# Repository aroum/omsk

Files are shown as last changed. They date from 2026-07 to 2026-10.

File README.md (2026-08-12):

# OMSK




OMSK is an experimental, pocket-sized hardware platform designed primarily (but not exclusively) for custom synthesizer firmware development. Built around the RP2350-Zero microcontroller module, OMSK packs an exceptional density of tactile controls, audio routing, and visual indicators into a highly portable footprint.

## Hardware Features

- **MCU:** RP2350-Zero module (or RP2040-Zero)
- **Controls:**
  - 4x4 matrix of Kailh Choc v2 mechanical switches (supports hot-swap sockets)
  - 4 rotary encoders (Alps EC12)
- **Display:** 128x64 OLED screen (supports SH1107 or SSD1312 via I2C)
- **Visuals:** 22 addressable RGB LEDs (WS2812B MINI-E) for parameter tracking and custom animations
- **Audio & Connectivity:**
  - Built-in mono PWM audio output (with optional onboard headphone amplifier circuit)
  - Classic hardware MIDI In/Out jacks (TRS Type A)
  - USB MIDI class-compliant device interface
  - Support for an optional external PCM5102 I2S DAC for high-fidelity stereo audio

For more details on assembly, schematic routing, and BOM, see the [Hardware PCB Guide](hardware/pcb/README.md) and [3D Case/Enclosure Design](hardware/case/README.md).

## Bare-metal Software

All official firmware is written in pure C/C++ using the native Raspberry Pi Pico SDK. There is no Arduino overhead and no RTOS, ensuring maximum CPU availability, bare-metal performance, and sub-millisecond audio and MIDI latency.

### Architecture

Rather than compiling a single monolithic application, OMSK uses separate firmware files for different applications. This separation is dictated by hardware memory limits and fundamental architectural differences:

- Synthesizer engines require different memory structures (e.g., flash space allocated for wavetables and filter LUTs vs. granular sample buffers).
- Audio paths, envelopes, and modulation matrices differ completely between engines.

All firmware targets share a unified low-level core library located in [firmware/shared](firmware/shared), but compile as independent binaries.

> [!NOTE]
> Each firmware folder contains its own documentation and parameter reference: see the respective `README.md` (e.g., [omsk_fm/README.md](firmware/omsk_fm/README.md)) and the `docs/` directory for detailed configuration options (e.g., [omsk_fm/docs](firmware/omsk_fm/docs)). Shared hardware pinouts and peripheral configurations are defined in [firmware/shared/hw_config.h](firmware/shared/hw_config.h) (see [firmware/shared/README.md](firmware/shared/README.md)).

### Firmwares

Explore the firmware directory at [firmware](firmware) to flash any of the following targets:

- **[omsk_wave](firmware/omsk_wave):** A polyphonic wavetable synthesizer featuring deep modulation routing, resonant filters, and non-volatile patch storage.
- **[omsk_grain](firmware/omsk_grain):** A 4-voice granular synthesizer offering real-time grain manipulation, modulation matrices, and full MIDI control.
- **[omsk_fm](firmware/omsk_fm):** An FM (Frequency Modulation) synthesizer engine.
- **[omsk_tracker](firmware/omsk_tracker):** A pocket music tracker and step sequencer to compose patterns and songs directly on the device. [planned]
- **DMK:** A customizable mechanical macropad firmware featuring full Vial compatibility. Remap keys, layout layers, macros, and rotary encoder actions directly from your web browser.
- **[omsk_midi](firmware/omsk_midi):** A simple demonstration firmware that configures the device as a class-compliant USB/TRS MIDI controller.
- **[omsk_oled_test](firmware/omsk_oled_test):** A diagnostic utility to test OLED display functionality, address configuration, and graphics rendering.

Both synth engines support full MIDI CC mapping and preset saving directly to the onboard non-volatile memory.

## Desktop Simulators & Tools

The [`desktop`](desktop) directory contains Python-based software simulators, hardware emulators, and firmware development utilities managed via [`uv`](https://github.com/astral-sh/uv):

- **[`desktop/grain_simulator`](desktop/grain_simulator):** PySide6 GUI simulation of the OMSK Granular Synth engine (`omsk_grain`).
- **[`desktop/synth_simulator`](desktop/synth_simulator):** PySide6 GUI simulation of the OMSK Analog/Wavetable Synth engine (`omsk_synth`).
- **[`desktop/synth_tools`](desktop/synth_tools):** Firmware LUT header generators, hardware emulators (128x64 OLED display, 4x4 matrix keypad), and interactive web testbenches.

Quick launch:

```bash
cd desktop
uv sync
uv run synth_simulator/main.py
```

For more details, see the [Desktop README](desktop/README.md).

## Roadmap & Status

This project is currently a work in progress.

- **Hardware:** Case and knob designs are being actively iterated.
- **Software:** A dedicated web-based editor using WebMIDI is planned to allow quick parameter tweaking, firmware updates, and preset backup/sharing.

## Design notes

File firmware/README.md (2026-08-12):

# Firmware Overview (`firmware`)

This repository contains the firmware source code for the OMSK hardware platform (RP2040 / RP2350 microcontrollers).

## Project Structure

- **`omsk_wave/`**: 4-voice hybrid polyphonic synthesizer firmware (wavetable, Moog filters, step sequencer, FX).
- **`omsk_fm/`**: 6-operator Frequency Modulation (FM) synthesizer firmware compatible with DX7 SysEx patches.
- **`omsk_grain/`**: 4-voice granular synthesizer firmware with custom sample engine.
- **`omsk_midi/`**: USB/Hardware MIDI interface and router firmware.
- **`omsk_oled_test/`**: Minimal test utility for I2C OLED display initialization, alignment, and u8g2 graphics driver verification (SSD1312 / SH1107).
- **`shared/`**: Common hardware drivers, pinout definitions (`hw_config.h`), library code, and submodules shared across all firmwares.

---

## Prerequisites & Dependencies

### System Dependencies

To compile firmware for RP2040 / RP2350, you need the ARM GCC toolchain along with the C standard library (`newlib`), CMake, and build tools.

#### macOS (Homebrew)

> [!IMPORTANT]
> Make sure to install `arm-none-eabi-newlib`. Without it, GCC will fail with `stdint.h: No such file or directory` error when compiling C standard headers.

```bash
brew install cmake ninja arm-none-eabi-binutils arm-none-eabi-gcc arm-none-eabi-newlib
```

#### Ubuntu / Debian

```bash
sudo apt update
sudo apt install cmake gcc-arm-none-eabi libnewlib-arm-none-eabi build-essential
```

### Submodules & Pico SDK

Before building any firmware, ensure the repository submodules (such as TinyUSB, u8g2, CMSIS-DSP, etc.) are fully initialized.

Clone with submodules:

```bash
git clone --recursive https://github.com/aroum/omsk.git
```

Or if you have already cloned the repository without submodules:

```bash
git submodule update --init --recursive
```

Make sure you have the **Pico SDK** installed and `PICO_SDK_PATH` set in your environment:

```bash
export PICO_SDK_PATH=/path/to/pico-sdk
```

---

## Memory & Binary Formats (`.uf2` vs `.bin` / `.elf`)

To synthesize high-quality audio, this project relies heavily on pre-calculated Look-Up Tables (LUTs), audio samples, and wavetables stored directly in Flash memory. As synth engines evolved (e.g. granular synthesis with PCM sample data), Flash memory space on the RP2350 Zero (4 MB limit, non-expandable due to compact QFN packaging and pin count constraints) became scarce.

Standard `.uf2` files add significant block header overhead (nearly doubling the file size compared to raw binaries). By switching from drag-and-drop `.uf2` flashing to flashing raw `.bin` or `.elf` binaries directly via [`picotool`](https://github.com/raspberrypi/picotool), **~1.4 MB of Flash space is freed up**, allowing almost **twice as many audio samples, LUTs, and wavetables** to fit into internal storage.

---

## Flashing & Tools

### Installing `picotool`

`picotool` allows flashing `.bin` and `.elf` binaries directly over USB without requiring drag-and-drop or external HW debuggers.

#### macOS

```bash
brew install picotool
```

#### Ubuntu / Debian

```bash
sudo apt install picotool
```

---

## Building & Flashing

Each firmware folder contains its own dedicated build script (`build_all.sh`) supporting clean builds, memory analysis, platform selection (`rp2040` / `rp2350`), and automated flashing via `picotool`.

### Option 1: Flashing via `build_all.sh` (Recommended)

Run the script with the `-f` (or `--flash`) flag. The script will automatically trigger a soft reboot to BOOTSEL mode via USB CDC (1200 baud) and upload the `.bin` binary:

```bash
cd firmware/omsk_wave
./build_all.sh -p rp2350 -c -s -f
```

#### Script Flags & Options:

- `-c`, `--clean`: Remove build directory and re-run CMake configuration from scratch.
- `-s`, `--size`: Print detailed Flash and RAM memory usage report after build.
- `-p <platform>`: Target MCU platform (`rp2040` or `rp2350`, default is `rp2350`).
- `-f`, `--flash`: Flash binary directly to connected device using `picotool`.

### Option 2: Flashing Manually via `picotool`

1. Connect your RP2040 / RP2350 board in **BOOTSEL mode** (hold the `BOOT` button while plugging in USB, or press `RESET` while holding `BOOT`).
2. Flash the binary file (`.bin` or `.elf`) and automatically execute/reboot:

```bash
# Flash .bin file and execute
picotool load build_rp2350/omsk_wave.bin -u

# Or flash .elf file directly
picotool load build_rp2350/omsk_wave.elf -u
```

---

### Build & Flash Examples

Build **`omsk_wave`** for RP2350 and flash to hardware:

```bash
cd firmware/omsk_wave
./build_all.sh -p rp2350 -c -s -f
```

Build **`omsk_fm`** for RP2040 and flash:

```bash
cd firmware/omsk_fm
./build_all.sh -p rp2040 -s -f
```

Build **`omsk_grain`** for RP2350:

```bash
cd firmware/omsk_grain
./build_all.sh -p rp2350 -c -s
```

Build **`omsk_midi`**:

```bash
cd firmware/omsk_midi
./build_all.sh -p rp2350 -c -s
```

Build OLED display test utility:

```bash
cd firmware/omsk_oled_test
./build.sh
```

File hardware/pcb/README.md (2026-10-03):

# PCB

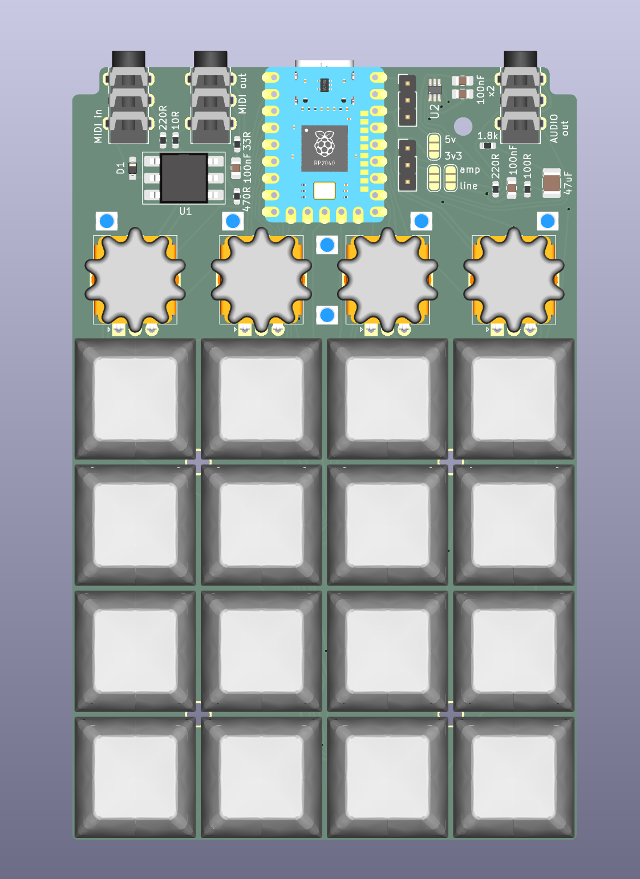
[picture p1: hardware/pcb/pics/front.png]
front

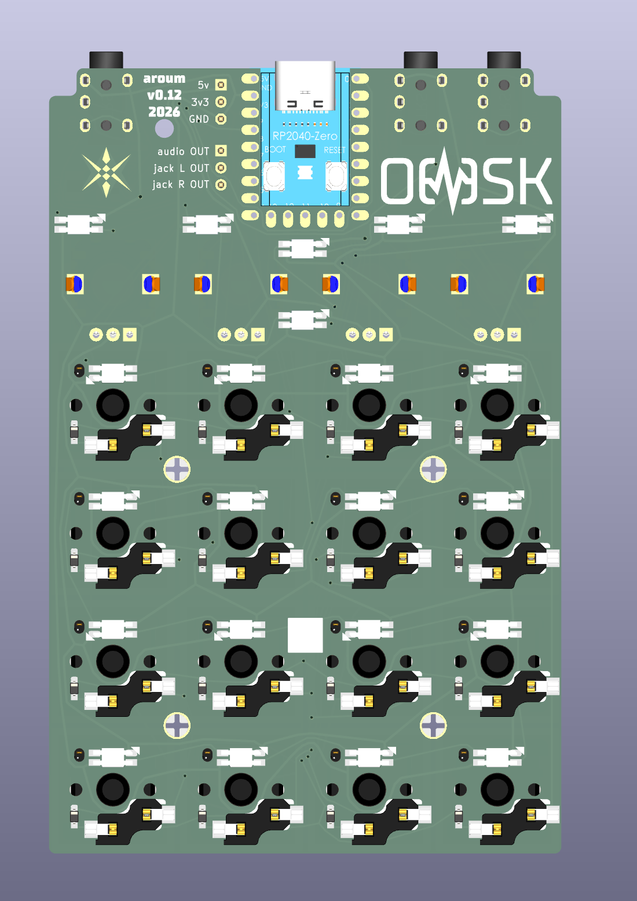
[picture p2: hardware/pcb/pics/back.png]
back


## BOM

### Basic

| name |  pcs | type | package | position | description |
| --- | ---: | --- | --- | --- | --- |
| 1N4148W | 17 | Diode | SOD-323 | D1 - D17 | keyboard matrix + MIDI |
| 100nF x7r 50v | 4 | Capacitor | 0805 | C1, C3, C4, C5 | MIDI jacks + PWM Audio |
| 47uF x7r 50v | 1 | Capacitor | 1210 | C2 | PWM audio |
| 10R for 3v3 or 220 Ohm for 5v out | 1 | Resistor | 0603 | R4 | MIDI jacks |
| 33R for 3v3 or 220 Ohm for 5v out | 1 | Resistor | 0603 | R3 | MIDI jacks |
| 100R | 1 | Resistor | 0603 | R6 | PWM audio |
| 220R | 2 | Resistor | 0603 | R1, R5 | PWM audio + MIDI jacks |
| 470R | 1 | Resistor | 0603 | R2 | MIDI jacks |
| 1.8k | 1 | Resistor | 0603 | R7 | PWM audio |
| PJ-313 (3 color) | 3 | jack sockets  | THD | J2, J3, J4 | Audio + MIDI jacks |
| Alps EC12 8.5 mm | 4 | Encoder | THD | ROTENC1 - ROTENC4 | Encoder for more info view below |
| H11L1 SMD | 1 | Optocoupler | SOP-6 | U1 | MIDI jacks |
| Kailh choc sockets | 16 | Switch socket | SMD | SW1 - SW16 | keyboard |
| Kailh choc v2 | 16 | Switch | THD | SW1 - SW16 | keyboard |
| NC7WZ16P6X | 1 | IC | SC-70-6 | U2 | MIDI jacks + PWM audio |
| rp2040/rp2350 zero | 1 | MCU | Module  | MCU1 | MCU (rp2350 recomended) |
| WS2812B MINI-E | 22 | RGB LED | 3228SMD | LED1 - LED22 | WS2812B MINI-E |

#### Encoders

You can choose any one of the following encoder models:

| name | torque | # of detent/pulses | description |
| --- | --- | ---: | --- |
| EC12E1220301 | Standard 3 to 20mN･m | 12 | |
| EC12E1240301 | Lightest (jog) 3±2mN･m | 12 | |
| EC12E2420301 | Standard 3 to 20mN･m | 24 | recommended |
| EC12E2440301 | Lightest (jog) 3±2mN･m | 24 | recommended |

### Extra

| name |  pcs | type | package | description |
| --- | ---: | --- | --- | --- |
| MIDI cable (DIN5 M to jack 3.5) | 1 | Cable | Cable | TRS to DIN5 MIDI cable (Type A) for use external MIDI hardware |
| YS-SK6812MINI-E | 22 | RGB LED | 3228SMD | RGB LEDs |

#### OLED

You can choose any one of the following display models:

| name | pcs | type | package | description |
| --- | --- | --- | --- | --- |
| TZT 1.3" OLED 64×128 i2c SSD1312 | 1 | Display | Module  | |
| TZT 1.3" OLED 64×128 i2c SH1107  | 1 | Display | Module  | recommended |

##### Pins

| Module pin | MCU pin |
| --- | --- |
| **GND** | GND |
| **VCC** | 3.3V |
| **SDA** | GPIO20  |
| **SCL** | GPIO21  |

#### Headphone amp

Formally, you should not connect headphones directly to the DAC or PWM output without an amplifier; however, in practice, it works fine directly, making an amplifier highly optional. If you decide to use one, you can choose any of the following headphone amplifier models:

| IC | mW | size  | price | description |
| --- | ----- | ----- | ----- | --- |
| TPA6132 | 25 | S | 90 | |
| TDA1308 | 40-80 | S | 71 | |
| MAX4410 | 80 | M | 157 | |
| MAX97220 +++ | 125 | 20x24 | 225 | tested |
| OPA1622 | 145 | L | 113 | |
| LM4881 | 150 | M | 60 | |
| TPA6112 & SGM4812 | 150 | M | 183 | |

#### DAC

GY-PCM5102 I2S PCM5102A module

##### Pins

| Module pin | MCU pin / Connection |
| --- | --- |
| **GND** | GND |
| **VCC** | 5V |
| **BCK** | GPIO17 |
| **LRCK** | GPIO18 |
| **DIN** | GPIO19 |
| **SCK** | GND (solder jumper next to SCK pin or wire to GND) |

## Build guide

- Solder all components starting from the lowest profile to the highest in the following order:
  - Diodes
  - Hotswap sockets
  - RGB LEDs
  - For NC7WZ16P6X (U2): the Pin 1 indicator on the IC consists of two dots on the bottom side (where the leftmost dot marks Pin 1), which aligns with the silkscreen tick mark on the PCB footprint.
  - Resistors
  - Capacitors
  - Jacks (recommended colors: green for MIDI IN, yellow for MIDI OUT, black for Audio OUT)
  - H11L1 (U1): the Pin 1 indicator on the IC is a dot on the bottom side, which aligns with the silkscreen tick mark on the PCB footprint.
  - Encoders
  - Solder two jumpers on the board to the `LINE` position (if you plan to use PWM audio).
  - Solder the `5V/3V3` jumper to the required position. This jumper controls the supply voltage of the NC7WZ16P6X (U2) IC. This affects the voltage of the MIDI OUT jack (for 5V, you must change resistors R3-R4 to 220 Ohm) and the PWM audio output level (5V increases the volume significantly, but might introduce noise from the USB power line).
- Connect external modules if needed:
  - **DAC**
    - Solder the jumpers on the back of the module: 1L, 2L, 3H, 4L
    - Solder the jumper bridge next to the SCK pin on the module (bridges SCK to GND to enable internal PLL for 3-wire I2S)
    - Desolder or cut off the audio jack from the module, as it takes too much space and won't fit in the case.
    - Connect using wires:
      - GND on the module to GND on the PCB
      - LOUT on the module to JACK L OUT on the PCB
      - ROUT on the module to JACK R OUT on the PCB
      - VIN to 5V
      - LRCK to GPIO18
      - DIN to GPIO19
      - BCK to GPIO17
      - Solder two jumpers on the board to the `AMP` position
  - **OLED**
    - GND to GND
    - VCC to 3.3V
    - SDA to GPIO20
    - SCL to GPIO21
  - **Headphone amp**
    - GND
    - VCC to 3.3V
    - L- to GND
    - R- to GND
    - L+ to the audio source PWM/DAC LEFT CHANNEL
    - R+ to the audio source PWM/DAC RIGHT CHANNEL
    - LOUT to the audio jack OUT LEFT CHANNEL
    - ROUT to the audio jack OUT RIGHT CHANNEL
    - Solder two jumpers on the board to the `AMP` position
- Assemble the device into the case
- Flash the required firmware

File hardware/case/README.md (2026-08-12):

# Case

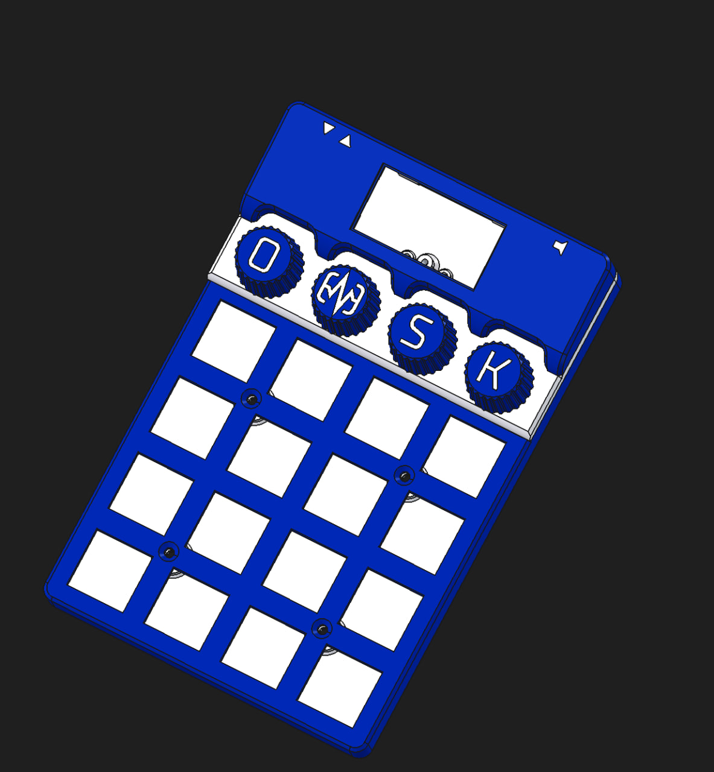
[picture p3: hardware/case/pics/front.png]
front

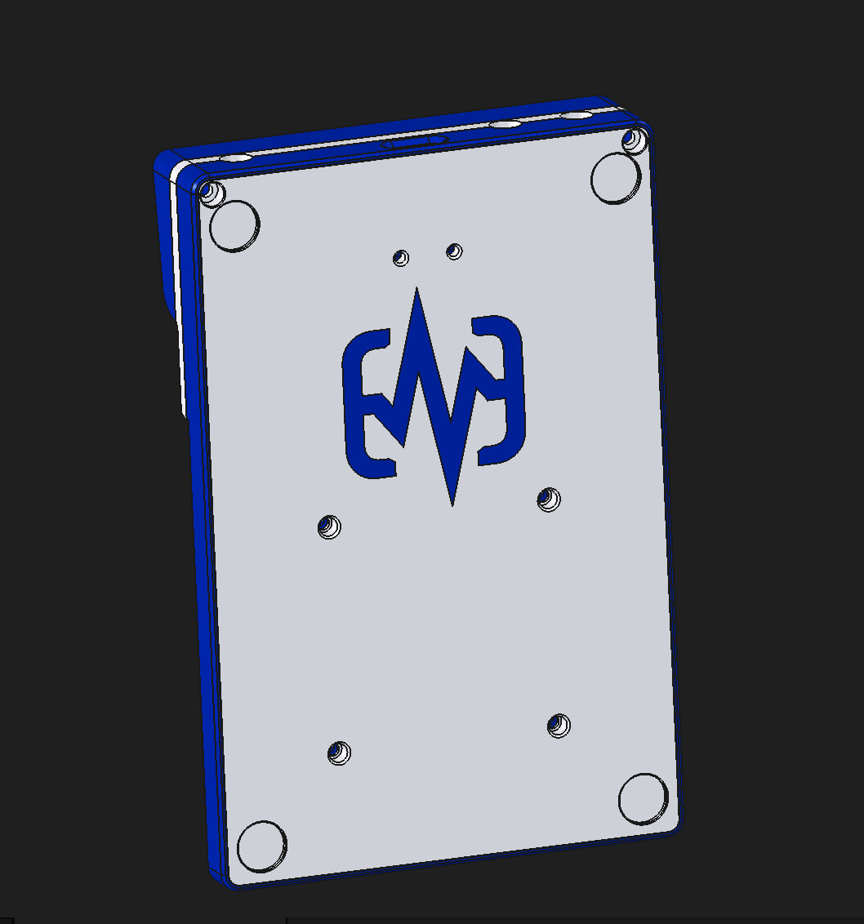
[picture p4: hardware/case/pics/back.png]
back


## BOM

| Item # | Description | Specification / Standard | Qty | Unit | Notes |
| --- | --- | --- | --- | ---- | --- |
| 1 | M2 x 8mm Countersunk Head Screw | DIN 965 / ISO 14581 (Flat Head) | 4 | pcs  | Countersunk |
| 2 | M2 x 10mm Button Head Screw | ISO 7380 (Button/Truss Head) | 2 | pcs  | Flat Head |
| 3 | M2 Heat-Set Threaded Insert | OD: 3.2mm, Height: 3.0mm | 6 | pcs  | For plastic integration |
| | Total Parts: | | 12  | pcs  | |

## 3D Printing & Models

The case is originally designed for multi-color 3D printing (`-mc` suffix), but it can also be printed in a single color without any issues.

To print a complete case, you will need all of the parts listed below, except you only need to choose **one of the two** info panel variants:

- **Info Panel Options (Choose one):**
  - [infopanel-omsk-rounded-mc.step](infopanel-omsk-rounded-mc.step) — Features a rounded border/bezel design around the encoders.
  - [infopanel-omsk-ledsvisible-mc.step](infopanel-omsk-ledsvisible-mc.step) — Features a different bezel shape around the encoders to keep the LEDs visible.

### Parts List

- [bot-omsk-mc.step](bot-omsk-mc.step) — Bottom shell
- [top-omsk.step](top-omsk.step) — Top shell
- [top-encoders-panel-omsk.step](top-encoders-panel-omsk.step) — Top panel for encoders
- [infopanel-omsk-screen-clip.step](infopanel-omsk-screen-clip.step) — Clip to secure the screen
- [knob-K-mc.step](knob-K-mc.step) — "K" knob
- [knob-M-mc.step](knob-M-mc.step) — "M" knob
- [knob-O-mc.step](knob-O-mc.step) — "O" knob
- [knob-S-mc.step](knob-S-mc.step) — "S" knob

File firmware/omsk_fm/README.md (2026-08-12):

# Omsk FM Synthesizer

Omsk FM is a 6-operator Frequency Modulation (FM) synthesizer firmware designed for RP2350/RP2040 microcontrollers. It offers a maximally close digital reproduction of the classic Yamaha DX7 engine. The folder structure, build system, and hardware UI framework are aligned with the `omsk_wave` synthesizer codebase.

### Origin & Codebase

The **Omsk FM** project was written almost from scratch specifically for the Raspberry Pi Pico architecture (dual-core pipeline with oversampling).

- **Connection to Dexed**: Only the graph structure array (coordinate array) for rendering algorithm schemes on the OLED screen was borrowed from [Dexed](https://github.com/asb2m10/dexed). Omsk FM also supports the SysEx bank format produced by Dexed (for easy patch loading).
- **Connection to picoX7 / Ken Shirriff**: The codebase is _not_ a fork of [picoX7](https://github.com/SloeComputers/picoX7). However, to achieve bit-accurate DX7 sound, Omsk FM uses **decoded YM21280 ROM tables** (sine, log, and envelope step tables) obtained by [Ken Shirriff](https://www.righto.com/) via chip reverse-engineering, adapted by John D. Haughton in the picoX7 project.

---

## Synthesizer Engine Architecture

The core synthesis engine simulates the exact parameters, routing, and modulation structures of the Yamaha DX7.

### 1. Six Operators (OP1 - OP6)

Each operator consists of:

- **Oscillator**: Digital sine wave oscillator.
  - **Frequency Mode**: Ratio (0.50 to 31.99) or Fixed Frequency (1.000 Hz to 9772 Hz).
  - **Coarse/Fine Adjustments**: Coarse tuning (0 to 31) and fine tuning (0 to 99).
  - **Detune**: Detunes the operator frequency by -7 to +7 steps.
- **Envelope Generator (EG)**: 4 Rates ($R_1, R_2, R_3, R_4$) and 4 Levels ($L_1, L_2, L_3, L_4$).
- **Keyboard Level Scaling**: Modifies the output level based on the midi key played.
  - **Break Point (BPT)**: Center key (0 to 99, representing C-1 to G9; C3 is 39).
  - **Left/Right Depth**: Scaling depth (0 to 99) applied to the left and right of the break point.
  - **Left/Right Curves**: Negative Linear (`-LIN`), Negative Exponential (`-EXP`), Positive Exponential (`+EXP`), or Positive Linear (`+LIN`).
- **Keyboard Rate Scaling**: Scales envelope rates based on key pitch (0 to 7).
- **Sensitivity**:
  - **Key Velocity Sensitivity (KVS)**: Response of operator output level to note velocity (0 to 7).
  - **Amplitude Modulation Sensitivity (AMS)**: Sensitivity to LFO/EG bias modulation (0 to 3).
- **Output Level**: Base output level of the operator (0 to 99).

### 2. Algorithms & Feedback

- **32 Algorithms**: The 6 operators can be routed in 32 classic algorithms mapping modulators and carriers.
- **Feedback Loop**: A configurable feedback loop (0 to 7) applies self-modulation to a designated operator in each algorithm.
- **Oscillator Sync**: Configurable global key-sync for oscillators.

### 3. Pitch Envelope Generator (Pitch EG)

- Global envelope generator modulating the master pitch of all operators.
- Uses 4 Rates ($R_1, R_2, R_3, R_4$) and 4 Levels ($L_1, L_2, L_3, L_4$).

### 4. Low Frequency Oscillator (LFO)

- **Speed**: LFO rate (0 to 99).
- **Delay**: Fade-in delay (0 to 99).
- **Pitch Modulation Depth (PMD)**: Pitch modulation amount (0 to 99).
- **Amplitude Modulation Depth (AMD)**: Amplitude modulation amount (0 to 99).
- **LFO Sync**: Key-sync LFO phase reset (on/off).
- **Waveforms**: Triangle, Saw Down, Saw Up, Square, Sine, and Sample & Hold.

---

## Operating Modes

Switching between operating modes is done by **simultaneously pressing OCT↓ and OCT↑** (buttons 13 and 14 in Piano mode, or **MIXER** and **FX2** in PARAMS mode).

### Piano Mode (Play Mode)

This is the default mode when powering on the device.

By default, the following matrix note layout is active on the 4x4 matrix:

| enc1 | enc2 | enc3 | enc4 |
| ---- | ---- | ---- | ---- |
| C | D# | F# | A |
| C# | E | G | A# |
| D | F | G# | B |
| OCT↓ | OCT↑ | ARP  | ADV  |

> [!NOTE]
> You can customize and change the physical key layout using configuration parameters. For details, see [Key Layout Settings in config.md](docs/config.md#1-hardware-sharing-options).

- **Encoders 1-4**: Control parameters of the last selected module.
- **Keys 1-12 (Rows 1-3)**: Keyboard. Play chromatic scale notes (C, C#, D... B).
- **Button 13 (Bottom row, 1)**: OCT↓ (Octave Down).
- **Button 14 (Bottom row, 2)**: OCT↑ (Octave Up).
- **Button 15 (Bottom row, 3)**: ARP (Arpeggiator).
- **Button 16 (Bottom row, 4)**: ADV (Advanced).

- **OCT↓ + OCT↑** > Switch to PARAMS/Setup Mode
- **OCT↓ + ADV** > Cycle Key for scale snapping
- **OCT↑ + ARP** > Toggle HOLD
- **ARP + ADV** > Toggle SEQ Mode
- **LFO1 + EG1** (Pads 2+3 in Params mode) > PRESET Mode (Hold for Save, Tap for Load)

#### LED Feedback (Piano Mode)

LEDs under matrix buttons show keyboard layout and control state:

- **White keys** (C, D, E, F, G, A, B): Soft white low brightness. Bright white on key press or MIDI note.
- **Black keys** (C#, D#, F#, G#, A#): Dim blue/cyan low brightness. Bright blue/cyan on key press or MIDI note.
- **OCT↓ and OCT↑ buttons**: Purple. Color shifts with octave transpose (more blue down, more red up), bright purple on press.
- **ARP and ADV buttons**: Dim orange. Bright orange when corresponding layer/mode is active.

#### ARP Section

| Rate | Mode | Swing | Octave |
| ---- | ---- | ----- | --- |
| C | D# | F# | A |
| C# | E | G | A# |
| D | F | G# | B |
| OCT↓ | OCT↑ | PIANO | ADV |

##### Ranges

| Module | Min | Max  | Unit | Mapping / Formula (0..127) |
| --- | --- | ---- | ---- | --- |
| Rate | 1/64 | 1/1  | -- | |
| Mode | OFF | DRNK | ---  | OFF, UP, DOWN, UP-DN, RND, DRNK |
| Swing  | OFF/50 | 75 | % | SIN>TRI>SAW>RSAW>SQR>PWM>PAM4 |
| Octave | -3 | +3 | oct  | |

#### ADV Section

In ADV mode (selected via ADV button), the interface shifts to global settings:

| Tempo | Scale | Chord | MIDI  |
| ----- | ----- | ----- | ----- |
| C | D# | F# | A |
| C# | E | G | A# |
| D | F | G# | B |
| OCT↓  | OCT↑  | Key | PIANO |

- **Pads 1-12**: Set Scale Key (C, C#, D... B)
- **Pad 16 (ADV/PIANO)**: Return to Piano Mode

##### Tempo

- Off sync
- External sync
- 30
- 31
- …
- 300

###### Sync behaviour

When SYNC is enabled, time-based parameters are tied to musical beats and are specified as fractional parts of a beat (for example: 1/1 = whole note, 1/2 = half note, 1/4 = quarter note, 1/8 = eighth note, 1/8t = eighth-note triplet, etc.). The following knobs/parameters become beat-synced and accept sync-notation instead of absolute time:

- `Tempo` (global BPM reference)
- `ARP > Rate`
- `LFO1 > Rate` and `LFO2 > Rate` (LFO frequency is expressed as a fraction of a beat in SYNC mode)
- `GLIDE > Time`
- `FX1 (Delay) > Time`
- `EG1/EG2 > Attack`, `EG1/EG2 > Decay`, and `EG1/EG2 > Release` (envelope times are interpreted as beat fractions in SYNC mode). `Sustain` remains a level/percentage and is not beat-synced.

In SYNC mode the LFO frequency is also specified as a fraction of the beat (e.g. `1/4` = one cycle per quarter note). Triplet and dotted divisions from the `Sync MODE` list are supported.

####### Sync range

- 8/1
- 8/1t
- 4/1
- 4/1t
- 1/1
- 1/1t
- 1/2
- 1/2t
- 1/4
- 1/4t
- 1/8
- 1/8t
- 1/16
- 1/16t
- 1/32
- 1/32t
- 1/64
- 1/64t

##### Scales (MIDI Note Scale Quantizer)

- OFF / Chromatic / Thru Mode
- Major
- Minor
- Harmonic Minor
- Melodic Minor
- Dorian
- Locrian
- Lydian
- Blues
- Major Pentatonic
- Minor Pentatonic
- Augmented

##### Chords (Polyphonic Note Expansion)

When Chord mode is active, pressing a single note triggers additional notes to form a chord.

| **Category** | **Full Name** | **Abbr**  | **Intervals (semitones)** | **Description** |
| --- | --- | --- | --- | --- |
| **Basic** | OFF | **OFF** | 0 | No chord expansion |
| **Intervals**  | Minor 2nd | **m2** | 0, 1 | Minor second |
| | Major 2nd | **M2** | 0, 2 | Major second |
| | Minor 3rd | **m3** | 0, 3 | Minor third |
| | Major 3rd | **M3** | 0, 4 | Major third |
| | Perfect 4th | **P4** | 0, 5 | Perfect fourth |
| | Tritone | **Tri** | 0, 6 | Tritone |
| | Perfect 5th | **P5** | 0, 7 | Perfect fifth |
| | Minor 6th | **m6** | 0, 8 | Minor sixth |
| | Major 6th | **M6** | 0, 9 | Major sixth |
| | Minor 7th (Int) | **m7i** | 0, 10 | Minor seventh (interval) |
| | Major 7th (Int) | **M7i** | 0, 11 | Major seventh (interval) |
| | Octave | **Oct** | 0, 12 | Octave |
| **Triads** | Major | **M** | 0, 4, 7 | Major triad |
| | Minor | **m** | 0, 3, 7 | Minor triad |
| | Diminished | **Dim** | 0, 3, 6 | Diminished triad |
| | Augmented | **Aug** | 0, 4, 8 | Augmented triad |
| | Suspended 2 | **Sus2**  | 0, 2, 7 | Suspended 2nd |
| | Suspended 4 | **Sus4**  | 0, 5, 7 | Suspended 4th |
| **7th Chords** | Major 7th | **M7** | 0, 4, 7, 11 | Major 7th chord |
| | Dominant 7th | **Dom7**  | 0, 4, 7, 10 | Dominant 7th chord |
| | Minor 7th | **m7** | 0, 3, 7, 10 | Minor 7th chord |
| | Half-Diminished | **m7b5**  | 0, 3, 6, 10 | Half-diminished 7th |
| | Diminished 7th  | **Dim7**  | 0, 3, 6, 9 | Diminished 7th |
| | Minor-Major 7th | **mM7** | 0, 3, 7, 11 | Minor-major 7th |
| | Augmented-M 7th | **AugM7** | 0, 4, 8, 11 | Augmented major 7th |
| | Augmented 7th | **Aug7**  | 0, 4, 8, 10 | Augmented 7th |
| **Extended** | Major 6th | **M6** | 0, 4, 7, 9 | Major 6th chord |
| | Minor 6th | **m6** | 0, 3, 7, 9 | Minor 6th chord |
| | Add 9 | **Add9**  | 0, 4, 7, 14 | Major add 9 |
| | 7th Sus 4 | **7s4** | 0, 5, 7, 10 | 7th suspended 4th |
| | M 7th Sus 4 | **M7s4**  | 0, 5, 7, 11 | Major 7th suspended 4th  |
| **Advanced** | 7 Sharp 5 | **7#5** | 0, 4, 8, 10 | Dominant 7 sharp 5 |
| | 7 Flat 5 | **7b5** | 0, 4, 6, 10 | Dominant 7 flat 5 |
| | Quartal | **Quart** | 0, 5, 10, 15 | Quartal stack |
| | Lydian | **Lyd** | 0, 4, 6, 7 | Lydian chord (#4) |

### Param

The 4x4 button matrix defines parameter editing pages:

| | | | |
| :--- | :--- | :--- | :--- |
| Freq | LVL&MOD  | LFO | EG |
| KBDscale | Filt [G] | Algo & FB [GS] | PitchEG [G] |
| OP1 | OP2 | OP3 | MEM |
| OP4 | OP5 | OP6 | Sys |

#### Page Logic and Parameter Navigation

1. **Operator Local Parameters (Local)**:
   - **Freq**, **LVL&MOD**, **LFO**, **EG**, **KBDscale** — apply to currently selected operator (OP1..OP6).
2. **Global Parameters (Global)**:
   - **Filt [G]** (Filter), **PitchEG [G]** (Pitch Envelope) — global settings across the patch.
   - **Algo & FB [GS]** (Algorithm and Feedback) — global algorithm routing setup.
3. **Enabling / Disabling Operators**:
   - Double tapping an operator button (**OP1..OP6**) toggles (mutes/unmutes) that operator in the active algorithm.
4. **Dual-Page Parameter Switching**:
   - Parameters containing 2 pages (marked `[2]`, e.g., EG, Keyboard Scaling, LFO, Pitch EG, Filt) switch pages on consecutive button presses.
   - Pressing a parameter button for the first time opens Page 1.
   - Example: Press **EG** -> Page 1 (Lvl) opens. Press **EG** again -> Page 2 (rate) opens. Press **LFO**, then **EG** again -> Page 1 (Lvl) opens.

## Memory

- Mode (Load/Save)
- Cartridge number (1-32)
- Slot number (1-32)
- Prog (1-32) — instant patch switching in RAM. Useful for navigating banks after MIDI SysEx load.

## System

- Transpose
- Monophonic Mode (On|off)
- MIDI CH 1-16
- BPM

## Filt

- Tune
- Cutoff
- Resonance
- Level

### 2/2

## Frequency

- Mode (Ratio / Fixed): Frequency mode (harmonic ratio or fixed frequency in Hz).
- Tune
- Coarse
- Fine

## Levels & Modulation

- Level: Base output level of operator.
- A Mod Sens (Amplitude Modulation Sensitivity): LFO modulation sensitivity on operator amplitude.
- Key Vel (Keyboard Velocity Sensitivity): Velocity response of operator output level.

---

## EG [2]

### 1/2 (Lvl)

- (1, 2, 3, 4): Envelope target level values.

### 2/2 (rate)

- (1, 2, 3, 4): Envelope rate/time values between levels.

## Keyboard Scaling [2]

### 1/2 (Left)

Parameters modifying operator behavior based on key pitch:

- L Depth
- L Curve
- Breakpoint: Key note where scaling begins.
- Rate Scaling: Envelope speed scaling based on pitch (higher notes decay faster).

### 2/2 (Right)

- R Depth: Level depth left and right of breakpoint.
- R Curve: Curve shape (linear, exponential, etc.) left and right of breakpoint.
- Breakpoint: Key note where scaling begins.
- Rate Scaling: Envelope speed scaling based on pitch.

## Algorithm & FB [G]

- Feedback: Feedback level (typically on OP6 or operator chain) for noise and harsh saw timbres.
- Algorithm: Choice of 32 operator routing schemes (defines carriers vs modulators).

## LFO [2]

### 1/2

- Wave: LFO waveform (triangle, saw down, saw up, square, sine, sample & hold).
- Speed: LFO rate/speed.
- Delay: Fade-in delay after key press.
- P Mod Sens (Pitch Modulation Sensitivity): Overall pitch modulation sensitivity.

### 2/2

- PMD (Pitch Modulation Depth): Pitch modulation depth (vibrato).
- AMD (Amplitude Modulation Depth): Amplitude modulation depth (tremolo).
- LFO Key Sync: Sync LFO phase to key press (On/Off).
- OSC Key Sync: Sync main oscillator phases on key press (On/Off).

## Pitch EG [2]

Controls overall pitch changes over time:

### 1/2

- Pitch EG Level (1, 2, 3, 4): Pitch offset target levels.

### 2/2

- Pitch EG Rate (1, 2, 3, 4): Rates/times between pitch levels.

## Seq

Plays specified notes in a loop. Up to 64 steps (16 steps * 4 pages). Each page has its RGB LED color (green, blue, purple, orange). Muted step glows at 5% brightness.

### Play steps

| Speed | Swing | Mode  | note length |
| ----- | ----- | ----- | --- |
| STP1  | STP2  | STP3  | STP4 |
| STP5  | STP6  | STP7  | STP8 |
| STP9  | STP10 | STP11 | STP12 |
| STP13 | STP14 | STP15 | STP16 |

#### UI

| Speed | Swing | Mode | Len  |
| ----- | ----- | --- | ---- |
| page  | step  | play/pause | slot |
| 1/4 | 1/64  | play/pause | 1/16 |

##### Color Scheme & Indication Logic (v2)

###### 1. Step Status (16 Matrix Pads)

- **Empty Step:** Off (Black).
- **Active Step (Trig):** Green (if cycle condition 2/4/8 is currently met).
- **Standby Step:** Yellow (if cycle condition 2/4/8 is NOT currently met).
- **Mute:** Pink.
- **Stop Step (Sequence End):** Red.
- **Current Step (Playhead):** White (overlaid on top with max brightness).

###### 2. Probability

Brightness defines triggering probability (for Green, Yellow, Pink):

- **100%:** Max brightness (255).
- **75-85%:** High brightness (190-210).
- **40-50%:** Medium brightness (110-130).
- **10-25%:** Low brightness (40-70).
- **0%:** Step becomes visually black.

###### 3. Status LEDs (2 RGB LEDs)

####### LED 3: Transport Status (Play/Pause)

- **Play:** Solid Green.
- **Pause/Stop:** Red (or Orange).

####### LED 4: Navigation (Pages 1-4)

- **Page 1 (1-16):** Red.
- **Page 2 (17-32):** Green.
- **Page 3 (33-48):** Blue.
- **Page 4 (49-64):** Purple.

###### Layering Priority

Evaluate LED color conditions in this exact order:

1. **Cursor:** If `current_step == LED_index`, color = **WHITE (MAX)**.
2. **Stop:** If `step == stop_step`, color = **RED**.
3. **Mute:** If `is_muted`, color = **PINK** (brightness = Probability).
4. **Loop Condition:**
   - If cycle condition matches, color = **GREEN** (brightness = Probability).
   - If cycle condition does NOT match, color = **YELLOW** (brightness = Probability).
5. **Default:** If step inactive, color = **BLACK**.

#### Play Mode Descriptions

- **Forward** (UP): plays steps 1→2→3→...→16→1 sequentially
- **Backward** (DOWN): plays steps in reverse 16→15→14→...→1→16
- **Pingpong** (UP-DN): plays forward 1→16, then immediately backward 16→1
- **Snake** (SNK): plays in a serpentine pattern across 4x4 grid (1→2→3→4→8→7→6→5→9→10→11→12→16→15→14→13)
- **Random** (RND): selects a random step on each beat
- **Drunk**: random walk — moves to an adjacent step (±1) on each beat

STP"X" > Mute step — Disables playback for specified step

#### Chords

| Chord | Action | Notes |
| --- | --- | --- |
| STP"X" > + Speed enc | probability | |
| STP3+STP4 | Load/Save seq | STP3+STP4 > 1-16 key > load 1-16 preset |
| STP5+STP9 | Prev page | |
| STP8+STP12 | Next page | |
| STP13+STP14 | Param | |
| STP15+STP16 | PIANO mode | |
| STP10+STP11 | Play/Pause | Play/Pause sequence playback |
| STP14+STP15 | Stop step | Sets a stop flag on the beat. If flags are set on steps 5, 8 and 9, only steps 1-4 are played |
| STP1+STP2 | Edit step | Enter edit mode for the specified step |
| STP13+STP16 | Copy mode | STP1.Down>STP2.Down>STP2.Up>STP1.Down>source step>target step |

#### Ranges

| Knob | Min  | Max | Unit | Note |
| --- | ---- | --- | ---- | --- |
| speed | 1/16 | 8 | x | |
| swing | off  | 75  | % | |
| mode | 1 | 8 | - | |
| note length | 0 | 100 | % | (0, 10, 25, 40, 50, 75, 85, 100) |

### Edit Mode

| VEL  | CHRD | Every | Prob |
| ---- | ---- | ----- | ---- |
| C | D | E | F |
| G | A | B | C# |
| D# | F# | G# | A# |
| OCT↓ | OCT↑ | Clear | Done |

#### Ranges

| Knob  | Min | Max | Unit | Note |
| ----- | --- | --- | ---- | --- |
| VEL | 0 | 127 | | velocity for the step |
| CHRD  | | | | |
| Every | 1 | 8 | - | play every loop, every 2.. every 8 |
| Prob  | 0 | 100 | % | Probability, (0, 10, 25, 40, 50, 75, 85, 100) |

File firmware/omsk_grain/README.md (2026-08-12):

# Granular Synthesizer

This project is a granular synthesizer with a 128x64 OLED display interface.

> **Acknowledgements & Inspiration:** Special thanks to the [pikocore](https://github.com/schollz/pikocore) project by schollz. It served as a great inspiration for this firmware, and its audio conversion workflows (converting audio files into C header files) were immensely helpful during development.

Samples are embedded into the firmware. They are pre-converted to mono and downsampled. Configurable parameters should be available in the config (bit depth, sampling rate).

## Buttons Layout

| row/col | col1 | col2 | col3 | col4 |
| --- | --- | --- | --- | --- |
| row1 | Grain 1 [V] | Grain 2 [V] | Grain 3 [V] | Filter[V] |
| row2 | Jitter [-] | LFO 1 [V] | LFO 2 [V] | EG [V] |
| row3 | Modulation [G] | FX [G] | Mix [G] | Sys[G] |
| row4 | Trigger 1 [-]  | Trigger 2 [-] | Trigger 3 [-] | Trigger 4 [-] |

- [V] - Per Voice
- [G] - Global
- [-] - None

## Knob Modulation

- 'JIT' - Random jitter
- 'LFO1' - LFO 1
- 'LFO2' - LFO 2
- 'EG+' / 'EG-' - Envelope Generator (positive/inverted)
- '---' - None
- 'XXX' - [no modulation]

## Screen layout

| page_name | - | - | VOICES |
| --- | --- | --- | --- |
| param_name_1 | param_name_2 | param_name_3 | param_name_4 |
| param_indicator_1 | param_indicator_2 | param_indicator_3 | param_indicator_4 |
| param_value_1 | param_value_2 | param_value_3 | param_value_4 |
| param_modulation_indicator_1 | param_modulation_indicator_2 | param_modulation_indicator_3 | param_modulation_indicator_4 |
| param_modulation_name_1 | param_modulation_name_2 | param_modulation_name_3 | param_modulation_name_4 |

## Page Details

### Grain 1 (Per Voice)

| # | enc 1 | enc 2 | enc 3 | enc 4 |
| --- | --- | --- | --- | --- |
| Short Name | SAMPLE | POSIT | SIZE | DENS |
| Full Name  | Sample selection | Position | Size | Density |
| Desc | Select sample from memory | Sample start point | Grain duration  | Frequency of grain Birth Rate |
| Range | 1:1: # of samples | 0:0.001:sample length in sec | 0.001:0.001:1.0 | 0.1:0.1:100 |
| Unit | | sec | sec | Hz |

### Grain 2 (Per Voice)

| # | enc 1 | enc 2 | enc 3 | enc 4 |
| --- | --- | --- | --- | --- |
| Short Name | PITCH | P.MODE | GRAINS | VOL_G |
| Full Name  | Grain Pitch | Pitch Mode | Max Grain Count | Grain Volume |
| Desc | Grain playback speed | | | Individual grain amplitude |
| Range | free: 0.1:0.1:4.0 | Free / Semitones / Octaves | 1:1:32 | 0:1:100 |
| | Sem -24:1:+24 | | | |
| | Oct -3:1:+3 | | | |
| Unit | X/Semitones/oct | --- | pcs | % |

### Grain 3 (Per Voice)

- **enc 3:** Stereo Spread — controls the pan width of grains.
  - 0% (Mono): All grains are routed to center (L: 100%, R: 100%).
  - 1–100%: Random panning of grains. Higher values widen the stereo field (up to hard separation: one grain fully in left channel, next in right).

| # | enc 1 | enc 2 | enc 3 | enc 4 |
| --- | --- | --- | --- | --- |
| Short Name | SCAN | REV | SPREAD | SHAPE |
| Full Name  | Scan Speed | Grain reverse direction | Stereo Spread | Grain Shape |
| Desc | Playhead movement | Probability of reverse playback | | Envelope selection from LUT: `grain_env.py` |
| Range | -2.0:0.01:+2.0 | 0:1:100 | 0:1:100 | 1:1:# of env |
| Unit | x | % | % | --- |

### Filter (Per Voice)

| # | enc 1 | enc 2 | enc 3 | enc 4 |
| --- | --- | --- | --- | --- |
| Short Name | CUT | RES | TYPE | KTRK |
| Full Name | Cutoff | Resonance  | Filter Type | Keytrack |
| Desc | Cutoff frequency | Q-factor | | Scaling based on MIDI note. Not working for trig1-4 |
| Range | 20Hz:log:16kHz | 0.5:0.1:13 | Off / LP / HP / BP | 0:1:100 |
| Unit | HZ/KHZ | --- | --- | % |
| 999HZ should become 1.00KHZ | | | | |

### EG (Per Voice)

Amplitude Envelope

See `eg.py`
For CURV use lut

| # | enc 1 | enc 2 | enc 3 | enc 4 |
| --- | --- | --- | --- | --- |
| Short Name | ATK | A.CURV | REL | R.CURV |
| Full Name  | Attack Time  | Attack Curve | Release Curve | Release Time  |
| Desc | | < 0 — convex (logarithmic); > 0 — concave (exponential) | | |
| Range | 0.0:0.01:5.0 | -1.0:0.1:+1.0 | 0.0:0.01:5.0  | -1.0:0.1:+1.0 |
| Unit | sec | --- | sec | --- |

### Sys (Global)

| # | enc 1 | enc 2 | enc 3 | enc 4 |
| --- | --- | --- | --- | --- |
| Short Name | YSCALE | V_MODE | CH | VOL_M |
| Full Name  | Y-Scale [no modulation] | Voice choice for MIDI notes [no modulation] | MIDI CH [no modulation] | Master Volume |
| Desc | Visualization Y-scale | | | |
| Range | Pitch / Pan | V1 / V2 / V3 / V4 / RR / RND / OCT | 1:1:16 | 0:1:100 |
| Unit | --- | --- | ch | % |

[SYS] + [TRIG1-4] > HOLD Voice 1-4

#### Voice choice

- V1/2/3/4 MONOPHONIC
- Round robin
- Random
- Octave based (oct1 notes for voice1, oct2 for voice2...)

#### Impact of MIDI Notes on Pitch

Played MIDI notes affect the pitch (playback speed) of generated grains according to the **Keytrack** parameter (`KEYTRK`, `PARAM_KEYTRACK`) of the corresponding voice:

- **Base Note**: Reference note is C4 (MIDI note 60). When playing C4, playback pitch remains original ($1.0x$).
- **Pitch Tracking**: When playing other notes, pitch multiplier for new grains is calculated exponentially:
  $$\text{pitch\_multiplier} = 2^{\text{keytrack} \cdot (N - 60) / 12}$$
  where $N$ is the MIDI note number, and $\text{keytrack}$ is the `KEYTRK` parameter from $0.0$ to $1.0$ ($0\%$ to $100\%$, default is $100\%$).
- **Integration with Voice Allocation Modes (`V_MODE`)**:
  - In **V1–V4** modes, MIDI notes transpose only the corresponding monophonic voice.
  - In **RR (Round Robin)** and **RND (Random)** modes, each MIDI note is dynamically bound to its voice, allowing full polyphonic chords. Each voice individually tracks the pitch of its assigned note.
  - In **OCT** mode, voices track notes in their respective octaves (Voice 1 tracks 1st octave, Voice 2 tracks 2nd, etc.).
- **Stabilizing Release Phase and Physical Buttons**:
  - When releasing a MIDI key, the voice enters Release phase (amplitude envelope decay), and `current_note` resets. To avoid a sudden pitch jump back to reference C4 during release, new grains continue to generate using the pitch of the **last note played on this voice** (`last_note`).
  - Front panel physical trigger buttons `TRIG 1–4` trigger the voice using the pitch of the **last played MIDI note** on it (or C4 if no MIDI notes have been played yet).

### FX (Global)

(See 'fx.py')

| # | enc 1 | enc 2 | enc 3 | enc 4 |
| --- | --- | --- | --- | --- |
| Short Name | FOLD | DNSMPL | BCRSH | MIX |
| Full Name  | Wavefold | Downsampling | Bit Crush | Mix |
| Desc | | | | dry/wet |
| Range | 0:1:100  | x1:1:x80 | 1:1:16 | 0:1:100 |
| Unit | % | x | bit | % |

### Mix (Global)

| # | enc 1 | enc 2 | enc 3 | enc 4 |
| --- | --- | --- | --- | --- |
| Short Name | VOL_1 | VOL_2 | VOL_3 | VOL_4 |
| Full Name  | Voice 1 Volume | Voice 2 Volume | Voice 3 Volume | Voice 4 Volume |
| Desc | | | | |
| Range | 0:1:100 | 0:1:100 | 0:1:100 | 0:1:100 |
| Unit | % | % | % | % |

### Mod (Global)

| # | enc 1 | enc 2 | enc 3 | enc 4 |
| --- | --- | --- | --- | --- |
| Short Name | M1.S>D | M1.DPH | M2.S>D | M2.DPH |
| Full Name  | Mod 1 Source > Destination | Mod 1 Depth | Mod 2 Source > Destination | Mod 2 Depth |
| Desc | | | | |
| Range | | 0:1:100 | Available FM/RM Routings | 0:1:100 |
| Unit | --- | % | --- | % |

#### Available FM/RM Routings

- FM1>2
- FM1>3
- FM1>4
- FM2>1
- FM2>3
- FM2>4
- FM3>1
- FM3>2
- FM3>4
- FM4>1
- FM4>2
- FM4>3
- RM1x2
- RM1x3
- RM1x4
- RM2x3
- RM2x4
- RM3x4

### LFO 1 & 2 (Global)

| # | enc 1 | enc 2 | enc 3 | enc 4 |
| --- | --- | --- | --- | --- |
| Short Name | RATE | WFM | PHASE | SYNC |
| Full Name  | Rate | Waveform | Start Phase | Sync Mode |
| Desc | LFO freq | LFO waveform type | Start phase | Start LFO with ... |
| Range | 0.1:0.1:40 | Sin/Tri/Saw/RSAW/S&H | 0:1:180 | V1/V2/V3/V4/ANY/FREE |
| Unit | Hz | --- | deg | --- |

### Jitter (Global)

| # | enc 1 | enc 2 | enc 3 | enc 4 |
| --- | ----- | ----- | ----- | ----- |
| Short Name | --- | --- | --- | --- |
| Full Name  | --- | --- | --- | --- |
| Desc | --- | --- | --- | --- |
| Range | --- | --- | --- | --- |
| Unit | --- | --- | --- | --- |

- Nothing, only for chord

## RGB LEDs

The synthesizer is equipped with 22 WS2812 RGB LEDs providing visual feedback on parameters, selected menu pages, button activity, and voices.

### Brightness Setting

The maximum brightness limit for LEDs is set in the configuration file `hw_config.h` using the `RGB_MAX_BRIGHTNESS` macro (value range `0` to `255`, default is set to `63` for comfortable glare-free lighting):

```c
#define RGB_MAX_BRIGHTNESS 63
```

### LED Assignments

#### 1. Encoder LEDs (1, 2, 5, 6)

Display current parameter value assigned to the corresponding physical encoder (1, 2, 3, and 4).

- **Scheme**: Uses a gradient from **Blue** (min value) to **Red** (max value) through **Purple** (cold-to-hot).
- LEDs show values only for active parameters on the currently selected page. If no parameter is assigned to the encoder, the LED turns off.

#### 2. Page Mode LEDs (3, 4)

Display currently active page. Color matches the corresponding button color (see below).

#### 3. Page Selection Button LEDs (7-18)

Correspond to menu buttons from `BTN_GRAIN1` to `BTN_SYS`.

- **Page Colors**:
  - **Grain 1-3** — green, dark green, light green (7,8,9)
  - **Filter** — blue (10)
  - **Jitter** — yellow (11)
  - **LFO 1-2** — pink (12,13)
  - **EG** — orange (14)
  - **Modulation** — cyan (18)
  - **FX** — light blue (17)
  - **Mix** — purple (16)
  - **Sys** — white (15)
- **Behavior**: In idle mode, buttons glow dimly (15% of max brightness). When pressed, the corresponding LED lights up to full brightness.

#### 4. Voice LEDs (19-22)

Show status and activity of the four synthesizer voices (Voice 1–4):

- **LED 19 (Voice 1)** — red
- **LED 20 (Voice 2)** — green
- **LED 21 (Voice 3)** — blue
- **LED 22 (Voice 4)** — magenta
- **Behavior**: In idle mode, glow dimly. Upon voice activation (`TRIG 1-4` button press or incoming MIDI note), light up brightly.

## MIDI Interfaces and Settings

The synthesizer supports full control and bidirectional MIDI message exchange over both USB and hardware connectors (MIDI Jack).

### 1. USB MIDI

The device is recognized by computers as a standard Class-Compliant USB MIDI controller. No drivers required. USB MIDI operates in duplex mode: receives notes and CC commands to control synthesis, and transmits information about physical controls.

### 2. Hardware MIDI Jacks (TRS / DIN)

Physical MIDI IN and MIDI OUT connectors are wired to hardware UART0 on the microcontroller:

- **MIDI RX (IN)**: GPIO 1 (`PIN_MIDI_JACK_IN` in `hw_config.h`)
- **MIDI TX (OUT)**: GPIO 0 (`PIN_MIDI_JACK_OUT` in `hw_config.h`)
- **Baud rate**: standard MIDI — 31250 bps.

### 3. MIDI THRU Functionality

In `hw_config.h`, you can enable the `#define MIDI_THRU` macro. This option turns the synthesizer into a router/hub:

- All incoming bytes from physical MIDI IN are instantly echoed to physical MIDI OUT (hardware echo).
- Incoming messages from physical MIDI IN are duplicated to USB MIDI Out.
- Incoming messages from USB MIDI are forwarded to physical MIDI OUT.

### 4. Voice Allocation

You can change how incoming MIDI notes are allocated across the 4 synth voices. Configured in `SYS` -> `MIDI_MODE` menu (encoder 3):

- **V1 / V2 / V3 / V4** (values 0–3): Monophonic mode. Notes are routed strictly to the selected voice (1, 2, 3, or 4 respectively).
- **RR (Round Robin)** (value 4): Cyclic allocation. Each new note activates the next voice (1 -> 2 -> 3 -> 4 -> 1...).
- **RND (Random)** (value 5): Random allocation to currently free voices.
- **OCT (Octave)** (value 6): Voice selection depends on note octave (1st octave — Voice 1, 2nd octave — Voice 2, etc.).

The `MIDI_CH` parameter on the `SYS` page (encoder 4) sets active MIDI channel from `1` to `16` (or `0` for Omni mode).

### 5. MIDI CC Map

You can emulate button presses and encoder rotations via MIDI Control Change (CC) messages. Default mapping in `hw_config.h` is as follows:

#### Encoders (Relative Mode)

Encoders send and receive relative values (values $\le 63$ decrement parameter, $\ge 65$ increment parameter):

- **Encoder 1**: CC 110 (`MIDI_CC_ENC1`)
- **Encoder 2**: CC 111 (`MIDI_CC_ENC2`)
- **Encoder 3**: CC 112 (`MIDI_CC_ENC3`)
- **Encoder 4**: CC 113 (`MIDI_CC_ENC4`)

#### Matrix Buttons (16 buttons)

Buttons respond to CC values ($\ge 64$ treated as Press, $< 64$ as Release):

- **Row 1 (Grain 1, 2, 3, Filter)**: CC 40 – 43
- **Row 2 (Jitter, LFO 1, 2, EG)**: CC 44 – 47
- **Row 3 (Modulation, FX, Mix, Sys)**: CC 48 – 51
- **Row 4 (Triggers 1, 2, 3, 4)**: CC 52 – 55

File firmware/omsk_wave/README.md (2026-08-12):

# OMSK Wave Synthesizer

> **Note:** Initially, this firmware started as a fork of [digital-synth-pra32-u2](https://github.com/risgk/digital-synth-pra32-u2). Very little of the original engine remains today, but it was immensely helpful during early development.

# Synthesizer Architecture Diagram

Below is the signal flow and modulation routing diagram for the 4-voice polyphonic synthesizer.

```mermaid
---
config:
  layout: dagre
---
flowchart TB
 subgraph NoteInputs["Note Inputs"]
    direction TB
        MIDI(["MIDI Jack In"])
        KBD(["Keyboard"])
        USB_IN(["MIDI USB In"])
        SEQ(["Step Sequencer"])
  end
 subgraph ModInputs["Modulation Sources"]
    direction TB
        LFO1["LFO 1"]
        LFO2["LFO 2"]
        ModWheel["ModWheel"]
  end
 subgraph FX["Master Effects"]
    direction TB
        FX2["Delay"]
        FX1["Chorus"]
  end
 subgraph s2["MIDI OUT"]
    direction TB
        USB_OUT(["MIDI USB Out"])
        JACK_OUT(["MIDI Jack Out"])
  end
 subgraph s3["AUDIO OUT"]
    direction TB
        A_JACK(["Audio Jack Out"])
        A_USB(["Audio USB Out"])
  end
 subgraph voice_arch["Single Voice Architecture"]
        EG1["EG 1"]
        EG2["EG 2"]
        VCF2["VCF 2"]
        VCO1["VCO 1"]
        VCF1["VCF 1"]
        VCO2["VCO 2"]
        NOISE["Noise"]
        MIX["Voice Mixer"]
  end
    VC["Voice Control"] L_VC_V1_0@--> V1["Voice 1"] & V2["Voice 2"] & V3["Voice 3"] & V4["Voice 4"]
    FX1 --> FX2
    NoteInputs --> s2 & VC
    FX --> s3
    V1 L_V1_MIX_V_0@--> MIX_V["Voice Sum"]
    V2 --> MIX_V
    V3 --> MIX_V
    V4 L_V4_MIX_V_0@--> MIX_V
    V4 ==> voice_arch
    VCO2 --> VCF2
    NOISE --> VCF2
    VCO1 L_VCO1_VCF1_0@--> VCF1
    VCF1 L_VCF1_MIX_0@--> MIX
    VCF2 L_VCF2_MIX_0@--> MIX
    ModInputs --> VC
    MIX_V --> FX

    LFO1@{ shape: rect}
    LFO2@{ shape: rect}
    ModWheel@{ shape: rect}
    EG1@{ shape: rect}
    EG2@{ shape: rect}
    VCF2@{ shape: rect}
    VCO1@{ shape: rect}
    VCF1@{ shape: rect}
    style LFO1 fill:#FF6D00
    style LFO2 fill:#FF6D00
    style ModWheel fill:#FF6D00
    style EG1 fill:#FF6D00
    style EG2 fill:#FF6D00
    style V1 fill:#00C853
    style V2 fill:#00C853
    style V3 fill:#00C853
    style V4 fill:#00C853
    style voice_arch fill:#00C853,stroke:#000000

    L_VC_V1_0@{ curve: natural }
    L_VC_V2_0@{ curve: natural }
    L_VC_V3_0@{ curve: natural }
    L_VC_V4_0@{ curve: natural }
    L_V1_MIX_V_0@{ curve: natural }
    L_V4_MIX_V_0@{ curve: natural }
    L_VCO1_VCF1_0@{ curve: natural }
    L_VCF1_MIX_0@{ curve: natural }
    L_VCF2_MIX_0@{ curve: natural }
```

## LED Indication

The instrument is equipped with 22 WS2812B RGB LEDs providing real-time visual feedback.

### Mode Status LEDs

Two LEDs located between encoders (LED 3 and 4) indicate system status. In sequencer mode, they display transport state (Play/Stop) and active step page. See details in [Sequencer LED Indication](#led-indication-in-seq-mode).

### Button LEDs (4x4 Matrix)

16 LEDs located under physical matrix pads change behavior depending on current operation mode:

- **In PIANO mode**, they highlight keyboard structure (white/black keys) and octave transpose/arpeggiator state. See [PIANO Mode LED Indication](#piano-mode-led-indication).
- **In PARAMS mode**, they display active synth modules and current routing. See [PARAMS Mode Module LED Indication](#params-mode-module-led-indication).
- **In SEQ mode**, they show active steps, playhead position, trigger probabilities, and stop steps. See [SEQ Mode LED Indication](#led-indication-in-seq-mode).

### Encoder LEDs (All modes)

4 LEDs above encoder knobs display current values of controlled parameters with a smooth gradient from **Blue** (min 0) through **Purple** (mid 64) to **Red** (max 127).

## Layouts

| enc1 | enc2 | enc3 | enc4 |
| ---- | ---- | ---- | ---- |
| sw1  | sw2  | sw3  | sw4  |
| sw5  | sw6  | sw7  | sw8  |
| sw9  | sw10 | sw11 | sw12 |
| sw13 | sw14 | sw15 | sw16 |

## Core Units

1. **Voices (Voices 1-4):** Each voice has its own set of oscillators (VCO1, VCO2), noise generator (Noise), two filters (VCF1, VCF2), and two envelopes (EG1, EG2). This preserves individual dynamics for every played note.
2. **Voice Mixer:** Mixes oscillator and noise signals before sending them to filters.
3. **Master Section:** Combines signals from all voices and routes them through **Chorus -> Delay** effect chain.
4. **Modulation:**
   - **LFO/EG:** Run locally within each voice for precise timbre control.
   - **ModWheel:** Global controller affecting assigned parameters across all voices simultaneously.

# OMSK Synth — User Manual & Technical Specification

OMSK Synth is a compact hybrid 4-voice polyphonic synthesizer powered by RP2040 and RP2350 microcontrollers. It combines a virtual-analog sound engine, piano play mode, step sequencer, Moog filters, LFOs, envelopes, and built-in FX (chorus/delay) with audio output over external I2S DAC (2ch 48kHz / 16-bit) or built-in PWM output (1ch 48kHz / 10-bit).

## Main Operating Modes

Switching between operating modes is done by **simultaneously pressing OCT↓ and OCT↑** (buttons 13 and 14 in Piano mode, or **MIXER** and **FX2** in PARAMS mode).

### Piano Mode (Play Mode)

This is the default mode when powering on the device.

By default, the following matrix note layout is active on the 4x4 matrix:

| enc1 | enc2 | enc3 | enc4 |
| ---- | ---- | ---- | ---- |
| C | D# | F# | A |
| C# | E | G | A# |
| D | F | G# | B |
| OCT↓ | OCT↑ | ARP  | ADV  |

> [!NOTE]
> You can customize physical key layout settings. For details, see [Key Layout Settings in config.md](docs/config.md).

- **Encoders 1-4**: Control parameters of the last selected module.
- **Keys 1-12 (Rows 1-3)**: Keyboard playing chromatic notes (C, C#, D... B).
- **Button 13 (Bottom row, 1)**: OCT↓ (Octave Down).
- **Button 14 (Bottom row, 2)**: OCT↑ (Octave Up).
- **Button 15 (Bottom row, 3)**: ARP (Arpeggiator).
- **Button 16 (Bottom row, 4)**: ADV (Advanced).

- **OCT↓ + OCT↑** > Switch to PARAMS/Setup Mode
- **OCT↓ + ADV** > Cycle Key for scale snapping
- **OCT↑ + ARP** > Toggle HOLD
- **ARP + ADV** > Toggle SEQ Mode
- **LFO1 + EG1** (Pads 2+3 in Params mode) > PRESET Mode (Hold for Save, Tap for Load)

#### PIANO Mode LED Indication

LEDs under matrix buttons show keyboard layout and control state:

- **White keys** (C, D, E, F, G, A, B): Soft white low brightness. Bright white on key press or MIDI note.
- **Black keys** (C#, D#, F#, G#, A#): Dim blue/cyan low brightness. Bright blue/cyan on key press or MIDI note.
- **OCT↓ and OCT↑ buttons**: Purple. Color shifts with octave transpose (more blue down, more red up), bright purple on press.
- **ARP and ADV buttons**: Dim orange. Bright orange when corresponding layer/mode is active.

#### ARP Section

| Rate | Mode | Swing | Octave |
| ---- | ---- | ----- | --- |
| C | D# | F# | A |
| C# | E | G | A# |
| D | F | G# | B |
| OCT↓ | OCT↑ | PIANO | ADV |

##### Ranges

| Module | Min | Max  | Unit | Mapping / Formula (0..127) |
| --- | --- | ---- | ---- | --- |
| Rate | 1/64 | 1/1  | -- | |
| Mode | OFF | DRNK | ---  | OFF, UP, DOWN, UP-DN, RND, DRNK |
| Swing  | OFF/50 | 75 | % | SIN>TRI>SAW>RSAW>SQR>PWM>PAM4 |
| Octave | -3 | +3 | oct  | |

#### ADV Section

In ADV mode (selected via ADV button), the interface shifts to global settings:

| Tempo | Scale | Chord | MIDI  |
| ----- | ----- | ----- | ----- |
| C | D# | F# | A |
| C# | E | G | A# |
| D | F | G# | B |
| OCT↓  | OCT↑  | Key | PIANO |

- **Pads 1-12**: Set Scale Key (C, C#, D... B)
- **Pad 16 (ADV/PIANO)**: Return to Piano Mode

##### Tempo

- off sync
- external sync
- 30
- 31
- …
- 300

###### Sync behaviour

When SYNC is enabled, time-based parameters are tied to musical beats and are specified as fractional parts of a beat (for example: 1/1 = whole note, 1/2 = half note, 1/4 = quarter note, 1/8 = eighth note, 1/8t = eighth-note triplet, etc.). The following knobs/parameters become beat-synced and accept sync-notation instead of absolute time:

- `Tempo` (global BPM reference)
- `ARP > Rate`
- `LFO1 > Rate` and `LFO2 > Rate` (LFO frequency is expressed as a fraction of a beat in SYNC mode)
- `GLIDE > Time`
- `FX1 (Delay) > Time`
- `EG1/EG2 > Attack`, `EG1/EG2 > Decay`, and `EG1/EG2 > Release` (envelope times are interpreted as beat fractions in SYNC mode). `Sustain` remains a level/percentage and is not beat-synced.

In SYNC mode the LFO frequency is also specified as a fraction of the beat (e.g. `1/4` = one cycle per quarter note). Triplet and dotted divisions from the `Sync MODE` list are supported.

####### Sync range

- 8/1
- 8/1t
- 4/1
- 4/1t
- 1/1
- 1/1t
- 1/2
- 1/2t
- 1/4
- 1/4t
- 1/8
- 1/8t
- 1/16
- 1/16t
- 1/32
- 1/32t
- 1/64
- 1/64t

##### Scales (MIDI Note Scale Quantizer)

- OFF / Chromatic / Thru Mode
- Major
- Minor
- Harmonic Minor
- Melodic Minor
- Dorian
- Locrian
- Lydian
- Blues
- Major Pentatonic
- Minor Pentatonic
- Augmented

##### Chords (Polyphonic Note Expansion)

When Chord mode is active, pressing a single note triggers additional notes to form a chord.

| **Category** | **Full Name** | **Abbr**  | **Intervals (semitones)** | **Description** |
| --- | --- | --- | --- | --- |
| **Basic** | OFF | **OFF** | 0 | No chord expansion |
| **Intervals**  | Minor 2nd | **m2** | 0, 1 | Minor second |
| | Major 2nd | **M2** | 0, 2 | Major second |
| | Minor 3rd | **m3** | 0, 3 | Minor third |
| | Major 3rd | **M3** | 0, 4 | Major third |
| | Perfect 4th | **P4** | 0, 5 | Perfect fourth |
| | Tritone | **Tri** | 0, 6 | Tritone |
| | Perfect 5th | **P5** | 0, 7 | Perfect fifth |
| | Minor 6th | **m6** | 0, 8 | Minor sixth |
| | Major 6th | **M6** | 0, 9 | Major sixth |
| | Minor 7th (Int) | **m7i** | 0, 10 | Minor seventh (interval) |
| | Major 7th (Int) | **M7i** | 0, 11 | Major seventh (interval) |
| | Octave | **Oct** | 0, 12 | Octave |
| **Triads** | Major | **M** | 0, 4, 7 | Major triad |
| | Minor | **m** | 0, 3, 7 | Minor triad |
| | Diminished | **Dim** | 0, 3, 6 | Diminished triad |
| | Augmented | **Aug** | 0, 4, 8 | Augmented triad |
| | Suspended 2 | **Sus2**  | 0, 2, 7 | Suspended 2nd |
| | Suspended 4 | **Sus4**  | 0, 5, 7 | Suspended 4th |
| **7th Chords** | Major 7th | **M7** | 0, 4, 7, 11 | Major 7th chord |
| | Dominant 7th | **Dom7**  | 0, 4, 7, 10 | Dominant 7th chord |
| | Minor 7th | **m7** | 0, 3, 7, 10 | Minor 7th chord |
| | Half-Diminished | **m7b5**  | 0, 3, 6, 10 | Half-diminished 7th |
| | Diminished 7th  | **Dim7**  | 0, 3, 6, 9 | Diminished 7th |
| | Minor-Major 7th | **mM7** | 0, 3, 7, 11 | Minor-major 7th |
| | Augmented-M 7th | **AugM7** | 0, 4, 8, 11 | Augmented major 7th |
| | Augmented 7th | **Aug7**  | 0, 4, 8, 10 | Augmented 7th |
| **Extended** | Major 6th | **M6** | 0, 4, 7, 9 | Major 6th chord |
| | Minor 6th | **m6** | 0, 3, 7, 9 | Minor 6th chord |
| | Add 9 | **Add9**  | 0, 4, 7, 14 | Major add 9 |
| | 7th Sus 4 | **7s4** | 0, 5, 7, 10 | 7th suspended 4th |
| | M 7th Sus 4 | **M7s4**  | 0, 5, 7, 11 | Major 7th suspended 4th  |
| **Advanced** | 7 Sharp 5 | **7#5** | 0, 4, 8, 10 | Dominant 7 sharp 5 |
| | 7 Flat 5 | **7b5** | 0, 4, 6, 10 | Dominant 7 flat 5 |
| | Quartal | **Quart** | 0, 5, 10, 15 | Quartal stack |
| | Lydian | **Lyd** | 0, 4, 6, 7 | Lydian chord (#4) |

### Param

### PARAMS / SETTINGS Mode

In this mode, the button matrix selects the active module for editing.

- **Encoders 1-4**: Change parameters of selected module.
- **Buttons 1-16**: Select active module. Active module highlights with its color.

#### Button Layout (PARAMS Mode)

| enc1  | enc2 | enc3  | enc4 |
| ----- | ---- | ----- | ---- |
| VCO1  | VCF1 | LFO1  | EG1  |
| VCO2  | VCF2 | LFO2  | EG2  |
| NOISE | FX1  | GLIDE | SET  |
| MIXER | FX2  | MOD | FN |

- **"MIXER" + "FX2"** > Return to Piano Mode
- **SET** (Short tap) > Toggle Assignment Mode
- **SET** (Hold) + Encoder > Adjust Modulation Depth
- **FN** (Hold) + Pad/Encoder > Clear assignment

#### PARAMS Mode Module LED Indication

| LED Index | Module | Color (base) | Default Brightness | Pressed / Selected Brightness |
| --- | --- | --- | --- | --- |
| 7 | VCO1 | White / Filter clr | 5% | 70% |
| 8 | VCF1 | Pink (255,30,100) | 20% | 70% |
| 9 | LFO1 | Lt Blue (100,200,255)  | 20% | 70% |
| 10 | EG1 | Lt Green (100,255,100) | 20% | 70% |
| 11 | VCO2 | White / Filter clr | 5% | 70% |
| 12 | VCF2 | Magenta (255,0,255) | 20% | 70% |
| 13 | LFO2 | Blue (0,0,255) | 20% | 70% |
| 14 | EG2 | Green (0,255,0) | 20% | 70% |
| 15 | NOISE  | White / Filter clr | 5% | 70% |
| 16 | FX1 | Yellow (255,255,0) | 20% | 70% |
| 17 | GLIDE  | Cyan (0,255,255) | 20% | 70% |
| 18 | SET | Red (255,0,0) | 20% | 70% |
| 19 | MIXER  | Warm Wht (255,200,130) | 20% | 70% |
| 20 | FX2 | Orange (255,100,0) | 20% | 70% |
| 21 | MOD | Gold (255,200,0) | 20% | 70% |
| 22 | FN | Coral (255,80,0) | 20% | 70% |

**VCO1/VCO2/NOISE**: By default glow white at 5%. If assigned to filter (`route_vco == 1` → VCF1/Pink, `route_vco == 2` → VCF2/Magenta), LED takes filter color.

#### Encoder Layout

| Mode | enc1 | enc2 | enc3 | enc4 |
| --- | --- | --- | --- | --- |
| VCO1/2 | Transpose  | Detune | Wave | Shape |
| VCF1/2 | Cutoff | Resonance | Keytrack | Mix |
| LFO1/2 | Rate | Smooth | Wave | Shape |
| EG1/2 | Attack | Decay | Sustain | Release |
| NOISE | Color | Chord | --- | --- |
| MIXER | VCO1.Vol | VCO1.Vol  | VCO1/2.Phase | Noise.Vol |
| GLIDE | Time | Slope | Mode | Poly |
| FX1 (Chorus) | Time | Feedback  | Depth | Mix |
| FX2 (Delay)  | Time | Feedback  | Tone | Mix |
| SET | Assignment | --- | --- | --- |
| MOD | s>t 1 | depth 1 | s>t 2 | depth 2 |

Shift+Noise.Vol > Master vol

#### Ranges

| Module | Knob  | Full Name | Min | Max | Unit | Mapping / Formula (0..127) |
| --- | ----- | --- | ----- | --- | --- | --- |
| VCO1/VCO2 | TRNSP | Transpose | -5 | +5 | octave | `round((p-64)/64 * 5)` |
| VCO1/VCO2 | DETN  | Detune | -700  | +700 | cents  | `detune_table[p]` (non-linear)  |
| VCO1/VCO2 | WAVE  | Wave | SIN | HYB | morph  | SIN>TRI>SAW>RSAW>SQR>PWM>PAM4 |
| VCO1/VCO2 | SHAP  | Shape | 0 | 100 | % | PWM or Wavefold depth |
| VCF1/VCF2 | CUT | Cutoff | 50 | 8000 | Hz | `50 * 160^(p/127)` (Log) |
| VCF1/VCF2 | RES | Resonance | 0.5 | 12 | Q | `0.5 + (p/127) * 11.5` |
| VCF1/VCF2 | KEY | Keytrack  | 0 | 100 | % | Filter keyboard tracking |
| VCF1/VCF2 | MIX | Mix | 0 | 100 | % | dry/wet |
| LFO1/LFO2 | RATE  | Rate | 0.05  | 400 | Hz | `0.05 * 2^((p/127)*8.64)` (Log) |
| LFO1/LFO2 | SMTH  | Smooth | 0 | 100 | % | LFO smoothing |
| LFO1/LFO2 | WAVE  | Wave | --- | --- | --- | Waveform selection (SIN..PAM) |
| LFO1/LFO2 | SHAP  | Shape | 0 | 100 | % | |
| EG1/EG2 | ATK | Attack | 0 | 2000 | ms | Log mapped 0..2s |
| EG1/EG2 | DEC | Decay | 0 | 2000 | ms | Log mapped 0..2s |
| EG1/EG2 | SUSTN | Sustain | 0 | 100 | % | |
| EG1/EG2 | RELSE | Release | 0 | 2000 | ms | Log mapped 0..2s |
| NOISE | CLR | Color | RED | VLT | --- | RED>PINK>WHITE>BLUE>VIOLET |
| NOISE | CHRD  | Chord | OFF | M7S4 | mode | See Chord list |
| MIXER | BAL | Balance | 100%  | 100% | VCO1/2 | VCO1 balance vs VCO2 |
| MIXER | O/N | Osc/Noise | 100%  | 100% | Mix | Oscillators vs Noise |
| MIXER | PHAS  | Phase 2 | 0 | 360 | ° | VCO2 phase offset |
| MIXER | VOL | Master | 0 | 100 | % | Master output volume |
| GLIDE | TIME  | Time | 0.001 | 10 | s | `0.001 * 10^((p/127)*4)` (Log)  |
| GLIDE | SLOP  | Slope | Log | Exp | --- | Log < 64 < Lin > 64 > Exp |
| GLIDE | MODE  | Mode | Off | Always | --- | Off, Legato, Always |
| GLIDE | POLY  | Poly mode | 4V | Unson  | voices | 4 voices / Mono / Unison |
| FX1 (Chorus) | TIME  | Time | 5 | 1000 | ms | Chorus delay time |
| FX1 (Chorus) | FEED  | Feedback  | 0 | 100 | % | |
| FX1 (Chorus) | DPTH  | Depth | 0 | 100 | % | Chorus modulation depth |
| FX1 (Chorus) | MIX | Mix | 0 | 100 | % | |
| FX2 (Delay)  | TIME  | Time | 5 | 1000 | ms | Delay time |
| FX2 (Delay)  | FEED  | Feedback  | 0 | 100 | % | |
| FX2 (Delay)  | TONE  | Tone | 0 | 100 | % | Low/High pass in feedback loop  |
| FX2 (Delay)  | MIX | Mix | 0 | 100 | % | |

### Params Layers

#### VCO

polyBLEP

BLIT (Band-Limited Impulse Train) — ideal band-limited impulse train generation, providing aliasing-free saw/square waves.

BLEP (Band-Limited Step) — correction added at signal step discontinuities to remove spectral artifacts.

BLAMP (Band-Limited Ramp) — same principle applied to derivative slope breaks.

#### VCF

Computing digital filters (especially resonant filters and high-order filters with large Q) is computationally expensive for microcontrollers. We recommend:

- Use precomputed lookup tables (LUT) for key coefficients/values and simple interpolation between points.
- Limit filter order or apply cascades of simple single-pole/two-pole blocks (SVF) to distribute the computational load.
- Calculate heavy coefficients when parameters change (or on low-frequency ticks), not on every audio sample.
- Implement anti-aliasing or windowing for strong modulation and in sync modes.

This approach ensures predictable performance and reduces artifacts without significantly increasing CPU load.

Cutoff Key Track [0%...100%]
Key tracking allows the note played on the keyboard to influence the cutoff frequency of the filter.
0%: No keyboard tracking will be applied.
50%: The cutoff frequency will change at half the rate/slope as the pitch of the keyboard.
100%: The cutoff frequency will change at the same rate/slope as the pitch of the keyboard.

##### Filter Type

- **Cutoff:** Range 20 Hz — 20,000 Hz.
- 2nd order filter (12 dB/oct). Several filter types supported in config (PRA32
- , SVF, Moog Ladder), see [Firmware Config](docs/config.md).
- **Key Tracking (±100%):** $F_{actual} = F_{cutoff} + (Note - 60) \times Tracking$. Cutoff calculation via LUT (no `pow()`).
- **Resonance:** With gain compensation to preserve volume.

| Parameter | Name | Description | Min | Max | Unit | Note |
| --- | --- | --- | --- | ----- | ---- | --- |
| VCF1/VCF2 | LPF/BPH/HPF | Freq | 20  | 10000 | Hz | log |
| VCF1/VCF2 | RES | Resonance | 0.5 | 12 | Q | |
| VCF1/VCF2 | KEYTK | Keytrack | 0 | 100 | % | |
| VCF1/VCF2 | MIX | Mix | 0 | 100 | % | dry/wet |

fn+Freq changes filter type. Only label text changes, on-screen knob position remains unchanged.

Coefficients stored in LUT.

##### Filter Routing (VCF)

Assign filters to process oscillator or noise signals.

###### Filter Assignment (SET)

To route a source to a filter:

`[Filter: VCF1/2] > SET (hold) > [Source Signal] > SET (release)`

> **Example:** Assign VCF1 to VCO1:
>
> `VCF1 > SET.Down > VCO1 > SET.up`

###### Remove Routings (REMOVE)

Use `FN` key to clear routings:

| **Task** | **Combo** |
| --- | --- |
| **Disconnect filter from src** | `FN (hold) > [Signal Source] > FN (release)`  |
| **Reset ALL filter routings**  | `FN (hold) > [Filter: VCF1/2] > FN (release)` |

###### Source/Target Overview

| **Type** | **Sources (Filters)** | **Targets (Signals)** |
| --- | --- | --- |
| **Filters** | VCF1, VCF2 | VCO1, VCO2, Noise |

#### Shape

- **SIN / TRI / SAW**: Audio-rate Wavefolding depth (up to 8 folds).
- **SQR / PWM**: Sub-pulse generation or binary folding.
- **PAM4**: Pattern-specific modifier.

#### Mixer

To ensure stable volume levels and prevent clipping across multiple voices, power conservation law normalization (Square Root Compensation) is applied.

##### Mathematical Model for Normalization

Detailed formulas, velocity calculations, and pseudocode for voice and polyphonic mixing are documented in [DSP Technical Specification](docs/dsp.md).

#### MOD

Audio-rate signal modulation applies one signal directly to another (e.g. VCO2 modulating VCO1). The engine supports amplitude modulation (AM), frequency modulation (FM), ring modulation (RM), and hard sync.

The `MIXER` phase parameter controls phase offset applied to modulators before AM/FM/RM/Sync calculations.

##### Source/Target (s/t 1)

| Name | Source | Target | Notes |
| --- | --- | --- | --- |
| OFF | --- | --- | |
| Sc 1>2 | VCO1 | VCO2 | Sync |
| Sc 1>N | VCO1 | Noise  | Sync |
| AM 1>2 | VCO1 | VCO2 | Amp Modulation  |
| AM 1>N | VCO1 | Noise  | Amp Modulation  |
| FM 1>2 | VCO1 | VCO2 | Freq Modulation |
| FM 1>N | VCO1 | Noise  | Freq Modulation |
| RM 1>2 | VCO1 | VCO2 | Ring Modulation |
| RM 1>N | VCO1 | Noise  | Ring Modulation |

##### Source/Target (s/t 2)

| Name | Source | Target | Notes |
| --- | --- | --- | --- |
| OFF | --- | --- | |
| Sc 2>1 | VCO2 | VCO1 | Sync |
| Sc 2>N | VCO2 | Noise  | Sync |
| AM 2>1 | VCO2 | VCO1 | Amp Modulation  |
| AM 2>N | VCO2 | Noise  | Amp Modulation  |
| FM 2>1 | VCO2 | VCO1 | Freq Modulation |
| FM 2>N | VCO2 | Noise  | Freq Modulation |
| RM 2>1 | VCO2 | VCO1 | Ring Modulation |
| RM 2>N | VCO2 | Noise  | Ring Modulation |

### Modulation Routing

Any parameter knob can be automated using one of five modulators: **ModWheel**, **LFO1/2**, or **EG1/2**.

**Modulation Depth:** -100% to +100%.

#### Modulator Assignment (SET)

To bind a modulator to a parameter:

- **For ModWheel:** `SET (hold) > ModWh > [Parameter] > SET (release)`
- **For LFO and EG:** `[Source: LFO1/2 or EG1/2] > SET (hold) > [Parameter] > SET (release)`

> **Example:** Bind LFO1 to VCO1 Volume:
>
> `LFO1 > SET.Down > MIXER > turn VCO1.Vol encoder > SET.up`

#### Remove Routings (REMOVE)

Use `FN` key to clear assignments:

| **Task** | **Combo** |
| --- | --- |
| **Delete specific routing** | `FN (hold) > [Target Parameter] > FN (release)` |
| **Reset ALL modulator routings** | `FN (hold) > [Source: ModWh, LFO or EG] > FN (release)` |

#### Sources and Targets Summary

| **Type** | **Sources** | **Targets** |
| --- | --- | --- |
| **Wheel** | ModWheel | Any control knob |
| **LFO Generators** | LFO1, LFO2  | Any control knob |
| **Envelopes** | EG1, EG2 | Any control knob |

#### Modulation Depth

Adjust depth by holding SET while turning assigned knob. Display switches knob fill to white and shows depth value +/-100%.

##### Mathematical Model for Modulation

Detailed mathematical models, normalization tables, and pseudocode are documented in [DSP Technical Specification](docs/dsp.md).

##### UI Visualization

1. **Bargraph**: Centered indicator. Fills right when $\Delta K > 0$, left when $\Delta K < 0$.
2. **Label**: Source (`LFO1`, `LFO2`, `EG1`, `EG2`, `ModWh`) centered below bargraph.

#### Waveform

Parameters and waveforms are identical for VCO1/VCO2/LFO1/LFO2.

### Randomize Parameters

To randomize values of current module:

1. Hold selection button of target module in **PARAMS** mode (e.g., **VCO1**).
2. Press **FN**.
3. Release module button — all 4 parameters of that module are randomized.

### Seq

Plays specified notes in a loop. Up to 64 steps (16 steps * 4 pages). Each page has its RGB LED color (green, blue, purple, orange). Muted step glows at 5% brightness.

### Play Steps

| Speed | Swing | Mode  | note length |
| ----- | ----- | ----- | --- |
| STP1  | STP2  | STP3  | STP4 |
| STP5  | STP6  | STP7  | STP8 |
| STP9  | STP10 | STP11 | STP12 |
| STP13 | STP14 | STP15 | STP16 |

#### UI

| Speed | Swing | Mode | Len  |
| ----- | ----- | --- | ---- |
| page  | step  | play/pause | slot |
| 1/4 | 1/64  | play/pause | 1/16 |

##### Color Scheme & Indication Logic (v2)

###### 1. Step Status (16 Matrix Pads)

- **Empty Step:** Off (Black).
- **Active Step (Trig):** Green (if cycle condition 2/4/8 is currently met).
- **Standby Step:** Yellow (if cycle condition 2/4/8 is NOT currently met).
- **Mute:** Pink.
- **Stop Step (Sequence End):** Red.
- **Current Step (Playhead):** White (overlaid on top with max brightness).

###### 2. Probability

Brightness defines triggering probability (for Green, Yellow, Pink):

- **100%:** Max brightness (255).
- **75-85%:** High brightness (190-210).
- **40-50%:** Medium brightness (110-130).
- **10-25%:** Low brightness (40-70).
- **0%:** Step becomes visually black.

###### 3. Status LEDs (2 RGB LEDs)

####### LED 3: Transport Status (Play/Pause)

- **Play:** Solid Green.
- **Pause/Stop:** Red (or Orange).

####### LED 4: Navigation (Pages 1-4)

- **Page 1 (1-16):** Red.
- **Page 2 (17-32):** Green.
- **Page 3 (33-48):** Blue.
- **Page 4 (49-64):** Purple.

###### Layering Priority

Evaluate LED color conditions in this exact order:

1. **Cursor:** If `current_step == LED_index`, color = **WHITE (MAX)**.
2. **Stop:** If `step == stop_step`, color = **RED**.
3. **Mute:** If `is_muted`, color = **PINK** (brightness = Probability).
4. **Loop Condition:**
   - If cycle condition matches, color = **GREEN** (brightness = Probability).
   - If cycle condition does NOT match, color = **YELLOW** (brightness = Probability).
5. **Default:** If step inactive, color = **BLACK**.

#### Play Mode Descriptions

- **Forward** (UP): plays steps 1→2→3→...→16→1 sequentially
- **Backward** (DOWN): plays steps in reverse 16→15→14→...→1→16
- **Pingpong** (UP-DN): plays forward 1→16, then immediately backward 16→1
- **Snake** (SNK): plays in a serpentine pattern across 4x4 grid (1→2→3→4→8→7→6→5→9→10→11→12→16→15→14→13)
- **Random** (RND): selects a random step on each beat
- **Drunk**: random walk — moves to an adjacent step (±1) on each beat

STP"X" > Mute step — Disables playback for specified step

#### Chords

| Chord | Action | Notes |
| --- | --- | --- |
| STP"X" > + Speed enc | probability | |
| STP3+STP4 | Load/Save seq | STP3+STP4 > 1-16 key > load 1-16 preset |
| STP5+STP9 | Prev page | |
| STP8+STP12 | Next page | |
| STP13+STP14 | Param | |
| STP15+STP16 | PIANO mode | |
| STP10+STP11 | Play/Pause | Play/Pause sequence playback |
| STP14+STP15 | Stop step | Sets a stop flag on the beat. If flags are set on steps 5, 8 and 9, only steps 1-4 are played |
| STP1+STP2 | Edit step | Enter edit mode for the specified step |
| STP13+STP16 | Copy mode | STP1.Down>STP2.Down>STP2.Up>STP1.Down>source step>target step |

#### Ranges

| Knob | Min  | Max | Unit | Note |
| --- | ---- | --- | ---- | --- |
| speed | 1/16 | 8 | x | |
| swing | off  | 75  | % | |
| mode | 1 | 8 | - | |
| note length | 0 | 100 | % | (0, 10, 25, 40, 50, 75, 85, 100) |

### Edit Mode

| VEL  | CHRD | Every | Prob |
| ---- | ---- | ----- | ---- |
| C | D | E | F |
| G | A | B | C# |
| D# | F# | G# | A# |
| OCT↓ | OCT↑ | Clear | Done |

#### Ranges

| Knob  | Min | Max | Unit | Note |
| ----- | --- | --- | ---- | --- |
| VEL | 0 | 127 | | velocity for the step |
| CHRD  | | | | |
| Every | 1 | 8 | - | play every loop, every 2.. every 8 |
| Prob  | 0 | 100 | % | Probability, (0, 10, 25, 40, 50, 75, 85, 100) |

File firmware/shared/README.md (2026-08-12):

# Shared Hardware & Driver Components (`firmware/shared`)

This folder contains the shared library of hardware drivers, low-level abstractions, and helper modules (DSP, PIO, third-party libraries) utilized by all firmware applications in the OMSK project.

---

## Directory Structure

- `hw_config.h` — Main hardware configuration header: GPIO pin assignments (button matrix, encoders, OLED display, DAC/PWM audio, RGB LEDs, MIDI), display type selection, WS2812 LED mapping, and MCU overclocking settings.
- `image_logo.h` — Bitmap header for the OMSK boot logo displayed on the OLED screen.
- `hardware/` — Low-level device drivers:
  - `matrix.h` / `matrix.cpp` — Driver for the 4x4 switch matrix.
  - `encoders.h` / `encoders.cpp` — Driver for rotary encoder handling.
  - `midi_uart.h` / `midi_uart.cpp` — Hardware UART MIDI (DIN/TRS Jack) driver.
  - `midi_helpers.h` — Helper utilities for building and parsing MIDI messages.
  - `colors.h` — Color palettes and preset definitions for WS2812 RGB LEDs.
- `dsp/` — Digital Signal Processing utilities:
  - `fast_math.h` / `fast_math.cpp` — Fast math lookup table functions.
- `pio/` — Programs for RP2040/RP2350 Programmable I/O (PIO) state machines:
  - `audio.pio` — PWM audio output state machine.
  - `i2s_tx.pio` — I2S transmitter state machine for external DACs (e.g., PCM5102).
  - `ws2812.pio` — WS2812B addressable LED driver state machine.
  - `button_matrix.pio` — PIO matrix scanning driver.
- `lib/` — Third-party libraries and dependencies:
  - `u8g2` — Graphics library for OLED displays.
  - `tinyusb` — USB stack for USB MIDI and CDC interfaces.
  - `CMSIS-DSP`, `pico-extras`, `pico_audio_i2s_32b`, `pico_fft` — Audio processing and I2S/DSP support libraries.

---

## Configuration Parameters (`hw_config.h`)

The `hw_config.h` file defines physical pin routing and core hardware configuration settings across all firmwares.

### 1. Keyboard Matrix (4x4 Matrix Switches)

- `PIN_MATRIX_COL1` .. `PIN_MATRIX_COL4` (GPIO 10, 9, 7, 6): Column GPIO pins for matrix scanning.
- `PIN_MATRIX_ROW1` .. `PIN_MATRIX_ROW4` (GPIO 14, 13, 12, 11): Row GPIO pins for matrix scanning.

### 2. Encoders

- `PIN_ENCODER1_A` / `PIN_ENCODER1_B` (GPIO 2, 3) — Encoder 1 channels A/B.
- `PIN_ENCODER2_A` / `PIN_ENCODER2_B` (GPIO 4, 5) — Encoder 2 channels A/B.
- `PIN_ENCODER3_A` / `PIN_ENCODER3_B` (GPIO 15, 26) — Encoder 3 channels A/B.
- `PIN_ENCODER4_A` / `PIN_ENCODER4_B` (GPIO 27, 28) — Encoder 4 channels A/B.
- `ENCODER_RESOLUTION` (default: 4): Number of pulses/detents per physical step.

### 3. Audio Output Pins

- `PIN_AUDIO_PWM_L` (GPIO 29) / `PIN_AUDIO_PWM_R` (GPIO 16): PWM mono/stereo audio output pins.
- `PIN_DAC_I2S_BCK` (GPIO 17), `PIN_DAC_I2S_LRCK` (GPIO 18), `PIN_DAC_I2S_DATA` (GPIO 19): I2S pins for external DACs (Bit Clock, Left/Right Clock, and Serial Data).

### 4. Display Pins

- `CFG_OLED_TYPE`: Selects the OLED display controller/orientation:
  - `0`: SSD1312 128x64 (Standard horizontal screen).
  - `1`: SH1107 64x128 (Vertical "Turtle" screen).
- `PIN_OLED_SCL` (GPIO 21), `PIN_OLED_SDA` (GPIO 20): I2C clock and data lines.
- `OLED_I2C` (`i2c0`): Hardware I2C peripheral instance used.
- `OLED_FLIP`: Rotates the display output 180 degrees.
- `OLED_BRIGHTNESS_PERCENT` (default: 15): Screen brightness percentage.

### 5. RGB LED Pins & Mapping (WS2812B)

- `PIN_RGB_LED` (GPIO 8): Data output pin for WS2812B strip.
- `NUM_RGB_LEDS` (default: 22): Total number of LEDs (16 matrix key backlights + 6 encoder/mode status LEDs).
- `RGB_MAX_BRIGHTNESS` (default: 63): Maximum brightness scaling limit (0-255).
- `LED_ENCODER_1` .. `LED_ENCODER_4`, `LED_MODE_1`, `LED_MODE_2`: Status indicator LED indices.
- `MATRIX_LED_MAP[16]`: Mapping array associating 4x4 matrix key indices with physical WS2812 strip indices.

### 6. MIDI Jacks (Serial Hardware MIDI)

- `PIN_MIDI_JACK_OUT` (GPIO 0) / `PIN_MIDI_JACK_IN` (GPIO 1): Hardware UART MIDI pins (TRS Type A).
- `MIDI_THRU`: Enables automatic hardware forwarding of incoming MIDI In data to MIDI Out.

### 7. Debounce & System Overclocking

- `DEBOUNCE_TIME_MS` (default: 10): Switch debounce filtering window in milliseconds.
- `CFG_OVERCLOCK_KHZ`: Target MCU boot clock frequency in kHz (133000 kHz for RP2040, 240000 kHz for RP2350).

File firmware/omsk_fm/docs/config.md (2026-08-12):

# Omsk FM Configuration Specification

Omsk FM configuration parameters are defined in `src/sw_config.h`. This file specifies compiler switches, audio engines, system clock settings, peripheral drivers, and dependencies shared with other synthesizers in the `omsk` project.

---

## Build Configuration Flags (`src/sw_config.h`)

### 1. Hardware Sharing Options

Omsk FM imports core drivers from the `shared` library. The following definitions enable hardware layers:

- `CFG_ENABLE_OLED` (0 or 1): Compiles the 128x64 SSD1306 OLED interface driver and screen rendering loops.
- `CFG_ENABLE_RGB_LED` (0 or 1): Compiles the WS2812 RGB LED controller for the 16-pad matrix and encoder indicators.
- `CFG_PIANO_LAYOUT`: Defines the physical midi mapping of the 16 pads in matrix play mode.

### 2. Audio Engine Settings

- `CFG_ENABLE_PWM8_AUDIO` (0 or 1): Configures 8-bit mono pulse-width modulation audio output on GPIO pins.
- `CFG_ENABLE_BETTER_PWM` (0 or 1): Activates 10-bit hardware PWM with noise shaping to lower the noise floor.
- `CFG_ENABLE_DAC` (0 or 1): Compiles the I2S master clock, bit clock, and data output code to drive external DACs (e.g., PCM5102A).

### 3. MIDI & USB Configuration

- `CFG_ENABLE_USB_MIDI` (0 or 1): Enables USB composite class driver support for MIDI streaming.
- `CFG_ENABLE_JACK_MIDI` (0 or 1): Enables hardware UART MIDI reception and transmission via standard optocoupled jacks.
- `CFG_ENABLE_MIDI_THRU` (0 or 1): Automatically mirrors input MIDI streams directly to MIDI Out.

### 4. Overclocking Settings

To maintain a stable sampling rate with 6 operators per voice (across multiple polyphonic voices), MCU overclocking is recommended:

- `CFG_ENABLE_OVERCLOCK` (0 or 1): Enables custom system clock frequencies on boot.
- `CFG_OVERCLOCK_RP2040_KHZ` (default: 150000): Frequency in kHz (150 MHz) for RP2040 boards.
- `CFG_OVERCLOCK_RP2350_KHZ` (default: 240000): Frequency in kHz (240 MHz) for RP2350 boards.

---

## Folder and Build Alignment

The `omsk_fm` folder matches the structure of `omsk_wave`:

- `CMakeLists.txt`: Defines targets, includes the Pico SDK, and links `shared` hardware drivers.
- `src/main.cpp`: Synthesizer entry point initializing system hardware, starting the MIDI task, and running the background voice rendering loop.
- `src/synth/`: Real-time audio rendering code utilizing lookup tables (LUTs) for oscillators and envelope scaling curves.
- `src/usb/` and `src/midi/`: Standard TinyUSB stack and SysEx parsing buffers.

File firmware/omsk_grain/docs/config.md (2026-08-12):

# Granular Firmware Configuration (`omsk_grain`)

All hardware and software settings for the instrument are specified at compile-time using C/C++ preprocessor macros. They are divided into two header files:

1. `shared/hw_config.h` — hardware parameters (pins, overclocking, LED brightness).
2. `omsk_grain/src/sw_config.h` — audio engine and interface parameters.

---

## 1. Hardware Settings (`shared/hw_config.h`)

This file is shared between the synthesizer and granular firmwares.

### LED Brightness Setting

The maximum brightness limit for WS2812 LEDs is set using the `RGB_MAX_BRIGHTNESS` macro (value range from `0` to `255`, default set to `63` for comfortable glare-free lighting):

```c
#define RGB_MAX_BRIGHTNESS 63
```

### CPU Frequency (Overclock)

The system clock frequency is set depending on the chip used (RP2040 or RP2350):

```c
#ifdef PICO_RP2040
#define CFG_OVERCLOCK_KHZ 133000 // For RP2040 (133 MHz)
#else
#define CFG_OVERCLOCK_KHZ 240000 // For RP2350 (240 MHz)
#endif
```

### Physical Pin Assignments (Pinout)

- **Keyboard Matrix**: `PIN_MATRIX_ROW1..4` and `PIN_MATRIX_COL1..4`
- **Encoders**: `PIN_ENCODER1..4_A` and `PIN_ENCODER1..4_B`
- **Audio Outputs**:
  - PWM: `PIN_AUDIO_PWM_L` (GPIO 29) and `PIN_AUDIO_PWM_R` (GPIO 16)
  - I2S DAC: `PIN_DAC_I2S_BCK` (GPIO 17), `PIN_DAC_I2S_LRCK` (GPIO 18), `PIN_DAC_I2S_DATA` (GPIO 19)
- **OLED Display (I2C)**: `PIN_OLED_SDA` (GPIO 20) and `PIN_OLED_SCL` (GPIO 21)
- **RGB LEDs**: `PIN_RGB_LED` (GPIO 8)
- **MIDI Jack (Serial)**: `PIN_MIDI_JACK_OUT` (GPIO 0) and `PIN_MIDI_JACK_IN` (GPIO 1)

---

## 2. System Settings (`omsk_grain/src/sw_config.h`)

These parameters are specific to the granular engine.

### Audio Output Selection

You can select the physical audio output method by uncommenting one of the macros:

```c
// #define AUDIO_OUT_DAC // Output via I2S DAC (PCM5102, etc.)
#define AUDIO_OUT_PWM // Output via two PWM channels (default)
```

### Sleep Timeout

Time in minutes after which, in the absence of activity, the OLED screen and LEDs turn off (0 — sleep disabled):

```c
#define CFG_SLEEP_TIMEOUT_MIN 1
```

### Sampler Parameters

Parameters for importing and playing back samples from built-in memory:

```c
#define CONFIG_BIT_DEPTH            8     // Sample bit depth (8-bit)
#define CONFIG_SAMPLE_RATE         22050  // Sampling rate (22050 Hz)
#define CONFIG_SILENCE_THRESHOLD_DB -50   // Silence threshold for auto-trim (dB)
#define CONFIG_ENVELOPE_POINTS      128   // Number of sample envelope points
```

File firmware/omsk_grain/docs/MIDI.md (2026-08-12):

# MIDI Documentation for Granular Firmware (`omsk_grain`)

This file contains a comprehensive description of all MIDI interfaces, settings, voice allocation methods, and the MIDI Control Change (CC) message map for the granular synthesizer.

---

## 1. MIDI Interfaces and Connections

The synthesizer supports full control and bidirectional MIDI message exchange via both USB and hardware connectors.

### USB MIDI

The device is recognized by computers as a standard Class-Compliant USB MIDI controller. No drivers are required. USB MIDI operates in duplex mode: accepting notes and CC commands for synthesis control, and transmitting information about physical control interactions.

### Hardware MIDI Jacks (TRS / DIN)

Physical MIDI IN and MIDI OUT connectors are connected to the microcontroller's hardware UART0 controller:

- **MIDI RX (IN)**: GPIO 1 (`PIN_MIDI_JACK_IN` in [hw_config.h](../../shared/hw_config.h))
- **MIDI TX (OUT)**: GPIO 0 (`PIN_MIDI_JACK_OUT` in [hw_config.h](../../shared/hw_config.h))
- **Baud Rate**: standard MIDI speed — 31250 bps.

### MIDI THRU Functionality

In [hw_config.h](../../shared/hw_config.h), you can activate the `#define MIDI_THRU` macro. This option turns the synthesizer into a hub/router:

- All incoming bytes from physical MIDI IN are instantly echoed to physical MIDI OUT (hardware echo).
- Incoming messages from physical MIDI IN are duplicated to USB MIDI Out.
- Incoming messages from USB MIDI are forwarded to physical MIDI OUT.

---

## 2. Settings and Voice Allocation

You can change how incoming MIDI notes are allocated across the synthesizer's 4 voices. This parameter is configured in the `SYS` -> `V_MODE` menu (controlled by encoder 2):

- **V1 / V2 / V3 / V4** (values 0–3): Monophonic mode. Notes are routed strictly to the selected voice (1, 2, 3, or 4 respectively).
- **RR (Round Robin)** (value 4): Cyclic allocation. Each new note activates the next voice in order (1 -> 2 -> 3 -> 4 -> 1...).
- **RND (Random)** (value 5): Random distribution of notes across currently free voices.
- **OCT (Octave)** (value 6): Voice is selected based on the octave of the played note (1st octave — Voice 1, 2nd octave — Voice 2, etc.).

The `CH` parameter on the `SYS` page (encoder 3) sets the active MIDI channel from `1` to `16` (or `0` for Omni mode — receiving messages on all channels).

---

## 3. MIDI CC Map

### Granular Synthesis & FX Parameters

All sound parameters are controlled via the following CC codes (values `0-127` are automatically scaled to the physical range of each parameter):

| CC | Firmware Parameter | Default Value | Engine Range | Description |
| --- | --- | --- | --- | --- |
| **7** | `PARAM_MASTER_VOL` | 1.0 (100%) | `0.0 ... 1.0` | **Master Volume** of the granular synth. |
| **14**  | `PARAM_LFO_RATE` | 1.0 Hz | `0.1 ... 40.0 Hz` | **LFO Modulation Rate** (speed of cyclic parameter modulation). |
| **20**  | `PARAM_POS` | 0.5 (50%) | `0.0 ... 1.0` | **Sample Read Position** — point in the sample file where grains are fetched from. |
| **21**  | `PARAM_SIZE` | 0.1 s | `0.001 ... 1.0 s` | **Grain Size** — duration of an individual grain. |
| **22**  | `PARAM_DENS` | 20.0 Hz | `0.1 ... 100.0 Hz` | **Grain Density** — rate of new grain births (per second). |
| **23**  | `PARAM_PITCH` | 1.0 (1x) | Depends on mode | **Grain Pitch / Playback Speed** (in semitones, octaves, or multiplier). |
| **24**  | `PARAM_SAMPLE_IDX` | 0 | `0 ... NUM_SAMPLES-1` | **Sample Select** — index of playback audio file from memory. |
| **25**  | `PARAM_MAX_GRAINS` | 32 | `1 ... 32` | **Grain Limit** — max number of active simultaneous grains (voices). |
| **26**  | `PARAM_GRAIN_AMP`  | 0.8 | `0.0 ... 1.0` | **Grain Amplitude** — individual base volume of each grain. |
| **27**  | `PARAM_KEYTRACK` | 1.0 (100%) | `0.0 ... 1.0` | **Key Tracking** — degree to which grain pitch follows pressed MIDI notes. |
| **28**  | `PARAM_LFO_WAVE` | 0 | `0 ... 4` | **LFO Waveform** (0=sine, 1=triangle, 2=saw, 3=reverse saw, 4=random S&H). |
| **29**  | `PARAM_PITCH_MODE` | 0 | `0 ... 2` | **Pitch Mode** (0=SPEED continuous, 1=SEMI semitones, 2=OCT octaves). |
| **30**  | `PARAM_SCAN` | 0.0 | `-2.0 ... 2.0` | **Auto-Scan** — playhead movement speed across the sample. |
| **31**  | `PARAM_DIRECTION`  | 0.0 (0%) | `0.0 ... 1.0` | **Direction / Reverse** — probability of grains playing in reverse. |
| **15**  | `PARAM_SPREAD` | 0.0 (0%) | `0.0 ... 1.0` | **Stereo Spread** (Pan Spread) — random panning distribution of grains. |
| **16**  | `PARAM_SHAPE` | 0 | `0 ... 27` | **Grain Envelope Shape** — envelope morphing from smooth to sharp. |
| **71**  | `PARAM_RES` | 0.7 | `0.5 ... 13.0` | **Filter Resonance** — Q-factor of built-in filter (peak at cutoff). |
| **72**  | `PARAM_REL` | 0.3 s | `0.001 ... 5.0 s` | **Voice Release** — main volume envelope decay time after key release. |
| **73**  | `PARAM_ATK` | 0.01 s | `0.0 ... 5.0 s` | **Voice Attack** — main volume envelope attack time upon key press. |
| **74**  | `PARAM_CUTOFF` | 20000.0 Hz | `20.0 ... 20000.0 Hz` | **Filter Cutoff Frequency** — cutoff frequency of built-in voice filter. |
| **75**  | `PARAM_FILT_KEY` | 0.0 (0%) | `0.0 ... 1.0` | **Filter Key Tracking** — degree to which cutoff varies with key pitch. |
| **85**  | `PARAM_ATK_CURVE`  | 0.0 | `-1.0 ... 1.0` | **Attack Curve** — attack shape (logarithmic, linear, exponential). |
| **86**  | `PARAM_REL_CURVE`  | 0.0 | `-1.0 ... 1.0` | **Release Curve** — release shape (logarithmic, linear, exponential). |
| **87**  | `PARAM_LFO_PHASE`  | 0 | `0 ... 180` | **LFO Initial Phase** in degrees. |
| **89**  | `PARAM_LFO_SYNC` | 0 | `0 ... 5` | **LFO Sync** (per-voice or free running). |
| **90**  | `PARAM_VOL` | 0.7 | `0.0 ... 1.0` | **Voice Volume** (individual volume of active timbre). |
| **91**  | `PARAM_FX_MIX` | 0.0 (0%) | `0.0 ... 1.0` | **Effect Mix** (Dry/Wet mix for internal delay/reverb). |
| **92**  | `PARAM_MOD1_SRC` | 0 | `0 ... 24` | **Modulation Source 1** (modulation slot choice). |
| **93**  | `PARAM_MOD1_AMT` | 0.0 (0%) | `0.0 ... 1.0` | **Modulation Depth 1** (modulating signal amplitude). |
| **94**  | `PARAM_MOD2_SRC` | 0 | `0 ... 24` | **Modulation Source 2**. |
| **95**  | `PARAM_MOD2_AMT` | 0.0 (0%) | `0.0 ... 1.0` | **Modulation Depth 2**. |
| **96**  | `PARAM_FX_WF` | 0.0 | `0.0 ... 1.0` | **Effect Waveform** (type/character of effect modulation). |
| **97**  | `PARAM_FX_DS` | 1.0 | `1.0 ... 80.0` | **Downsampling** — sample rate reduction (Lo-Fi effect). |
| **98**  | `PARAM_FX_BC` | 16.0 | `1.0 ... 16.0` | **Bitcrusher** — bit depth reduction (8-bit/Lo-Fi effect). |
| **107** | `PARAM_FILT_TYPE`  | 3 (Off) | `0 ... 3` | **Filter Type** (0=Low-Pass, 1=High-Pass, 2=Band-Pass, 3=Off). |
| **109** | `PARAM_MIDI_MODE`  | 0 | `0 ... 6` | **Note Allocation Mode** across voices (polyphonic, Round Robin, etc.). |
| **118** | `PARAM_MIDI_CH` | 1 | `1 ... 16` | **MIDI Channel** — channel number on which notes/CC are received. |

### Interface Emulation (Buttons and Encoders)

Transmitting a value `>= 64` simulates a button Press, while `< 64` simulates a Release.

#### Matrix Buttons (16 buttons)

- **CC 40**: Matrix Button 1 (Row 1, Col 1 / Page select button 1)
- **CC 41**: Matrix Button 2 (Row 1, Col 2 / Page select button 2)
- **CC 42**: Matrix Button 3 (Row 1, Col 3 / Page select button 3)
- **CC 43**: Matrix Button 4 (Row 1, Col 4 / Page select button 4)
- **CC 44**: Matrix Button 5 (Row 2, Col 1)
- **CC 45**: Matrix Button 6 (Row 2, Col 2)
- **CC 46**: Matrix Button 7 (Row 2, Col 3)
- **CC 47**: Matrix Button 8 (Row 2, Col 4)
- **CC 48**: Matrix Button 9 (Row 3, Col 1)
- **CC 49**: Matrix Button 10 (Row 3, Col 2)
- **CC 50**: Matrix Button 11 (Row 3, Col 3)
- **CC 51**: Matrix Button 12 (Row 3, Col 4)
- **CC 52**: Matrix Button 13 (Row 4, Col 1 / Trigger 1)
- **CC 53**: Matrix Button 14 (Row 4, Col 2 / Trigger 2)
- **CC 54**: Matrix Button 15 (Row 4, Col 3 / Trigger 3)
- **CC 55**: Matrix Button 16 (Row 4, Col 4 / Trigger 4)

#### Encoder Emulation (4 Knobs / Relative Mode)

Encoders send and receive relative values (values $\le 63$ decrement the parameter, $\ge 65$ increment the parameter):

- **CC 110**: Encoder 1 Rotation
- **CC 111**: Encoder 2 Rotation
- **CC 112**: Encoder 3 Rotation
- **CC 113**: Encoder 4 Rotation

### Preset Management

The following CC codes are used for loading and saving presets:

| CC | Function | Value Range | Description |
| --- | --- | --- | --- |
| **32** | Preset Load | `0-15` | Load preset from slot |
| **33** | Preset Save | `0-15` | Save current preset to slot |

### Standard Performance Messages

- **Pitch Bend**: Pitch wheel. Bends overall pitch of active voices.
- **CC 1**: Modulation Wheel (Modwheel). Controls depth of assigned modulation signal.
- **Aftertouch**: Key pressure. Sends pressure data for modulation.
- **CC 64**: Sustain Pedal. Holds envelopes open, preventing grain decay until pedal release.

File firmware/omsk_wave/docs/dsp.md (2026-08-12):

# OMSK Synth — DSP Technical Specification

This document provides a mathematical description of the summing, mixing, and modulation algorithms used in the DSP core of OMSK Synth.

---

## 1. Mixer Summing

To prevent digital clipping while maintaining a stable volume level when playing multiple voices, a power conservation law normalization system (Square Root Compensation) is applied.

### Voice Mixer

Within each of the 4 voices, three sources (VCO1, VCO2, Noise) are mixed using a compensation table. For optimization, the LUT `lut_gain[128]` is used:
$$g[i] = \sqrt{\frac{i}{127}}$$

Single voice mix formula:
$$V_{voice} = \frac{g_1 \cdot VCO_1 + g_2 \cdot VCO_2 + g_3 \cdot Noise}{\sqrt{g_1^2 + g_2^2 + g_3^2} + \epsilon}$$

_Where $\epsilon = 10^{-9}$ is a small value to prevent division by zero._

---

### Polyphonic Summing (4 Voices)

When playing chords (up to 4 voices simultaneously), each voice has its own **Velocity** level. To prevent digital overload (clipping), summing is performed with normalization based on the square root of the sum of powers.

#### Velocity Weighting

For each voice $n$, a weight $W_n$ is calculated based on key velocity:
$$W_n = \sqrt{\frac{Velocity_n}{127}}$$

#### Final Summing Algorithm

Let $S_n$ be the final signal of voice $n$ (after mixer, filter, and VCA envelope).

1. **Signal Summing:** Sum all signals multiplied by their individual Velocity weight:
   $$Sum = \sum_{n=1}^{4} (S_n \cdot W_n)$$

2. **Normalization Factor Calculation:** Calculate the square root of the sum of squared weights for all active voices:
   $$Norm = \sqrt{\sum_{n=1}^{4} W_n^2 + \epsilon}$$

3. **Final Output:**
   $$Out = \frac{Sum}{Norm}$$

#### Pseudocode Implementation Example

```c
// Calculate weights for each voice (typically on note press)
float w[4];
for(int n=0; n<4; n++) {
    w[n] = lut_gain[velocity[n]];
}

// In each audio block:
float voice_sum = 0;
float power_sum = 0;

for(int n=0; n<4; n++) {
    if (voice_active[n]) {
        voice_sum += voice_signal[n] * w[n];
        power_sum += w[n] * w[n]; // Weight squared
    }
}

// Square root normalization
float output = voice_sum / (sqrt(power_sum) + 1e-9f);
```

---

## 2. Mathematical Model for Slow Modulation (LFO, EG, ModWheel)

Any parameter (knob) supports assignment of one of the sources: LFO1, LFO2, EG1, EG2, ModWh. Modulation depth $D$ is specified in range $[-1.0; +1.0]$ ($-100\%$ to $+100\%$).

### Data Separation

- $K$: Base user-set value (UI). Not altered by modulation.
- $K_{mod}$: Final value for DSP, clamped to range $[K_{min}; K_{max}]$.

### Signal Preparation (Normalization)

All incoming signals $S_{raw}$ are converted to a unified unipolar representation $M \in [0; 1]$.

| Source | Original Range | Transformation to $M$ | Note |
| --- | --- | --- | --- |
| **LFO** | $[-1; +1]$ | $M = (S_{raw} + 1) / 2$ | Shift up and halve |
| **EG** | $[0; 1]$ | $M = S_{raw}$ | Already unipolar |
| **ModWh** | $[0; 127]$ | $M = S_{raw} / 127$ | Normalized to $[0; 1]$ |

### Offset Calculation ($\Delta K$)

The signal always moves either strictly "upwards" or "downwards" relative to $K$:

- $U = K_{max} - K$ (headroom up)
- $Down = K - K_{min}$ (headroom down)

**Offset Formula:**

- If $D \ge 0$: $\Delta K = M \cdot D \cdot U$
- If $D < 0$: $\Delta K = M \cdot D \cdot Down$

### Calculation Pseudocode

```c
// Executed when K changes (user knob adjustment)
float U = K_max - K;
float Down = K - K_min;

// Executed every audio cycle (DSP)
float deltaK = 0.0f;

if (D > 0) {
    deltaK = M * D * U;
} else if (D < 0) {
    deltaK = M * D * Down; // D is negative, deltaK will be <= 0
} else {
    deltaK = 0.0f; // Case D = 0
}

float K_mod = clamp(K + deltaK, K_min, K_max);
```

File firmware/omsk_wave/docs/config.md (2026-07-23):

# Synth Firmware Configuration (`omsk_synth`)

All hardware and software settings for the synthesizer are specified at compile-time using C/C++ preprocessor macros. They are divided into two header files:

1. `shared/hw_config.h` — hardware parameters (pins, overclocking, LED brightness).
2. `omsk_synth/src/sw_config.h` — parameters for sound engine, display, MIDI, and interface.

---

## 1. Hardware Settings (`shared/hw_config.h`)

This file is shared between the synthesizer and granular firmwares.

### LED Brightness Setting

The maximum brightness limit for WS2812 LEDs is set using the `RGB_MAX_BRIGHTNESS` macro (value range `0` to `255`, default is set to `63` for comfortable glare-free lighting):

```c
#define RGB_MAX_BRIGHTNESS 63
```

### CPU Frequency (Overclock)

The system clock frequency is set depending on the chip used (RP2040 or RP2350):

```c
#ifdef PICO_RP2040
#define CFG_OVERCLOCK_KHZ 133000 // For RP2040 (133 MHz)
#else
#define CFG_OVERCLOCK_KHZ 240000 // For RP2350 (240 MHz)
#endif
```

### Physical Pin Assignments (Pinout)

- **Keyboard Matrix**: `PIN_MATRIX_ROW1..4` and `PIN_MATRIX_COL1..4`
- **Encoders**: `PIN_ENCODER1..4_A` and `PIN_ENCODER1..4_B`
- **Audio Outputs**:
  - PWM: `PIN_AUDIO_PWM_L` (GPIO 29) and `PIN_AUDIO_PWM_R` (GPIO 16)
  - I2S DAC: `PIN_DAC_I2S_BCK` (GPIO 17), `PIN_DAC_I2S_LRCK` (GPIO 18), `PIN_DAC_I2S_DATA` (GPIO 19)
- **OLED Display (I2C)**: `PIN_OLED_SDA` (GPIO 20) and `PIN_OLED_SCL` (GPIO 21)
- **RGB LEDs**: `PIN_RGB_LED` (GPIO 8)
- **MIDI Jack (Serial)**: `PIN_MIDI_JACK_OUT` (GPIO 0) and `PIN_MIDI_JACK_IN` (GPIO 1)

---

## 2. System Settings (`omsk_synth/src/sw_config.h`)

These parameters are specific to the synthesizer engine.

### Audio Outputs and Volume

- `CFG_MASTER_VOLUME_PERCENT` — master volume percentage (default `100`).
- `CFG_ENABLE_USB_AUDIO` — experimental USB audio output (1 — on, 0 — off).
- `CFG_ENABLE_PWM8_AUDIO` — monophonic 8-bit PWM output.
- `CFG_ENABLE_DAC` — stereo 16-bit / 48 kHz output via I2S DAC.

### OLED Display and Interface

- `CFG_ENABLE_OLED` — enables display driver.
- `CFG_SLEEP_TIMEOUT_MIN` — sleep mode timeout in minutes (0 — disabled, >0 — sleep after N minutes). When sleeping, OLED display and RGB LEDs turn off. Wake-up occurs on any physical interaction (button presses, encoder turns) or receiving MIDI messages.
- `CFG_LOGO_SUBTITLE` — firmware version subtitle string on boot logo (e.g., `"v1.0-dev"`).
- `CFG_ENABLE_RGB_LED` — enables RGB LEDs.

### MIDI Settings

- `CFG_ENABLE_USB_MIDI` — enables MIDI rx/tx over USB.
- `CFG_ENABLE_JACK_MIDI` — enables TRS MIDI IN/OUT jacks.
- `CFG_ENABLE_MIDI_THRU` — enables forwarding incoming MIDI stream directly to MIDI OUT (1 — on, 0 — off).
- `CFG_PITCH_BEND_RANGE_SEMITONES` — Pitch Bend range in semitones (default `2`).

### Synthesizer Engine Modes (Filter, EG, OSC)

You can choose calculation modes to optimize CPU load:

- **Filter Selection (`CFG_FILTER_MODE`)**:
  - `FILTER_MODE_PRA32_TABLES` (0) — table-based with LPF steps based on [digital-synth-pra32-u2](https://github.com/risgk/digital-synth-pra32-u2) (high quality, low CPU overhead, LUT size ~2.6 MB).
  - `FILTER_MODE_MORPH_SVF` (1) — real-time filter math (~8% load per voice, 0 bytes LUT size).
  - `FILTER_MODE_3_TABLES` (2) — interpolation across 3 tables (~2.2% load per voice, LUT size ~1.4 MB).
  - `FILTER_MODE_MOOG_LADDER` (3) — high quality Moog Ladder 24 dB/oct filter (LUT size ~7.4 KB, ~5.5% load per voice).
- **Envelope Modes (`CFG_EG_MODE`)**: `EG_MODE_TABLE` (table envelope) or `EG_MODE_CALC` (mathematical calculation).
- **LFO Modes (`CFG_LFO_MODE`)**: `LFO_MODE_TABLE` (table LFO) or `LFO_MODE_CALC` (mathematical calculation).

### Overclocking and Logging

- `CFG_ENABLE_OVERCLOCK` — enables CPU overclocking (150 MHz for RP2040, 240 MHz for RP2350).
- `CFG_ENABLE_DEBUG` — enables debug log output via USB serial (macro `DBG_PRINTF` can be used).

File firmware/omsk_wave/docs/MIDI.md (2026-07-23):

# Complete MIDI CC Documentation for Synth Firmware (`omsk_synth`)

This file contains a comprehensive description of all MIDI Control Change (MIDI CC) messages for the synthesizer firmware. The device allows full control over synthesis parameters, built-in sequencer, Hold function, and emulating physical button presses/encoder rotations.

---

## 1. Synthesizer and Effects Parameters

All parameters related to sound and modulation are controlled by the following CC codes:

| CC | Firmware Parameter | Default Value | Value Range | Description |
| --- | --- | --- | --- | --- |
| **7** | `PARAM_AMP_GAIN` | 100 (100%) | `0-127` | **Master Volume** of the synthesizer. |
| **9** | `PARAM_VCF1_DRIVE` | 0 | `0-127` | **VCF1 Drive** (saturation/overdrive level for VCF1 filter). |
| **10**  | `PARAM_PAN` | 64 (Center) | `0-127` | **Stereo Pan** (0 — left only, 127 — right only). |
| **14**  | `PARAM_LFO1_RATE` | 10 (~1 Hz) | `0-127` | **LFO1 Rate** (modulation speed). |
| **20**  | `PARAM_VCO1_TRANSPOSE` | 5 (0 oct.) | `0-10` | **VCO1 Transpose** coarse octaves (5 = 0, range +/- 5 octaves). |
| **21**  | `PARAM_VCO1_DETUNE` | 64 (0 c) | `0-127` | **VCO1 Detune** fine (+/- 100 cents). |
| **22**  | `PARAM_VCO1_SHAPE` | 0 | `0-127` | **VCO1 Shape** (smooth morph / pulse width symmetry). |
| **23**  | `PARAM_VCO2_TRANSPOSE` | 5 (0 oct.) | `0-10` | **VCO2 Transpose** coarse octaves (5 = 0, range +/- 5 octaves). |
| **24**  | `PARAM_VCO2_DETUNE` | 64 (0) | `0-127` | **VCO2 Detune** fine (+/- 100 cents). |
| **25**  | `PARAM_VCO2_WAVE` | 0 | `0-127` | **VCO2 Base Waveform** (selection from wavetable bank). |
| **26**  | `PARAM_VCO2_SHAPE` | 0 | `0-127` | **VCO2 Shape** (morph / PWM for VCO2). |
| **27**  | `PARAM_VCF2_MIX` | 127 (100%) | `0-127` | **VCF2 Mix** (level of filtered signal from 2nd filter in mix). |
| **28**  | `PARAM_LFO1_WAVE` | 0 | `0-127` | **LFO1 Waveform** (0=sine, triangle, saw, reverse saw, random/S&H). |
| **29**  | `PARAM_LFO1_SHAPE` | 0 | `0-127` | **LFO1 Shape** (distortion or phase shift). |
| **30**  | `PARAM_LFO2_RATE` | 0 | `0-127` | **LFO2 Rate** (speed of 2nd LFO). |
| **31**  | `PARAM_LFO2_SMOOTH` | 0 | `0-127` | **LFO2 Smooth** (removes sharp edges for smoother modulation). |
| **56**  | `PARAM_VCF2_DRIVE` | 0 | `0-127` | **VCF2 Drive** (saturation level for VCF2). |
| **57**  | `PARAM_VCF1_MIX` | 127 (100%) | `0-127` | **VCF1 Mix** (level of 1st filter in mix). |
| **58**  | `PARAM_FX1_TIME` | 64 | `0-127` | **Chorus (FX1) Time** (delay line time). |
| **59**  | `PARAM_FX1_FEEDBACK` | 64 | `0-127` | **Chorus (FX1) Feedback**. |
| **60**  | `PARAM_FX1_SPREAD` | 64 | `0-127` | **Chorus (FX1) Depth**. |
| **61**  | `PARAM_FX1_MIX` | 0 | `0-127` | **Chorus (FX1) Wet/Dry Mix**. |
| **62**  | `PARAM_MOD_ROUTING1` | 0 | `0-127` | **Modulation Slot 1 Routing**. |
| **63**  | `PARAM_MOD_DEPTH1` | 0 | `0-127` | **Modulation Slot 1 Depth**. |
| **65**  | `PARAM_MOD_ROUTING2` | 0 | `0-127` | **Modulation Slot 2 Routing**. |
| **67**  | `PARAM_MOD_DEPTH2` | 0 | `0-127` | **Modulation Slot 2 Depth**. |
| **68**  | `PARAM_SUB_OSC` | 0 | `0-127` | **Sub-Oscillator Volume**. |
| **69**  | `PARAM_LFO_OSC_DST` | 0 | `0-127` | **LFO to Oscillator Destination**. |
| **70**  | `PARAM_VCO1_WAVE` | 0 | `0-127` | **VCO1 Base Waveform** (selection from wavetable bank). |
| **71**  | `PARAM_VCF1_RES` | 64 | `0-127` | **VCF1 Resonance** (Q-factor of 1st filter channel). |
| **72**  | `PARAM_EG1_RELEASE` | 0 | `0-127` | **EG1 Release Time** (volume envelope release time). |
| **73**  | `PARAM_EG1_ATTACK` | 0 | `0-127` | **EG1 Attack Time** (volume envelope attack time). |
| **74**  | `PARAM_VCF1_CUTOFF` | 112 | `0-127` | **VCF1 Cutoff Frequency** (first low-pass or band-pass filter). |
| **75**  | `PARAM_VCF_KEY_TRACK` | 0 | `0-127` | **Filter Key Tracking** — filter opens further on higher notes. |
| **76**  | `PARAM_VCF_EG_AMT` | 0 | `0-127` | **Filter Envelope Amount** (EG Amount to cutoff). |
| **77**  | `PARAM_VCF2_CUTOFF` | 127 | `0-127` | **VCF2 Cutoff Frequency**. |
| **78**  | `PARAM_VCF2_RES` | 64 | `0-127` | **VCF2 Resonance**. |
| **79**  | `PARAM_EG_OSC_DST` | 0 | `0-127` | **Envelope to Oscillator Destination**. |
| **80**  | `PARAM_NOISE_COLOR` | 64 | `0-127` | **Noise Color** (pink, white, blue). |
| **81**  | `PARAM_ARP_RATE` | 12 | `0-17` | **Arpeggiator Rate** (synced divisions or free rate). |
| **82**  | `PARAM_ARP_MODE` | 0 (Off) | `0-5` | **Arpeggiator Mode** (0=Off, 1=Up, 2=Down, 3=Up-Down, 4=Random, 5=Drunk). |
| **83**  | `PARAM_ARP_SWING` | 0 | `0-127` | **Arpeggiator Swing**. |
| **84**  | `PARAM_EG_AMP_MOD` | 0 | `0-127` | **Volume EG Modulation** (EG Depth on VCA). |
| **85**  | `PARAM_EG2_ATTACK` | 0 | `0-127` | **EG2 Attack Time** (filter/oscillator modulation envelope). |
| **86**  | `PARAM_EG2_DECAY` | 0 | `0-127` | **EG2 Decay Time**. |
| **87**  | `PARAM_EG2_SUSTAIN` | 127 | `0-127` | **EG2 Sustain Level**. |
| **88**  | `PARAM_MIX_PHASE2` | 0 | `0-127` | **VCO2 Phase Offset** relative to VCO1. |
| **89**  | `PARAM_EG2_RELEASE` | 0 | `0-127` | **EG2 Release Time**. |
| **90**  | `PARAM_MIX_VCO2_VOL` | 127 | `0-127` | **VCO2 Mixer Volume**. |
| **91**  | `PARAM_FX2_MIX` | 0 | `0-127` | **Delay/Reverb (FX2) Wet/Dry Mix**. |
| **92**  | `PARAM_FX2_TIME` | 64 | `0-127` | **Delay Time**. |
| **93**  | `PARAM_FX2_FEEDBACK` | 64 | `0-127` | **Delay Feedback**. |
| **94**  | `PARAM_FX2_TONE` | 127 | `0-127` | **Delay Tail Tone** (high/low pass filtering in feedback loop). |
| **95**  | `PARAM_EG_VEL_SENS` | 0 | `0-127` | **Velocity Sensitivity to EG**. |
| **96**  | `PARAM_AMP_VEL_SENS` | 0 | `0-127` | **Velocity Sensitivity to Volume**. |
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

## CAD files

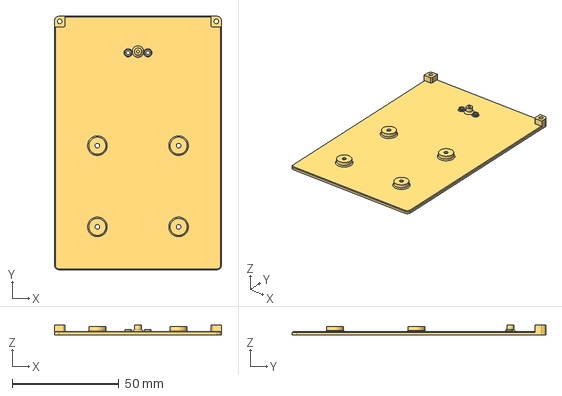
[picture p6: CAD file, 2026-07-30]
hardware/case/bot-omsk-mc.step
78.3 x 119.0 x 4.80 mm
bot-omsk001
M-bot-omsk002

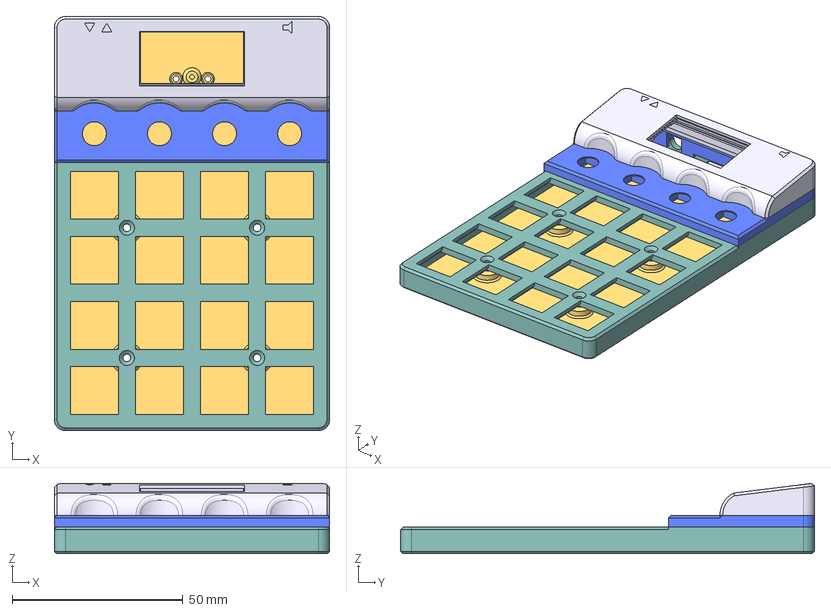
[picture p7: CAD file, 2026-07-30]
hardware/case/CAD/Omsk-rounded.step
80.5 x 121.1 x 20.5 mm
top-omsk
top-encoders-panel-omsk
bot-omsk001
M-bot-omsk002
infopanel-omsk-rounded-io-description-cutted
io-description-omsk003
infopanel-omsk-screen-clip

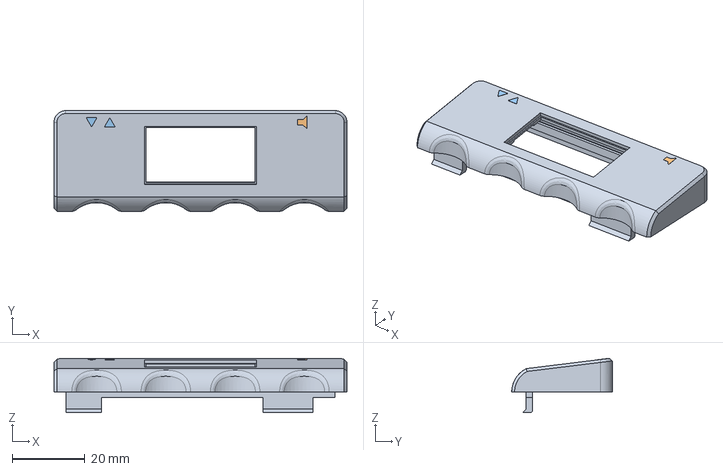
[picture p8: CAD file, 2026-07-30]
hardware/case/infopanel-omsk-rounded-mc.step
80.5 x 27.7 x 14.9 mm
infopanel-omsk-rounded-io-description-cutted
io-description-omsk003

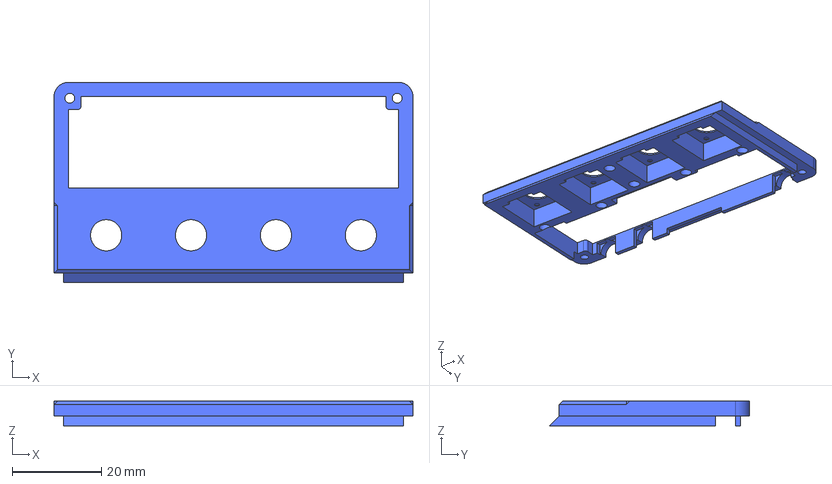
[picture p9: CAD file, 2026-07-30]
hardware/case/top-encoders-panel-omsk.step
80.5 x 44.9 x 5.60 mm

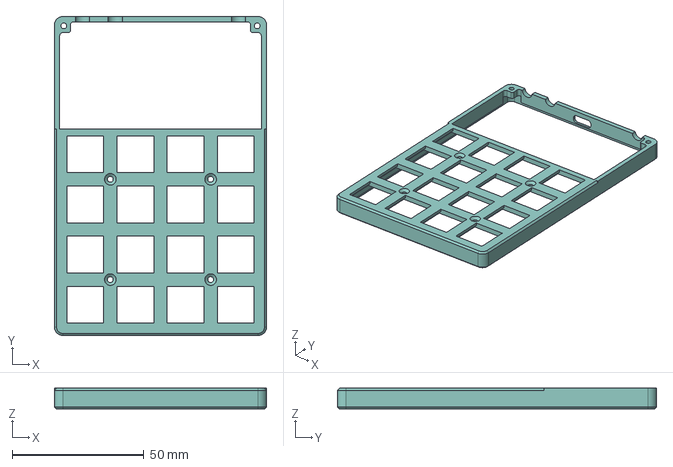
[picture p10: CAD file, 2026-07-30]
hardware/case/top-omsk.step
80.5 x 121.1 x 7.80 mm

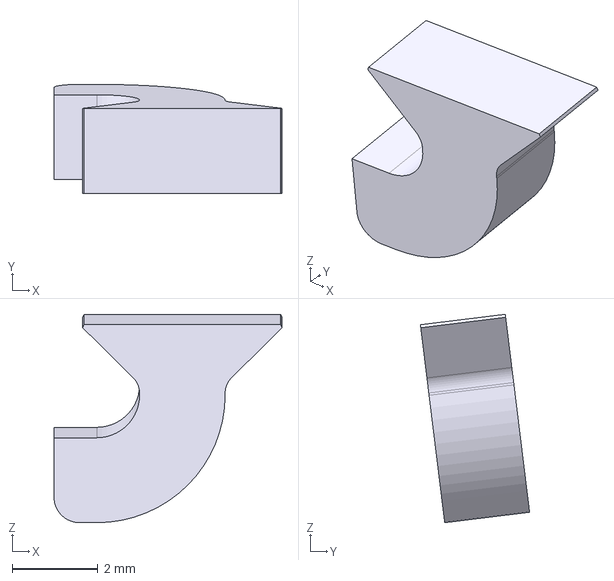
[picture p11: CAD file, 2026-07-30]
hardware/case/infopanel-omsk-screen-clip.step
5.33 x 2.55 x 4.87 mm

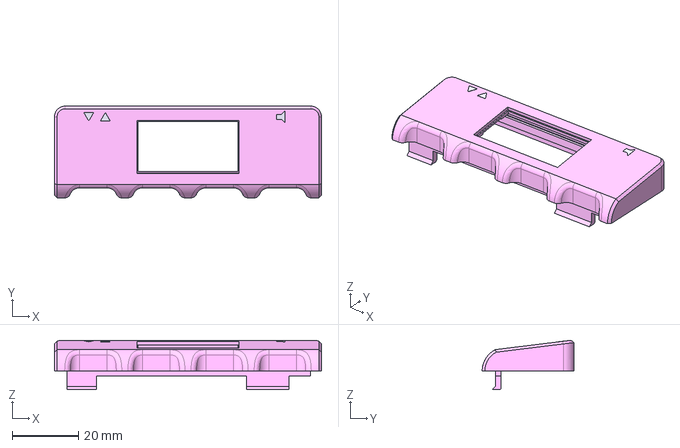
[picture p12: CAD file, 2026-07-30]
hardware/case/infopanel-omsk-ledsvisible-mc.step
80.5 x 27.7 x 14.9 mm
infopanel-omsk-ledsvisible-io-description-cutted
io-description-omsk004

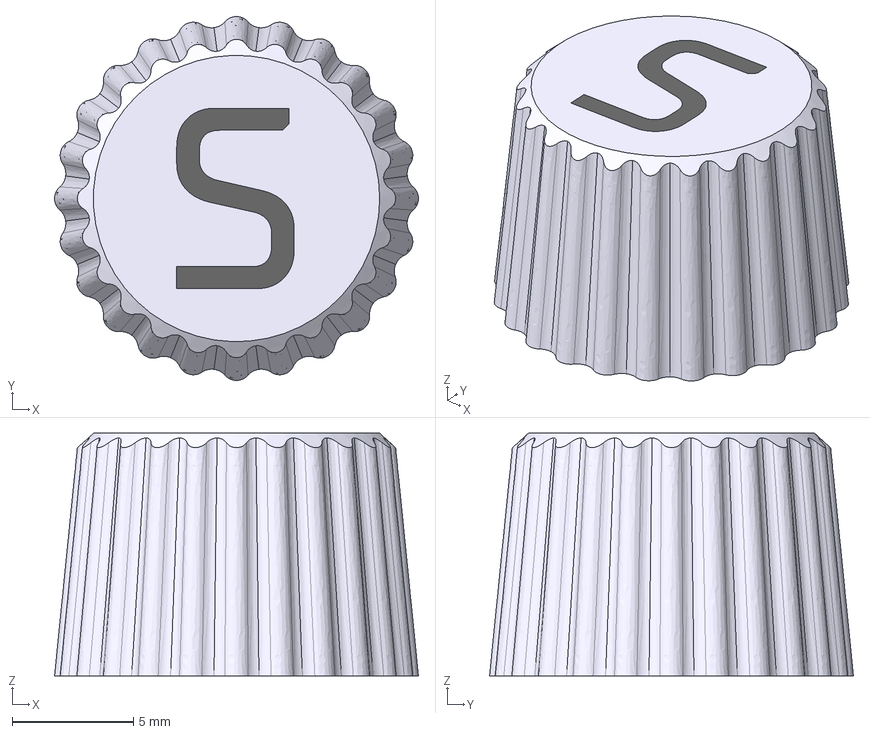
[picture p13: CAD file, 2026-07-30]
hardware/case/knob-S-mc.step
15.0 x 15.0 x 10.0 mm
knob-s-cutted
svg-S-knob-e

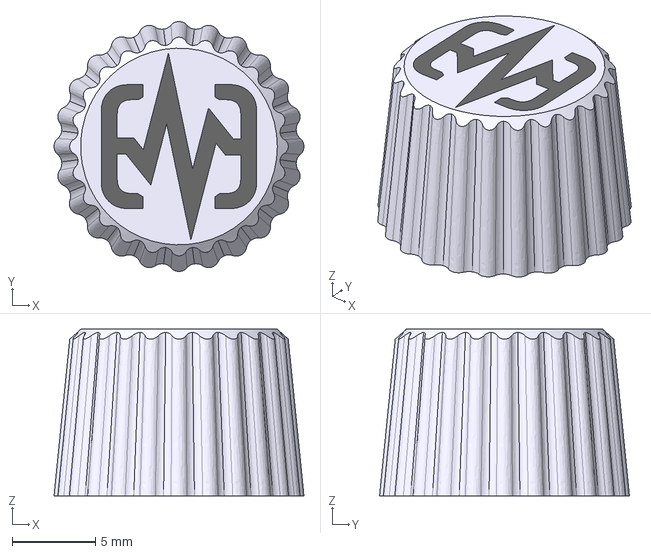
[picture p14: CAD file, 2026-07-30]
hardware/case/knob-M-mc.step
15.0 x 15.0 x 10.0 mm
knob-m-cutted
svg-M-knob-e

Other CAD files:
hardware/case/CAD/Omsk-ledsvisible.step
hardware/case/knob-K-mc.step
hardware/case/knob-O-mc.step

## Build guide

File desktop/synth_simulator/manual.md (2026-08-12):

# PySide6 Analog Synth User Manual

## Overview

The synthesizer supports 8-voice polyphony, vector audio processing (NumPy), flexible signal routing, and deep parameter modulation.

## Operating Modes

The synthesizer has two main button grid display modes. Toggle between modes using the key combination **Z + X**.

### 1. PIANO Mode

The main mode for musical performance.

- **Grid**: Displays playable notes across 3 rows and octave controls on the bottom row.
- **Z Key**: Functions as **OCT-** (shift octave down).
- **Visual Status**:
  - Active played notes light up.
  - If **HOLD** mode is enabled, the **OCT-** key (bottom-left) turns pink.
  - Latched notes in HOLD mode are highlighted in pink.

### 2. Params Mode

The mode for module selection, signal routing, and synth parameter editing.

- **Grid**: Displays module names (`VCO1`, `VCF1`, `LFO1`, `SET`, etc.).
- **Z Key**: Functions as the **HOLD** toggle button.
- **Navigation**: Pressing a module button assigns its parameters to the 4 top knobs.

## Signal Path

The synthesizer utilizes flexible routing. By default, all sound sources bypass filters and route directly to the mixer (Direct Out).

1. **Sources**: `VCO1`, `VCO2`, `NOISE`.
2. **Filter Routing**:
   - Each source can be routed into **VCF1** or **VCF2**.
   - If a source is **not** routed into a filter, it bypasses filtering directly to the mixer section (Dry/Direct signal).
3. **Filters**: `VCF1` and `VCF2` process their incoming source signals.
4. **Mixer**: Sums the outputs from filters and direct dry sources.
5. **FX**: The master sum passes through the Delay effect module.

## Modules and Parameters

### VCO1 / VCO2 (Oscillators)

- **Transpose**: Coarse tuning (+/- 5 octaves).
- **Detune**: Fine tuning (+/- 100 cents).
- **Wave**: Continuous waveform morphing (Sine -> Triangle -> Saw -> Square -> Pulse).
- **Shape**: Waveform shape modification (PWM for Pulse, Saturation for Sine, Morph for Saw).

### Noise

- **Color**: Modifies noise frequency spectrum (pink > white > blue).

### VCF1 / VCF2 (Filters)

- **Cutoff**: Cutoff frequency (50 Hz - 8000 Hz, exponential scale).
- **Res**: Filter resonance.
- **Drive**: Input overdrive & saturation.
- **Mix**: Filter Dry/Wet balance.

### LFO1 / LFO2 (Low Frequency Oscillators)

- **Rate**: LFO frequency (0 - 20 Hz).
- **Wave**: LFO waveform shape.
- **Shape**: Waveform skew / duty cycle modification.
- **Smooth**: LFO output smoothing filter.

### EG1 / EG2 (Envelope Generators)

Classic ADSR envelopes.

- **Attack**: Attack time.
- **Decay**: Decay time.
- **Sustain**: Sustain level.
- **Release**: Release time.

### MIXER

- **VCO1/2 Bal**: Crossfade balance between **VCO1** and **VCO2**.
- **Phase 1-2**: Phase offset between **VCO1** and **VCO2**.
- **VCO/Noise**: Mix balance between combined oscillators (**VCO1+VCO2**) and Noise.
- **Master Vol**: Master output volume.

### FX (Delay Effect)

The effect is applied on the Master bus.

- **Time**: Delay time between original signal and echoes.
- **Fdbk**: Feedback amount (repeats).
- **Mix**: Effect Dry/Wet blend.
- **Tone**: Timbre / filter tone of echoes (darker/brighter).

### ARP (Arpeggiator)

Generates note patterns based on held keys.

- **Rate**: Arpeggiator speed (0 - 5 Hz).
- **Mode**: Pattern mode (OFF, UP, DOWN, UP-DOWN, PING-PONG, RND).
- **Var**: Pattern variation (select first N notes from note buffer).
- **Oct**: Octave range (1 - 4 octaves).

### GLIDE (Portamento)

Sets smooth pitch glide transition between notes.

- **Poly**: Polyphony voice count (1 - 4).
- **Time**: Glide duration (0 - 1000 ms).
- **Slope**: Pitch slide response curve (Lin/Exp).
- **Mode**: Operating mode (Off, Legato, Always).
  - **Off**: Disabled.
  - **Legato**: Glide only when playing tied notes.
  - **Always**: Continuous pitch sliding between all notes.

### HOLD Mode

- Activated via the **HOLD** button.
- Holds played notes in memory.
- Allows performing over latched notes.
- **Toggle-Off**: Pressing a latched (pink) note key again releases it.

## SET and RM Matrix System

### SET Mode (Assign and Edit Modulation / Routing)

Used to establish modulation connections and signal routing.

1. **Assign Modulation**:
   - Select a modulator source (`LFO1/2` or `EG1/2`).
   - Press **SET** (turns pink).
   - Navigate to the target module (e.g., `VCO1`).
   - Click on the **parameter knob** (e.g., `Pitch`).
   - Modulation link is created (default depth 50%).
2. **Edit Depth**:
   - If a modulation connection already exists, press **SET**.
   - Parameter label turns **RED**, and depth indicator bar appears underneath.
   - Turn the knob to adjust modulation depth.
   - Press **SET** again to exit edit mode.
3. **Audio Routing**:
   - Select target filter (`VCF1` or `VCF2`).
   - Press **SET**.
   - Press source button (`VCO1`, `VCO2`, `NOISE`).
   - Source is now routed through this filter.

### RM Mode (Remove Modulation / Routing)

Used to unbind links.

1. **Remove Modulation**:
   - Press **RM** (turns red).
   - Select module and click parameter knob -> removes modulation link for this parameter.
2. **Reset Routing**:
   - Press **RM**.
   - Press source button (`VCO1`...) -> resets routing back to Direct Out.
3. **Clear All Modulator Routes**:
   - Press **RM**.
   - Press modulator button (`LFO1`...) -> clears all assigned targets for this modulator.

## Hotkeys

- 16 onscreen grid buttons map to keyboard keys `[1,2,3,4]`, `[q,w,e,r]`, `[a,s,d,f]`, `[z,x,c,v]`.
- **SET + RM**: Save current configuration to `config.json`.

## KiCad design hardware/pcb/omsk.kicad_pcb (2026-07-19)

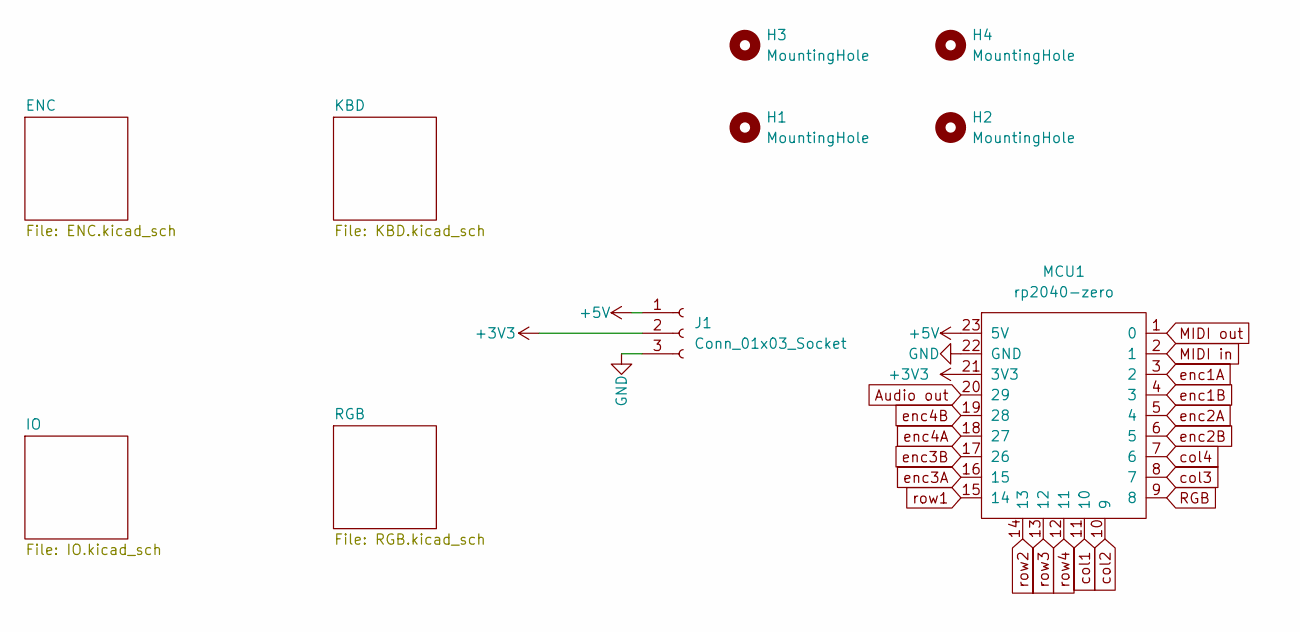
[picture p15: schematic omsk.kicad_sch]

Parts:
H1, H2, H3, H4: MountingHole
J1: Conn_01x03_Socket; PinHeader_1x03_P2.54mm_Vertical
MCU1: rp2040-zero; MCU_rp2040-zero

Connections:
+3V3: J1.2, MCU1.21 (3V3); also elsewhere on the board
+5V: J1.1, MCU1.23 (5V); also elsewhere on the board
Audio out: MCU1.20 (29); also elsewhere on the board
GND: J1.3, MCU1.22 (GND); also elsewhere on the board
MIDI in: MCU1.2 (1); also elsewhere on the board
MIDI out: MCU1.1 (0); also elsewhere on the board
RGB: MCU1.9 (8); also elsewhere on the board
col1: MCU1.11 (10); also elsewhere on the board
col2: MCU1.10 (9); also elsewhere on the board
col3: MCU1.8 (7); also elsewhere on the board
col4: MCU1.7 (6); also elsewhere on the board
enc1A: MCU1.3 (2); also elsewhere on the board
enc1B: MCU1.4 (3); also elsewhere on the board
enc2A: MCU1.5 (4); also elsewhere on the board
enc2B: MCU1.6 (5); also elsewhere on the board
enc3A: MCU1.16 (15); also elsewhere on the board
enc3B: MCU1.17 (26); also elsewhere on the board
enc4A: MCU1.18 (27); also elsewhere on the board
enc4B: MCU1.19 (28); also elsewhere on the board
row1: MCU1.15 (14); also elsewhere on the board
row2: MCU1.14 (13); also elsewhere on the board
row3: MCU1.13 (12); also elsewhere on the board
row4: MCU1.12 (11); also elsewhere on the board

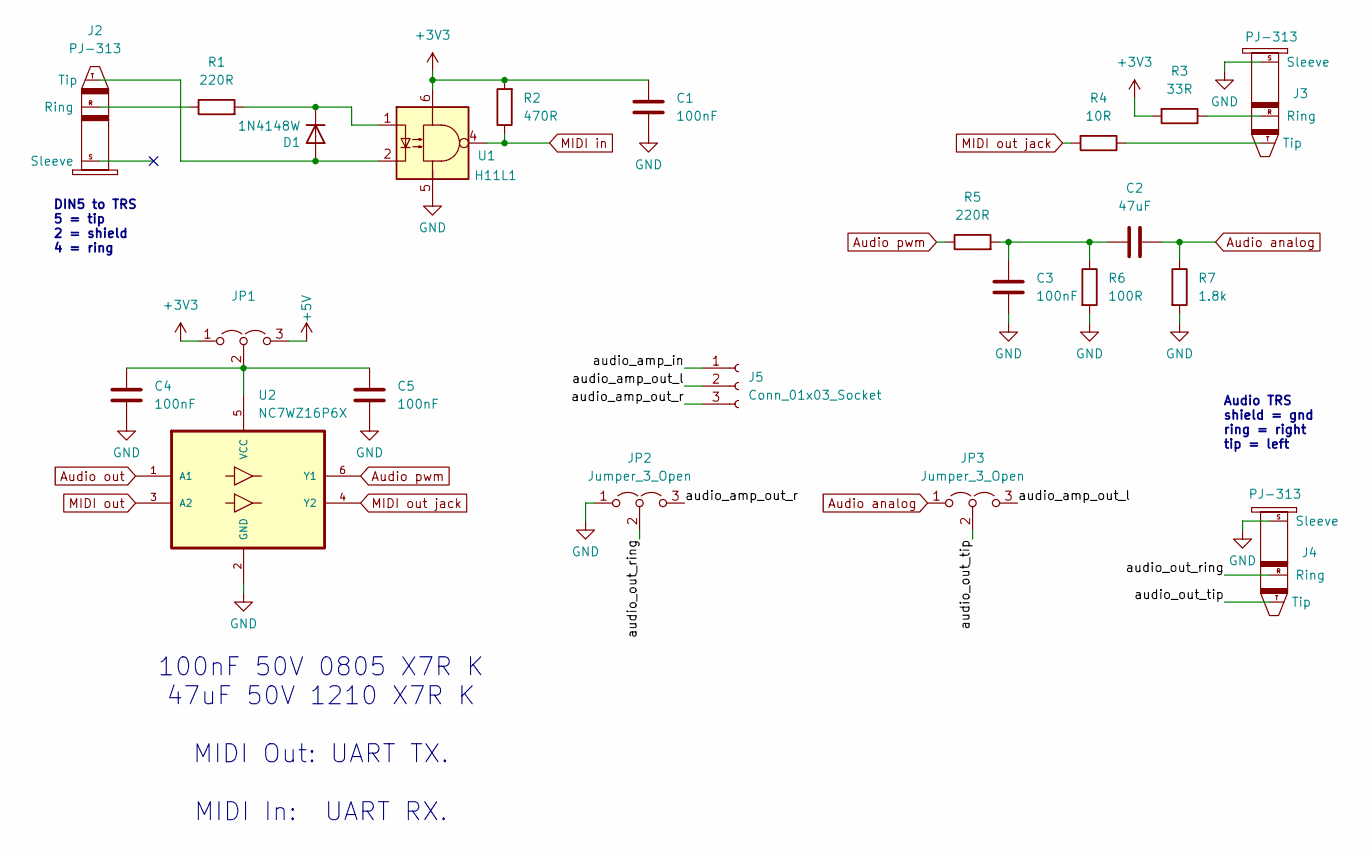
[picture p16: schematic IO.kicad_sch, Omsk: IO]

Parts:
C1, C3, C4, C5: 100nF; C_0805_2012Metric_Pad1.18x1.45mm_HandSolder
C2: 47uF; C_1210_3225Metric_Pad1.33x2.70mm_HandSolder
D1: 1N4148W; D_SOD-323_1side
J2, J3, J4: PJ-313; JACK_PJ-313A_1side
J5: Conn_01x03_Socket; PinHeader_1x03_P2.54mm_Vertical
JP1, JP2, JP3: Jumper_3_Open; SolderJumper-3_P1.3mm_Open_RoundedPad1.0x1.5mm
R1, R5: 220R; R_0603_1608Metric_1side
R2: 470R; R_0603_1608Metric_1side
R3: 33R; R_0603_1608Metric_1side
R4: 10R; R_0603_1608Metric_1side
R6: 100R; R_0603_1608Metric_1side
R7: 1.8k; R_0603_1608Metric_1side
U1: H11L1; DIP-6_W8.89mm_SMDSocket_LongPads
U2: NC7WZ16P6X; SOT65P210X110-6N; MPN NC7WZ16P6X

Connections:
+3V3: C1.1, JP1.1 (A), R2.2, R3.2, U1.6; also elsewhere on the board
+5V: JP1.3 (B); also elsewhere on the board
/IO/audio_amp_in: J5.1
/IO/audio_amp_out_l: J5.2, JP3.3 (B)
/IO/audio_amp_out_r: J5.3, JP2.3 (B)
/IO/audio_out_ring: J4.R (Ring), JP2.2 (C)
/IO/audio_out_tip: J4.T (Tip), JP3.2 (C)
Audio analog: C2.2, JP3.1 (A), R7.1
Audio out: U2.1 (A1); also elsewhere on the board
Audio pwm: R5.1, U2.6 (Y1)
GND: C1.2, C3.1, C4.2, C5.2, J3.S (Sleeve), J4.S (Sleeve), JP2.1 (A), R6.2, R7.2, U1.5, U2.2 (GND); also elsewhere on the board
MIDI in: R2.1, U1.4; also elsewhere on the board
MIDI out: U2.3 (A2); also elsewhere on the board
MIDI out jack: R4.2, U2.4 (Y2)
unnamed: C2.1, C3.2, R5.2, R6.1
unnamed: D1.2 (A), J2.T (Tip), U1.2
unnamed: D1.1 (K), R1.2, U1.1
unnamed: J2.R (Ring), R1.1
unnamed: J3.R (Ring), R3.1
unnamed: J3.T (Tip), R4.1
unnamed: C4.1, C5.1, JP1.2 (C), U2.5 (VCC)

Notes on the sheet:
DIN5 to TRS 5 = tip 2 = shield 4 = ring
100nF 50V 0805 X7R K 47uF 50V 1210 X7R K MIDI Out: UART TX. MIDI In: UART RX.
Audio TRS shield = gnd ring = right tip = left

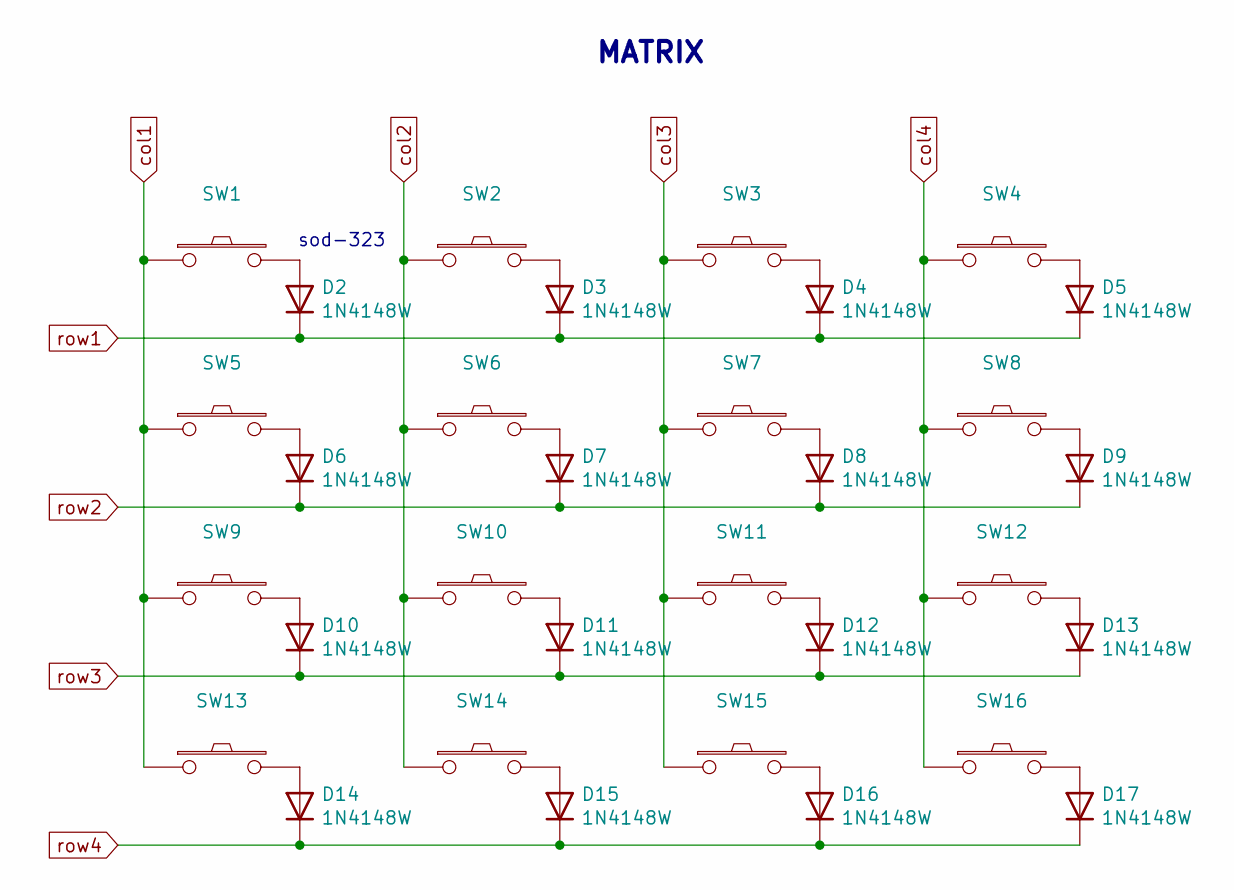
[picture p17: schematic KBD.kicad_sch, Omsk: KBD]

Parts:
D2, D3, D4, D5, D6, D7, D8, D9, D10, D11, D12, D13, D14, D15, D16, D17: 1N4148W; D_SOD-323_1side
SW1, SW2, SW3, SW4, SW5, SW6, SW7, SW8, SW9, SW10, SW11, SW12, SW13, SW14, SW15, SW16: SW_PUSH; SW_choc12_hotswap

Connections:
unnamed: D2.2 (A), SW1.2
unnamed: D3.2 (A), SW2.2
unnamed: D4.2 (A), SW3.2
unnamed: D5.2 (A), SW4.2
unnamed: D6.2 (A), SW5.2
unnamed: D7.2 (A), SW6.2
unnamed: D8.2 (A), SW7.2
unnamed: D9.2 (A), SW8.2
unnamed: D10.2 (A), SW9.2
unnamed: D11.2 (A), SW10.2
unnamed: D12.2 (A), SW11.2
unnamed: D13.2 (A), SW12.2
unnamed: D14.2 (A), SW13.2
unnamed: D15.2 (A), SW14.2
unnamed: D16.2 (A), SW15.2
unnamed: D17.2 (A), SW16.2
col1: SW1.1, SW5.1, SW9.1, SW13.1; also elsewhere on the board
col2: SW2.1, SW6.1, SW10.1, SW14.1; also elsewhere on the board
col3: SW3.1, SW7.1, SW11.1, SW15.1; also elsewhere on the board
col4: SW4.1, SW8.1, SW12.1, SW16.1; also elsewhere on the board
row1: D2.1 (K), D3.1 (K), D4.1 (K), D5.1 (K); also elsewhere on the board
row2: D6.1 (K), D7.1 (K), D8.1 (K), D9.1 (K); also elsewhere on the board
row3: D10.1 (K), D11.1 (K), D12.1 (K), D13.1 (K); also elsewhere on the board
row4: D14.1 (K), D15.1 (K), D16.1 (K), D17.1 (K); also elsewhere on the board

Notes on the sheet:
sod-323
MATRIX

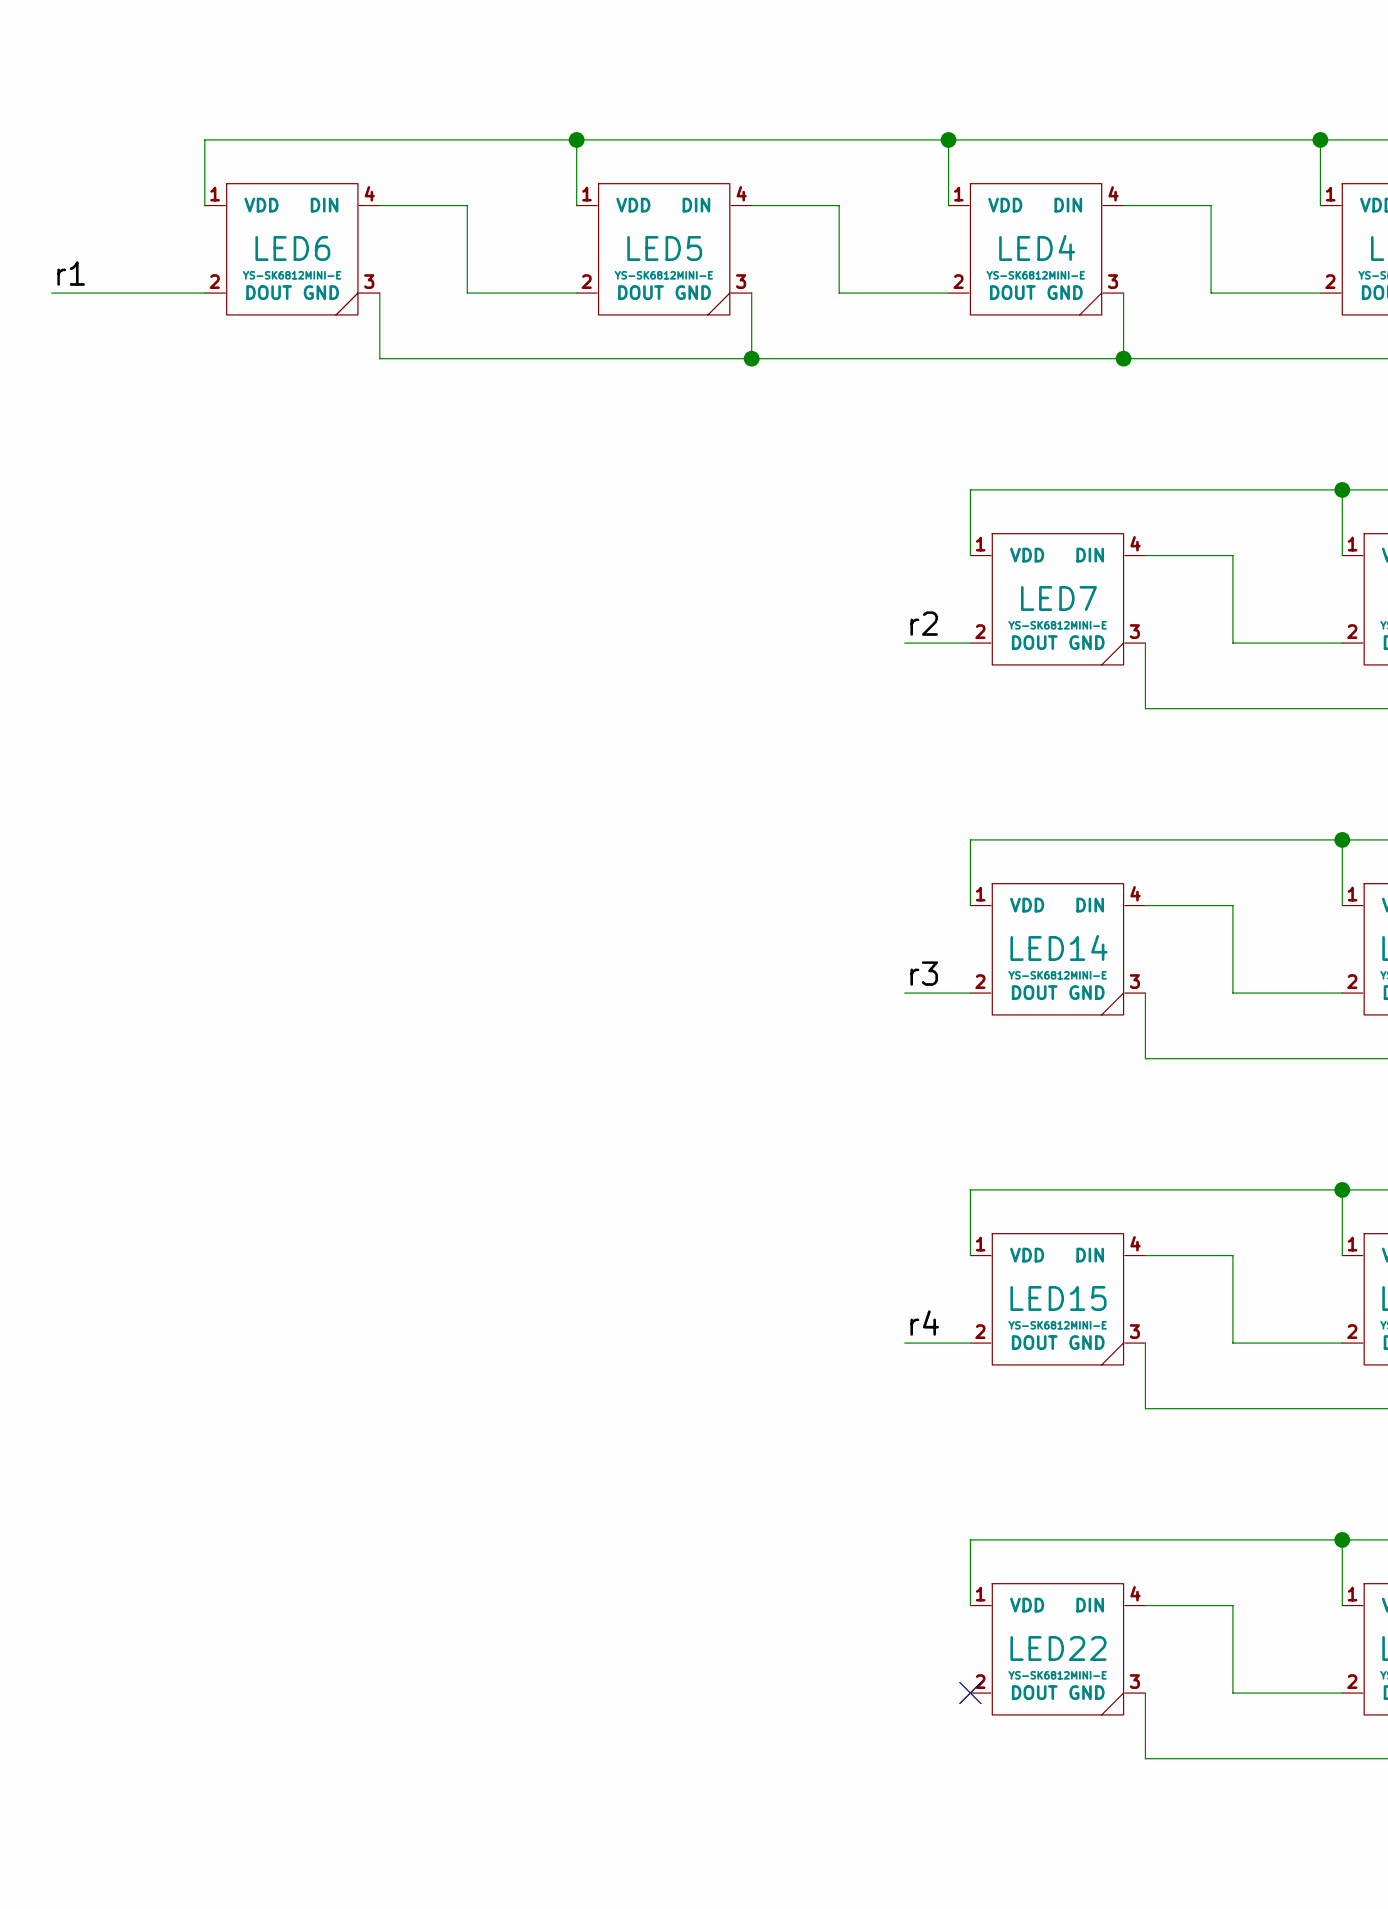
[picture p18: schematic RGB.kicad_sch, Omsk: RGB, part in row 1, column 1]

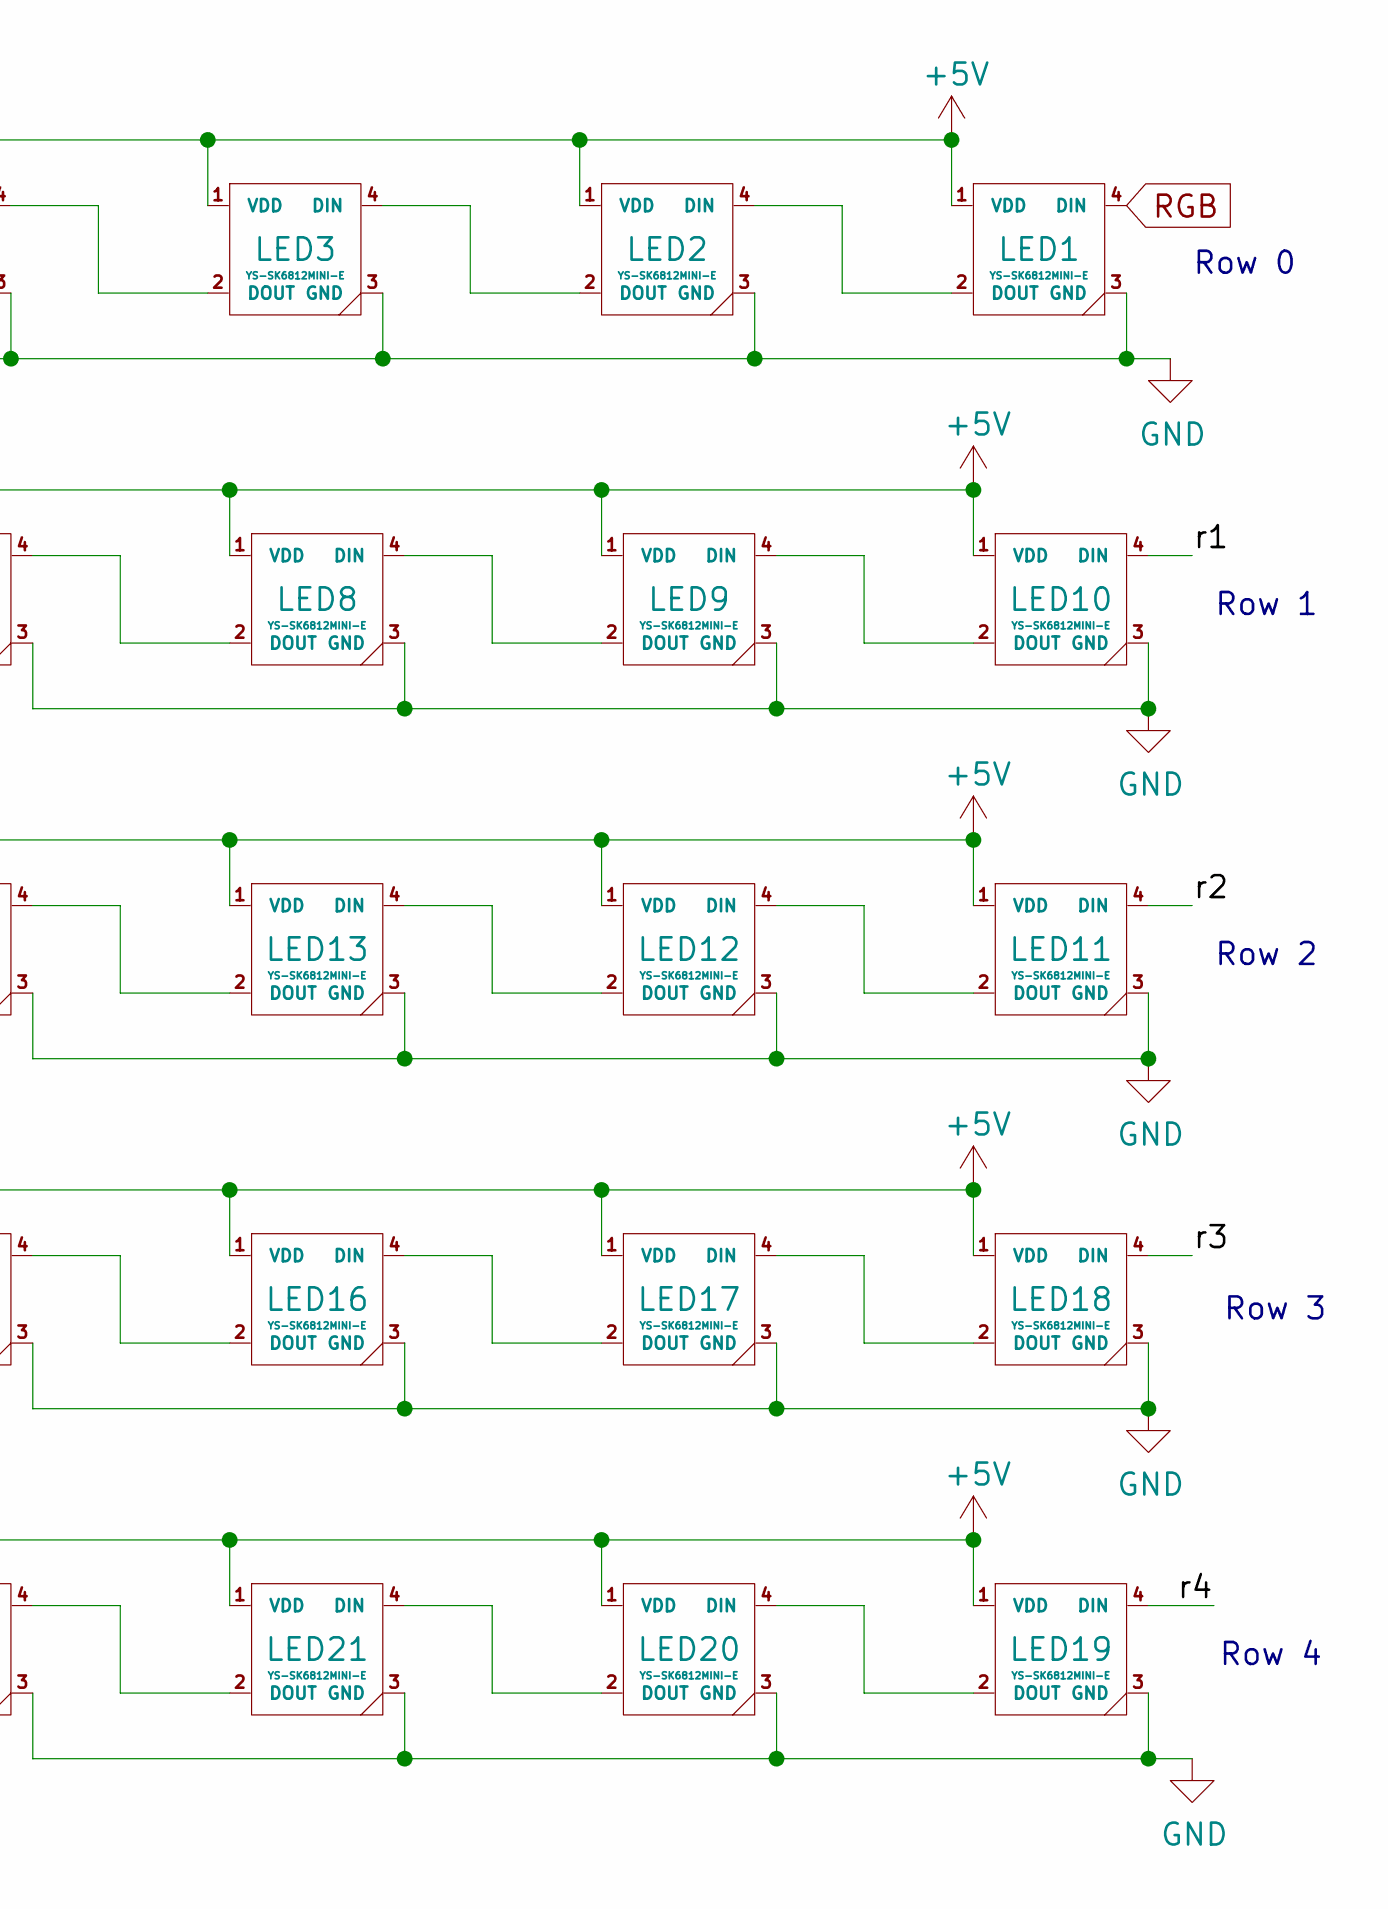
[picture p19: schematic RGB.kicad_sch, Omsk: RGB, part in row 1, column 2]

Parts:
LED1, LED2, LED3, LED4, LED5, LED6, LED7, LED8, LED9, LED10, LED11, LED12, LED13, LED14, LED15, LED16, LED17, LED18, LED19, LED20, LED21, LED22: YS-SK6812MINI-E; LED_YS-SK6812MINI-E_1side

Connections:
+5V: LED1.1 (VDD), LED2.1 (VDD), LED3.1 (VDD), LED4.1 (VDD), LED5.1 (VDD), LED6.1 (VDD), LED7.1 (VDD), LED8.1 (VDD), LED9.1 (VDD), LED10.1 (VDD), LED11.1 (VDD), LED12.1 (VDD), LED13.1 (VDD), LED14.1 (VDD), LED15.1 (VDD), LED16.1 (VDD), LED17.1 (VDD), LED18.1 (VDD), LED19.1 (VDD), LED20.1 (VDD), LED21.1 (VDD), LED22.1 (VDD); also elsewhere on the board
/RGB/r1: LED6.2 (DOUT), LED10.4 (DIN)
/RGB/r2: LED7.2 (DOUT), LED11.4 (DIN)
/RGB/r3: LED14.2 (DOUT), LED18.4 (DIN)
/RGB/r4: LED15.2 (DOUT), LED19.4 (DIN)
GND: LED1.3 (GND), LED2.3 (GND), LED3.3 (GND), LED4.3 (GND), LED5.3 (GND), LED6.3 (GND), LED7.3 (GND), LED8.3 (GND), LED9.3 (GND), LED10.3 (GND), LED11.3 (GND), LED12.3 (GND), LED13.3 (GND), LED14.3 (GND), LED15.3 (GND), LED16.3 (GND), LED17.3 (GND), LED18.3 (GND), LED19.3 (GND), LED20.3 (GND), LED21.3 (GND), LED22.3 (GND); also elsewhere on the board
unnamed: LED1.2 (DOUT), LED2.4 (DIN)
unnamed: LED2.2 (DOUT), LED3.4 (DIN)
unnamed: LED3.2 (DOUT), LED4.4 (DIN)
unnamed: LED4.2 (DOUT), LED5.4 (DIN)
unnamed: LED5.2 (DOUT), LED6.4 (DIN)
unnamed: LED7.4 (DIN), LED8.2 (DOUT)
unnamed: LED8.4 (DIN), LED9.2 (DOUT)
unnamed: LED9.4 (DIN), LED10.2 (DOUT)
unnamed: LED11.2 (DOUT), LED12.4 (DIN)
unnamed: LED12.2 (DOUT), LED13.4 (DIN)
unnamed: LED13.2 (DOUT), LED14.4 (DIN)
unnamed: LED15.4 (DIN), LED16.2 (DOUT)
unnamed: LED16.4 (DIN), LED17.2 (DOUT)
unnamed: LED17.4 (DIN), LED18.2 (DOUT)
unnamed: LED19.2 (DOUT), LED20.4 (DIN)
unnamed: LED20.2 (DOUT), LED21.4 (DIN)
unnamed: LED21.2 (DOUT), LED22.4 (DIN)
RGB: LED1.4 (DIN); also elsewhere on the board

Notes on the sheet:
Row 2
Row 0
Row 1
Row 4
Row 3

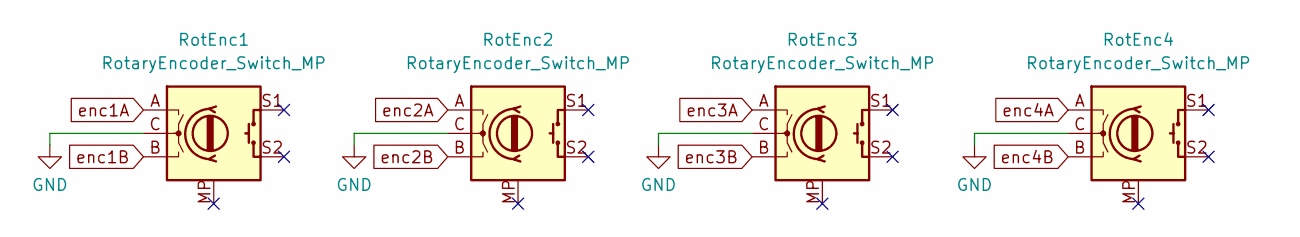
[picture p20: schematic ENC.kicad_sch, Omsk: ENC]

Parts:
RotEnc1, RotEnc2, RotEnc3, RotEnc4: RotaryEncoder_Switch_MP; RotEnc_Alps_EC12E-SWitch_Vertical_H20mm-without_SW

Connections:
GND: RotEnc1.C, RotEnc2.C, RotEnc3.C, RotEnc4.C; also elsewhere on the board
enc1A: RotEnc1.A; also elsewhere on the board
enc1B: RotEnc1.B; also elsewhere on the board
enc2A: RotEnc2.A; also elsewhere on the board
enc2B: RotEnc2.B; also elsewhere on the board
enc3A: RotEnc3.A; also elsewhere on the board
enc3B: RotEnc3.B; also elsewhere on the board
enc4A: RotEnc4.A; also elsewhere on the board
enc4B: RotEnc4.B; also elsewhere on the board

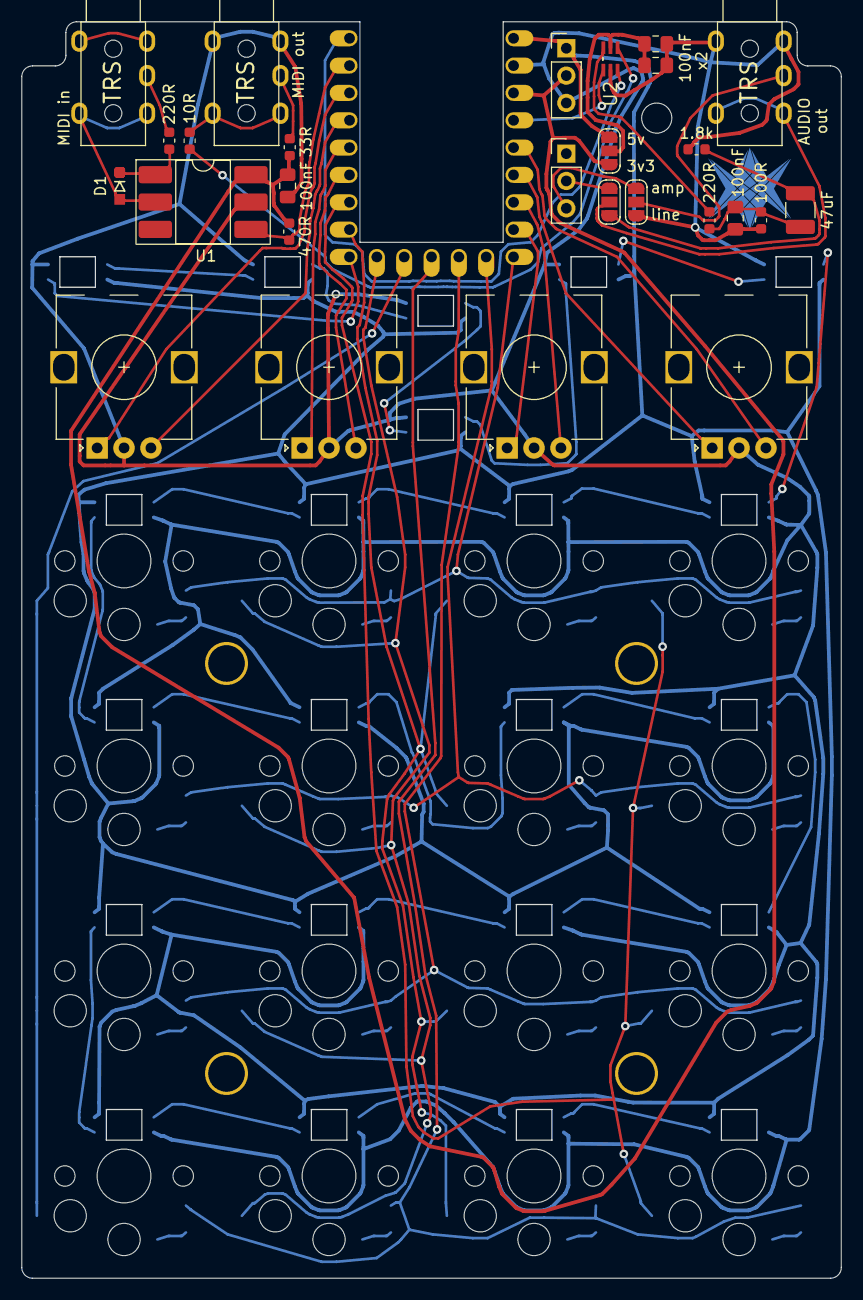
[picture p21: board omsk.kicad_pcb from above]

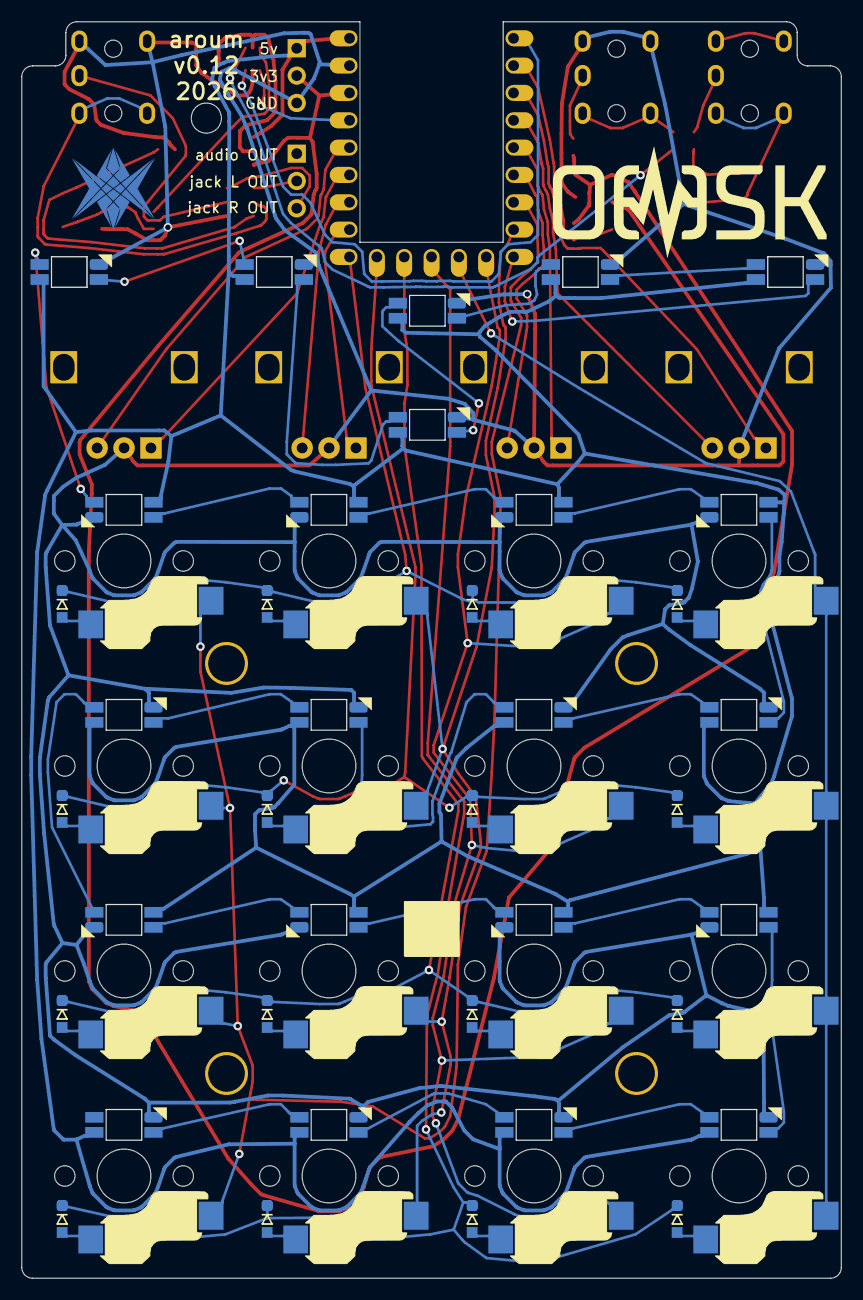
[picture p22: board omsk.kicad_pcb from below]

Board: 2 copper layers, 76.1 x 116.7 mm, 88 parts (44 on the bottom side), 74 nets.

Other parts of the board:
G1, G43: LOGO

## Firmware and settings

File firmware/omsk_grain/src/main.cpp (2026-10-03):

#include <stdio.h>
#include <string.h>
#include <math.h>
#include "pico/stdlib.h"
#include "pico/multicore.h"
#include "hardware/clocks.h"
#include "hardware/gpio.h"
#include "hardware/irq.h"
#include "hardware/pwm.h"
#include "hardware/pio.h"
#include "hardware/timer.h"
#include "hardware/i2c.h"
#include "tusb.h"
#include "usb/usb_midi.h"
#include "midi_uart.h"

#include "sw_config.h"
#include "synth/synth.h"
#include "ui/ui_state.h"
#include "ui/ui_oled.h"
#include "leds/leds.h"
#include "midi/midi_map.h"
#include "midi_helpers.h"
#include "tables/audio_data_wrapper.h"
#include "matrix.h"
#include "encoders.h"


// PIO Headers
#include "audio.pio.h"
#include "i2s_tx.pio.h"

// =============================================================================
// GLOBAL STATE
// =============================================================================

Synth synth;
UIState ui;
u8g2_t u8g2;

static uint64_t last_activity_ms = 0;
bool is_sleeping = false;

void update_activity() {
    last_activity_ms = to_ms_since_boot(get_absolute_time());
    if (is_sleeping) {
        is_sleeping = false;
        u8g2_SetPowerSave(&u8g2, 0); // Wake up OLED
    }
}

#define AUDIO_BLOCK_SIZE 64
float audio_out_l[AUDIO_BLOCK_SIZE];
float audio_out_r[AUDIO_BLOCK_SIZE];

// Ring buffer for audio (Core 1 -> Timer Interrupt)
#define RING_BUF_SIZE 1024
float ring_l[RING_BUF_SIZE];
float ring_r[RING_BUF_SIZE];
volatile uint32_t ring_write = 0;
volatile uint32_t ring_read = 0;

#ifdef AUDIO_OUT_DAC
static PIO i2s_pio = pio0;
static uint i2s_sm = 0;
#endif

// =============================================================================
// U8G2 PICO I2C CALLBACKS
// =============================================================================

uint8_t u8x8_byte_pico_i2c(u8x8_t *u8x8, uint8_t msg, uint8_t arg_int, void *arg_ptr) {
    static uint8_t buffer[32];
    static uint8_t buf_idx;
    switch (msg) {
        case U8X8_MSG_BYTE_SEND:
            if (buf_idx + arg_int < 32) {
                memcpy(buffer + buf_idx, arg_ptr, arg_int);
                buf_idx += arg_int;
            }
            break;
        case U8X8_MSG_BYTE_INIT:
            break;
        case U8X8_MSG_BYTE_SET_DC:
            break;
        case U8X8_MSG_BYTE_START_TRANSFER:
            buf_idx = 0;
            break;
        case U8X8_MSG_BYTE_END_TRANSFER:
            i2c_write_blocking(OLED_I2C, u8x8_GetI2CAddress(u8x8) >> 1, buffer, buf_idx, false);
            break;
        default:
            return 0;
    }
    return 1;
}

uint8_t u8x8_gpio_and_delay_pico(u8x8_t *u8x8, uint8_t msg, uint8_t arg_int, void *arg_ptr) {
    switch (msg) {
        case U8X8_MSG_DELAY_100NANO:
            __asm volatile("nop");
            break;
        case U8X8_MSG_DELAY_10MICRO:
            sleep_us(10);
            break;
        case U8X8_MSG_DELAY_MILLI:
            sleep_ms(arg_int);
            break;
        default:
            return 0;
    }
    return 1;
}

// =============================================================================
// AUDIO OUTPUT: PWM with Oversampling & Wrap ISR / DAC
// =============================================================================

#ifdef AUDIO_OUT_PWM
static uint pwm_slice_l;
static uint pwm_slice_r;
static volatile uint8_t pwm8_current_l = 128;
static volatile uint8_t pwm8_current_r = 128;
static volatile uint8_t pwm8_repeat = 0;
static const uint8_t PWM8_REPEAT_DIV = 8;

static void __not_in_flash_func(pwm_wrap_isr)(void) {
    pwm_clear_irq(pwm_slice_l);
    pwm_set_gpio_level(PIN_AUDIO_PWM_L, pwm8_current_l);
    pwm_set_gpio_level(PIN_AUDIO_PWM_R, pwm8_current_r);
    pwm8_repeat++;
    if (pwm8_repeat >= PWM8_REPEAT_DIV) {
        pwm8_repeat = 0;
        if (ring_read != ring_write) {
            float fl = ring_l[ring_read];
            float fr = ring_r[ring_read];
            ring_read = (ring_read + 1) % RING_BUF_SIZE;
            
            // Map floating point [-1.0, 1.0] to 8-bit [0, 255]
            int32_t il = (int32_t)((fl + 1.0f) * 127.5f);
            int32_t ir = (int32_t)((fr + 1.0f) * 127.5f);
            if (il < 0) il = 0; if (il > 255) il = 255;
            if (ir < 0) ir = 0; if (ir > 255) ir = 255;
            pwm8_current_l = (uint8_t)il;
            pwm8_current_r = (uint8_t)ir;
        } else {
            pwm8_current_l = 128;
            pwm8_current_r = 128;
        }
    }
}
#endif

#ifdef AUDIO_OUT_DAC
bool audio_timer_callback(repeating_timer_t *rt) {
    if (ring_read != ring_write) {
        float fl = ring_l[ring_read];
        float fr = ring_r[ring_read];
        ring_read = (ring_read + 1) % RING_BUF_SIZE;
        
        // 16-bit signed I2S: map -1..1 to -32768..32767
        int16_t sl = (int16_t)(fl * 32767.0f);
        int16_t sr = (int16_t)(fr * 32767.0f);
        
        // Pack into 32-bit: Left in upper 16, Right in lower 16
        uint32_t val = ((uint32_t)(uint16_t)sl << 16) | (uint16_t)sr;
        if (!pio_sm_is_tx_fifo_full(i2s_pio, i2s_sm)) {
            pio_sm_put(i2s_pio, i2s_sm, val);
        }
    } else {
        if (!pio_sm_is_tx_fifo_full(i2s_pio, i2s_sm)) {
            pio_sm_put(i2s_pio, i2s_sm, 0);
        }
    }
    return true;
}
#endif

static void init_audio_output() {
#ifdef AUDIO_OUT_PWM
    // Initialize PWM pins
    gpio_set_function(PIN_AUDIO_PWM_L, GPIO_FUNC_PWM);
    gpio_set_function(PIN_AUDIO_PWM_R, GPIO_FUNC_PWM);
    
    pwm_slice_l = pwm_gpio_to_slice_num(PIN_AUDIO_PWM_L);
    pwm_slice_r = pwm_gpio_to_slice_num(PIN_AUDIO_PWM_R);
    
    pwm_config config = pwm_get_default_config();
    pwm_config_set_wrap(&config, 255); // 8-bit resolution
    
    // Set clock divisor for 8x oversampling
    uint32_t sys_hz = clock_get_hz(clk_sys);
    float clkdiv = (float)sys_hz / (256.0f * ((float)SAMPLE_RATE * (float)PWM8_REPEAT_DIV));
    if (clkdiv < 1.0f) clkdiv = 1.0f;
    pwm_config_set_clkdiv(&config, clkdiv);
    
    pwm_init(pwm_slice_l, &config, true);
    pwm_init(pwm_slice_r, &config, true);
    
    // Set midpoint initially
    pwm_set_gpio_level(PIN_AUDIO_PWM_L, 128);
    pwm_set_gpio_level(PIN_AUDIO_PWM_R, 128);
    
    // Setup Wrap Interrupt for slice L (it drives both channels)
    pwm_clear_irq(pwm_slice_l);
    pwm_set_irq_enabled(pwm_slice_l, true);
    irq_set_exclusive_handler(PWM_IRQ_WRAP, pwm_wrap_isr);
    irq_set_enabled(PWM_IRQ_WRAP, true);
#endif

#ifdef AUDIO_OUT_DAC
    // Initialize I2S PIO
    int sm = pio_claim_unused_sm(i2s_pio, false);
    if (sm < 0) {
        i2s_pio = pio1;
        sm = pio_claim_unused_sm(i2s_pio, true);
    }
    i2s_sm = (uint)sm;

    uint offset = pio_add_program(i2s_pio, &i2s_tx_program);
    i2s_tx_program_init(i2s_pio, i2s_sm, offset, PIN_DAC_I2S_DATA, PIN_DAC_I2S_BCK, SAMPLE_RATE);

    // Start audio timer interrupt (DAC only)
    static repeating_timer_t timer;
    add_repeating_timer_us(-(1000000 / SAMPLE_RATE), audio_timer_callback, NULL, &timer);
#endif
}

// =============================================================================
// HARDWARE INITIALIZATION
// =============================================================================

static void init_clocks_overclock() {
    set_sys_clock_khz(CFG_OVERCLOCK_KHZ, true);
}

static void init_i2c_oled() {
    i2c_init(OLED_I2C, 400 * 1000);
    gpio_set_function(PIN_OLED_SDA, GPIO_FUNC_I2C);
    gpio_set_function(PIN_OLED_SCL, GPIO_FUNC_I2C);
    gpio_pull_up(PIN_OLED_SDA);
    gpio_pull_up(PIN_OLED_SCL);

#if CFG_OLED_TYPE == 1
    u8g2_Setup_sh1107_i2c_64x128_f(&u8g2, U8G2_R1, u8x8_byte_pico_i2c, u8x8_gpio_and_delay_pico);
#else
#ifdef OLED_FLIP
    u8g2_Setup_ssd1312_i2c_128x64_noname_f(&u8g2, U8G2_R2, u8x8_byte_pico_i2c, u8x8_gpio_and_delay_pico);
#else
    u8g2_Setup_ssd1312_i2c_128x64_noname_f(&u8g2, U8G2_R0, u8x8_byte_pico_i2c, u8x8_gpio_and_delay_pico);
#endif
#endif
    oled_init(&u8g2);
}



// =============================================================================
// USB MIDI & INPUT SCANNING
static int current_midi_channel() {
    return synth.get_voice(0)->p.midi_ch;
}
// =============================================================================

static uint8_t midi_note_to_voice[128]; 

static void handle_midi_message(uint8_t status, uint8_t data1, uint8_t data2) {
    update_activity();
    uint8_t type = status & 0xF0;
    
    // Apply channel filtering
    if (type >= 0x80 && type <= 0xEF) {
        int ch = (status & 0x0F) + 1;
        int active_ch = current_midi_channel();
        if (active_ch != 0 && active_ch != ch) return;
    }

    if (type == 0xB0) {
        uint8_t cc  = data1;
        uint8_t val = data2;
        
        // Handle Modwheel and Sustain directly
        if (cc == 1) {
            for (int v = 0; v < NUM_VOICES; v++) {
                synth.get_voice(v)->modwheel_val = (float)val / 127.0f;
            }
        } else if (cc == 64) {
    bool sustain = (val >= 64);
    for (int v = 0; v < NUM_VOICES; v++) {
        synth.get_voice(v)->sustain_active = sustain;
        if (!sustain && synth.get_voice(v)->is_sustained) {
            synth.get_voice(v)->is_sustained = false;
            if (synth.get_voice(v)->current_note == -1) {
                ui.voices_triggered[v] = false;
                synth.get_voice(v)->set_trigger(false);
            }
        }
    }
} else if (cc == 32) {
            synth.preset_load(val);
            return;
        } else if (cc == 33) {
            synth.preset_save(val);
            return;
        }

        // Check if it's a trigger button CC (BTN_TRIG1..4)
        if (cc >= MIDI_CC_BTN_ROW4_COL1 && cc <= MIDI_CC_BTN_ROW4_COL4) {
            if (val >= 64) oled_notify_trigger_activity();
        } else {
            oled_notify_encoder_activity();
        }

        if (midi_map_process(&ui, synth.get_voice(0), cc, val)) {
            for (int v = 0; v < NUM_VOICES; v++) {
                synth.get_voice(v)->set_trigger(ui.voices_triggered[v]);
            }
        }
    } else if (type == 0x90 && data2 > 0) {
        uint8_t note = data1;
        int voice_mode = synth.get_voice(0)->p.midi_mode; // 0=V1, 1=V2, 2=V3, 3=V4, 4=RR, 5=RND, 6=OCT
        int voice_idx = -1;

        if (voice_mode >= 0 && voice_mode <= 3) {
            // Monophonic modes V1-V4: Route note strictly to specific voice
            voice_idx = voice_mode;
        } else if (voice_mode == 4) {
            // RR mode: Round Robin cyclic allocation across 4 voices
            static int rr_counter = 0;
            voice_idx = rr_counter;
            rr_counter = (rr_counter + 1) % NUM_VOICES;
        } else if (voice_mode == 5) {
            // RND mode: Randomly select among currently free voices
            int free_voices[NUM_VOICES];
            int free_count = 0;
            for (int v = 0; v < NUM_VOICES; v++) {
                if (!ui.voices_triggered[v]) {
                    free_voices[free_count++] = v;
                }
            }
            if (free_count > 0) {
                voice_idx = free_voices[rand() % free_count];
            } else {
                voice_idx = rand() % NUM_VOICES;
            }
        } else if (voice_mode == 6) {
            // OCT mode: Voice assigned by MIDI note octave number
            int oct = note / 12; // 1=oct1, 2=oct2, 3=oct3, 4=oct4
            if (oct >= 1 && oct <= 4) {
                voice_idx = oct - 1;
            } else {
                voice_idx = -1; // Ignore notes outside octaves 1-4
            }
        }

        if (voice_idx >= 0 && voice_idx < NUM_VOICES) {
            // Clear any previous mapping to this voice to avoid note-off leaks
            for (int i = 0; i < 128; i++) {
                if (midi_note_to_voice[i] == voice_idx) {
                    midi_note_to_voice[i] = 0xFF;
                }
            }
            midi_note_to_voice[note & 127] = (uint8_t)voice_idx;
            ui.voices_triggered[voice_idx] = true;
            synth.get_voice(voice_idx)->set_trigger(true);
            synth.get_voice(voice_idx)->current_note = note;
            synth.get_voice(voice_idx)->is_sustained = false; // Reset sustain state on Note On
            oled_notify_trigger_activity(); // Note On switches to GRAIN
        }
    } else if (type == 0x80 || (type == 0x90 && data2 == 0)) {
        uint8_t note = data1;
        uint8_t v = midi_note_to_voice[note & 127];
        if (v < NUM_VOICES) {
            // Only release the voice if the released note is the active note on that voice
            if (synth.get_voice(v)->current_note == note) {
                if (synth.get_voice(v)->sustain_active) {
                    synth.get_voice(v)->is_sustained = true;
                    synth.get_voice(v)->current_note = -1;
                } else {
                    ui.voices_triggered[v] = false;
                    synth.get_voice(v)->set_trigger(false);
                    synth.get_voice(v)->current_note = -1;
                }
            }
            midi_note_to_voice[note & 127] = 0xFF;
        }
    } else if (type == 0xE0) {
        // Pitch Bend (data1 is LSB, data2 is MSB)
        float semitones = midi_pitch_bend_to_semitones(data1, data2, 2.0f); // Default range +/- 2 semitones
        for (int v = 0; v < NUM_VOICES; v++) {
            synth.get_voice(v)->pitch_bend_semitones = semitones;
        }
    } else if (type == 0xD0) {
        // Channel Pressure / Aftertouch (data1 is pressure)
        float aftertouch = (float)(data1 & 0x7F) / 127.0f;
        for (int v = 0; v < NUM_VOICES; v++) {
            synth.get_voice(v)->aftertouch_val = aftertouch;
        }
    }

}

static void send_usb_midi(uint8_t status, uint8_t data1, uint8_t data2) {
    if (tud_midi_mounted()) {
        uint8_t packet[4];
        packet[0] = (status >> 4); // Cable 0, CIN matching status high nibble
        packet[1] = status;
        packet[2] = data1;
        packet[3] = data2;
        tud_midi_packet_write(packet);
    }
}

static void process_usb_midi() {
    while (tud_midi_available()) {
        uint8_t packet[4];
        if (!tud_midi_packet_read(packet)) break;
        handle_midi_message(packet[1], packet[2], packet[3]);
#ifdef MIDI_THRU
        // Forward USB MIDI to UART MIDI Out
        midi_uart_write_byte(packet[1]);
        uint8_t cmd = packet[1] & 0xF0;
        if (cmd == 0xC0 || cmd == 0xD0) {
            midi_uart_write_byte(packet[2]);
        } else if (cmd >= 0x80 && cmd <= 0xEF) {
            midi_uart_write_byte(packet[2]);
            midi_uart_write_byte(packet[3]);
        }
#endif
    }
}

static void init_uart_midi() {
    midi_uart_init();
}

static void process_uart_midi() {
    static uint8_t midi_state = 0; // 0: Idle, 1: Expecting 1 byte, 2: Expecting 2 bytes
    static uint8_t midi_buf[3];
    static uint8_t midi_buf_idx = 0;
    static uint8_t current_status = 0;

    uint8_t byte;
    while (midi_uart_read_byte(&byte)) {
#ifdef MIDI_THRU
        // Hardware MIDI Thru: echo RX byte to TX
        midi_uart_write_byte(byte);
#endif
        
        if (byte >= 0x80) {
            if (byte >= 0xF0) {
                // System common/realtime messages (we can ignore for simplicity or reset)
                midi_state = 0;
                continue;
            }
            current_status = byte;
            midi_buf[0] = byte;
            midi_buf_idx = 1;
            uint8_t cmd = byte & 0xF0;
            if (cmd == 0xC0 || cmd == 0xD0) {
                midi_state = 1;
            } else {
                midi_state = 2;
            }
        } else {
            if (midi_state > 0 && current_status != 0) {
                midi_buf[midi_buf_idx++] = byte;
                if (midi_buf_idx == (midi_state + 1)) {
                    uint8_t data2 = (midi_state == 2) ? midi_buf[2] : 0;
                    handle_midi_message(midi_buf[0], midi_buf[1], data2);
#ifdef MIDI_THRU
                    // Duplicate incoming Jack MIDI to USB MIDI Out
                    send_usb_midi(midi_buf[0], midi_buf[1], data2);
#endif
                    
                    // Support running status (re-use status byte)
                    midi_buf_idx = 1;
                }
            }
        }
    }
}

static bool matrix_prev[16] = {false};

static void process_matrix() {
    scan_matrix();

    for (int i = 0; i < 16; i++) {
        if (matrix_debounced[i] != matrix_prev[i]) {
            update_activity();
            int ch = current_midi_channel();
            if (ch == 0) ch = 1;
            uint8_t cc_status = 0xB0 | ((ch - 1) & 0x0F);
            uint8_t note_status_on = 0x90 | ((ch - 1) & 0x0F);
            uint8_t note_status_off = 0x80 | ((ch - 1) & 0x0F);

            if (matrix_debounced[i]) {
                ui_on_button_press(&ui, (ButtonId)i);

                // Trig buttons (BTN_TRIG1=12 to BTN_TRIG4=15)
                if (i >= 12 && i <= 15) {
                    int v = i - 12;
                    int note = 24 + v * 12; // C1=24, C2=36, C3=48, C4=60
                    synth.get_voice(v)->current_note = note;
                    send_usb_midi(note_status_on, note, 127);
                    midi_uart_write_byte(note_status_on);
                    midi_uart_write_byte(note);
                    midi_uart_write_byte(127);
                    oled_notify_trigger_activity();
                } else {
                    send_usb_midi(cc_status, 40 + i, 127);
                    midi_uart_write_byte(cc_status);
                    midi_uart_write_byte(40 + i);
                    midi_uart_write_byte(127);
                    oled_notify_encoder_activity();
                }
            } else {
                ui_on_button_release(&ui, (ButtonId)i);

                if (i >= 12 && i <= 15) {
                    int v = i - 12;
                    int note = 24 + v * 12;
                    synth.get_voice(v)->current_note = -1;
                    send_usb_midi(note_status_off, note, 0);
                    midi_uart_write_byte(note_status_off);
                    midi_uart_write_byte(note);
                    midi_uart_write_byte(0);
                } else {
                    send_usb_midi(cc_status, 40 + i, 0);
                    midi_uart_write_byte(cc_status);
                    midi_uart_write_byte(40 + i);
                    midi_uart_write_byte(0);
                }
            }
            matrix_prev[i] = matrix_debounced[i];
            for (int v = 0; v < NUM_VOICES; v++) {
                synth.get_voice(v)->set_trigger(ui.voices_triggered[v]);
            }
        }
    }
}

static void process_encoders() {
    scan_encoders();
    for (int e = 0; e < 4; e++) {
        int delta = encoders_get_delta(e);
        if (delta != 0) {
            update_activity();
            oled_notify_encoder_activity();
            midi_map_process(&ui, synth.get_voice(0), ENC_CC_MAP[e], delta > 0 ? 65 : 63);
        }
    }
}

bool encoder_timer_callback(repeating_timer_t *rt) {
    process_encoders();
    return true;
}

// =============================================================================
// CORE 1: Audio processing loop
// =============================================================================

void core1_entry() {
    while (true) {
        synth.process(AUDIO_BLOCK_SIZE, audio_out_l, audio_out_r);
        for (int i = 0; i < AUDIO_BLOCK_SIZE; i++) {
            // Push to ring buffer, wait if full
            uint32_t next_write = (ring_write + 1) % RING_BUF_SIZE;
            while (next_write == ring_read) tight_loop_contents();
            
            ring_l[ring_write] = audio_out_l[i];
            ring_r[ring_write] = audio_out_r[i];
            ring_write = next_write;
        }
    }
}

int main() {
    init_clocks_overclock();
    usb_midi_init();
    stdio_init_all();

    init_matrix();
    init_encoders();
    init_i2c_oled();
    init_audio_output();
    init_uart_midi();
    leds_init();

    synth.init();
    synth.preset_load(0);
    ui_state_init(&ui);
    memset(midi_note_to_voice, 0xFF, sizeof(midi_note_to_voice));

    for (int v = 0; v < NUM_VOICES; v++) {
        synth.get_voice(v)->set_trigger(ui.voices_triggered[v]);
    }

    multicore_launch_core1(core1_entry);

    // Start encoder timer interrupt (every 1 ms / 1000 Hz)
    static repeating_timer_t enc_timer;
    add_repeating_timer_ms(-1, encoder_timer_callback, NULL, &enc_timer);

    last_activity_ms = to_ms_since_boot(get_absolute_time());

    uint32_t last_oled_refresh = 0;
    uint32_t last_led_update = 0;
    while (true) {
        usb_midi_task();
        process_usb_midi();
        process_uart_midi();
        process_matrix();

        uint32_t now_ms = to_ms_since_boot(get_absolute_time());
#if defined(CFG_SLEEP_TIMEOUT_MIN) && CFG_SLEEP_TIMEOUT_MIN > 0
        if (!is_sleeping && (now_ms - last_activity_ms) > (uint32_t)CFG_SLEEP_TIMEOUT_MIN * 60 * 1000) {
            is_sleeping = true;
            u8g2_SetPowerSave(&u8g2, 1); // Turn off OLED
        }
#endif

        uint32_t now = time_us_32();
        if (!is_sleeping && (now - last_oled_refresh > 33333)) {
            oled_render(&u8g2, &ui, synth.get_voice(0), NUM_VOICES);
            last_oled_refresh = now;
        } else if (is_sleeping) {
            last_oled_refresh = now;
        }

        if (now - last_led_update > 16666) {
            leds_show();
            last_led_update = now;
        }
    }
    return 0;
}

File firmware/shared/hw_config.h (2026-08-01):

#ifndef HW_CONFIG_H
#define HW_CONFIG_H

#include <stdint.h>

// =============================================================================
// KEYBOARD MATRIX
// =============================================================================

#define PIN_MATRIX_COL1 10
#define PIN_MATRIX_COL2 9
#define PIN_MATRIX_COL3 7
#define PIN_MATRIX_COL4 6

#define PIN_MATRIX_ROW1 14
#define PIN_MATRIX_ROW2 13
#define PIN_MATRIX_ROW3 12
#define PIN_MATRIX_ROW4 11

// =============================================================================
// ENCODERS
// =============================================================================

#define PIN_ENCODER1_A 2
#define PIN_ENCODER1_B 3
#define PIN_ENCODER2_A 4
#define PIN_ENCODER2_B 5
#define PIN_ENCODER3_A 15
#define PIN_ENCODER3_B 26
#define PIN_ENCODER4_A 27
#define PIN_ENCODER4_B 28

#define ENCODER_RESOLUTION 4

// =============================================================================
// AUDIO OUTPUT PINS
// =============================================================================
// PWM Audio pins (Pin 29 L, Pin 21 R as per schematic)
#define PIN_AUDIO_PWM_L 29
#define PIN_AUDIO_PWM_R 16

// I2S DAC pins
#define PIN_DAC_I2S_BCK 17
#define PIN_DAC_I2S_LRCK 18
#define PIN_DAC_I2S_DATA 19

// =============================================================================
// DISPLAY PINS
// =============================================================================
// DISPLAY TYPE SELECTION
// 0 = SSD1312 128x64 (Standard horizontal screen)
// 1 = SH1107 64x128 (Turtle vertical screen)
#ifndef CFG_OLED_TYPE
#define CFG_OLED_TYPE 0
#endif

#define PIN_OLED_SCL 21
#define PIN_OLED_SDA 20 
#define OLED_I2C i2c0
#define OLED_FLIP
#define OLED_BRIGHTNESS_PERCENT 15

// =============================================================================
// RGB LED PINS
// =============================================================================

#define PIN_RGB_LED 8
#define NUM_RGB_LEDS 22 //  7-22 led per switch; 0-6 additional leds
#define RGB_MAX_BRIGHTNESS 63

// RGB LED Indices
#define LED_ENCODER_1 0
#define LED_ENCODER_2 1
#define LED_MODE_1    2
#define LED_MODE_2    3
#define LED_ENCODER_3 4
#define LED_ENCODER_4 5

// Array mapping matrix button index to the physical LED index in the WS2812 strip
static const uint8_t MATRIX_LED_MAP[16] = {
    9, 8, 7, 6,       // Row 0
    10, 11, 12, 13,   // Row 1
    17, 16, 15, 14,   // Row 2
    18, 19, 20, 21    // Row 3
};

// =============================================================================
// MIDI JACKS (Serial MIDI)
// =============================================================================
#define PIN_MIDI_JACK_OUT 0
#define PIN_MIDI_JACK_IN 1
#define MIDI_THRU

// =============================================================================
// DEBOUNCE
// =============================================================================
#define DEBOUNCE_TIME_MS 10

// =============================================================================
// SYSTEM
// =============================================================================
#ifdef PICO_RP2040
#define CFG_OVERCLOCK_KHZ 133000 // Safer for USB than 133MHz
#else
#define CFG_OVERCLOCK_KHZ 240000 // RP2350
#endif

#endif // HW_CONFIG_H

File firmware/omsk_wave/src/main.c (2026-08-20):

#include "sw_config.h"
#include "hardware/clocks.h"
#include "hardware/uart.h"
#include "pico/stdlib.h"
#include "pico/time.h"
#include "synth/audio.h"
#include <math.h>
#include <stdio.h>
#include <stdlib.h>
#include <string.h>
#include "tables/omsk_wavetables.h"
#if CFG_ENABLE_USB_MIDI
#include "tusb.h"
#endif
void usb_midi_init(void);
void usb_midi_task(void);
#include "../../shared/hardware/matrix.h"
#include "../../shared/hardware/encoders.h"
#include "../../shared/hardware/colors.h"
#include "leds/leds.h"
#include "midi/midi_map.h"
#include "synth/pra_synth.h"
#include "synth/synth.h"
#include "ui/ui_oled.h"
#include "ui/ui_state.h"

extern volatile uint32_t pra_synth_sample_count;

static void system_overclock_if_enabled(void) {
#if CFG_ENABLE_OVERCLOCK
#if PICO_RP2040
  set_sys_clock_khz(CFG_OVERCLOCK_RP2040_KHZ, true);
#elif PICO_RP2350
  set_sys_clock_khz(CFG_OVERCLOCK_RP2350_KHZ, true);
#endif
#endif
}

#include "midi/midi_handler.h"

// --- Globals ---
#include "ui/ui_logic.h"

#if CFG_SLEEP_TIMEOUT_MIN > 0
static uint32_t last_activity_time_ms = 0;
static bool is_sleeping = false;

void update_activity(void) {
  if (is_sleeping) {
    is_sleeping = false;
    ui_oled_set_power(true);
  }
  last_activity_time_ms = to_ms_since_boot(get_absolute_time());
}
#endif

int main() {
  system_overclock_if_enabled();
  stdio_init_all();

  init_matrix();
  init_encoders();
  leds_init();
  audio_init();
  synth_init();
  audio_start();
  midi_init();
  midi_map_init();
#if CFG_ENABLE_SEQUENCER
#include "sequencer/sequencer.h"
  seq_init();
#endif
#if CFG_ENABLE_USB
  usb_midi_init();
#endif

  // Send initial modulation matrix state for emulator sync
  for (int p = 0; p < PARAM_COUNT; p++) {
    for (int s = 0; s < SRC_COUNT; s++) {
      if (params.mod_matrix[p][s] != 0) {
        // Determine target module and index
        // This is a bit tedious, but we can just loop through common modules
        // Or simplified: just log that source S is active for P
        int8_t depth = (int8_t)params.mod_matrix[p][s] - 64;
        if (depth != 0) {
          DBG_PRINTF("MOD_INIT %d %d %d\n", p, s, (int)params.mod_matrix[p][s]);
        }
      }
    }
  }

  // Init Active Notes
  for (int i = 0; i < 16; i++)
    active_notes[i] = -1;
  for (int i = 0; i < 16; i++) {
    preset_hold_start[i] = 0;
    preset_hold_used[i] = false;
  }

  ui_mode = UI_MODE_PIANO;
  selected_module = MOD_VCO1;
  target_module = MOD_VCO1;
  
  // Initialize critical parameters to safe defaults
  params.vco1_transpose = 5; // 0 oct
  params.vco2_transpose = 5; // 0 oct
  params.vco1_wave = 0;
  params.vco2_wave = 0;
  params.arp_mode = 0;
  params.arp_rate = 12; // 1/16
  params.arp_oct = 3;   // 0 oct shift
  params.amp_gain = 100; // Default master volume
  
  // Push initial values to synth engine
  pra_synth_param_change(PARAM_VCO1_TRANSPOSE, params.vco1_transpose);
  pra_synth_param_change(PARAM_VCO2_TRANSPOSE, params.vco2_transpose);
  pra_synth_param_change(PARAM_VCO1_WAVE, params.vco1_wave);
  pra_synth_param_change(PARAM_VCO2_WAVE, params.vco2_wave);
  pra_synth_param_change(PARAM_ARP_MODE, params.arp_mode);
  pra_synth_param_change(PARAM_ARP_RATE, params.arp_rate);
  pra_synth_param_change(PARAM_ARP_OCT, params.arp_oct);
  pra_synth_param_change(PARAM_AMP_GAIN, params.amp_gain);

  ui_set_status("VCO1", 2000);

  uint32_t last_scan = 0;
  uint32_t last_debug = 0;

  // Send welcome packet for emulator
  printf("STEPATENO_OLED_READY\n");

  // Start OLED after other systems
  // (Moved to loop for delayed init)

  uint32_t startup_time = time_us_32();
  bool oled_initialized = false;

  while (1) {
    uint32_t now = time_us_32();

#if CFG_SLEEP_TIMEOUT_MIN > 0
    if (!is_sleeping) {
      uint32_t now_ms = to_ms_since_boot(get_absolute_time());
      if (now_ms - last_activity_time_ms > (CFG_SLEEP_TIMEOUT_MIN * 60 * 1000)) {
        is_sleeping = true;
        ui_oled_set_power(false);
      }
    }
#endif

    // Delayed OLED Init: wait 0.5 seconds after boot
#if CFG_ENABLE_OLED
    if (!oled_initialized && (now - startup_time > 500000)) {
#if 0
      // Turn board cyan to indicate OLED Init attempt
      leds_set_all(0, 255, 255);
      leds_show();

      ui_oled_init();
      oled_initialized = true;

      // Turn board green to indicate OLED Init success
      leds_set_all(0, 255, 0);
      leds_show();
#else
      ui_oled_init();
      oled_initialized = true;
#endif
    }
#endif

    if (now - last_debug > 1000000) {
      last_debug = now;
    }

    midi_poll();
    
    // Update control at ~1kHz (every 1ms) to reduce mutex contention with Core 1
    static uint32_t last_control_update = 0;
    if (now - last_control_update > 1000) {
      last_control_update = now;
      pra_synth_update_control(); // Core 0 handle envelopes, LFOs, and MIDI commands
    }

#if CFG_ENABLE_SEQUENCER
    seq_poll();
#endif
#if CFG_ENABLE_USB
    usb_midi_task();
#endif
#if CFG_ENABLE_USB_MIDI
    uint8_t buf[64];
    int n;
    while ((n = tud_midi_stream_read(buf, sizeof(buf))) > 0) {
      for (int i = 0; i < n; i++) {
        midi_process_byte(buf[i]);
      }
    }
#endif

    // 1. Encoders
    scan_encoders();
    int d1 = encoders_get_delta(0);
    int d2 = encoders_get_delta(1);
    int d3 = encoders_get_delta(2);
    int d4 = encoders_get_delta(3);
    int8_t ext_enc[8];
    midi_map_consume_encoder_deltas(ext_enc);
    d1 += ext_enc[0];
    d2 += ext_enc[1];
    d3 += ext_enc[2];
    d4 += ext_enc[3];

#if CFG_SLEEP_TIMEOUT_MIN > 0
    if (d1 || d2 || d3 || d4 || ext_enc[4] || ext_enc[5] || ext_enc[6] ||
        ext_enc[7]) {
      update_activity();
    }
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

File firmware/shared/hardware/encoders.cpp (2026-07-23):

#include "encoders.h"
#include "pico/stdlib.h"
#include "../hw_config.h"

static const uint ENC_A_PINS[4] = {PIN_ENCODER1_A, PIN_ENCODER2_A, PIN_ENCODER3_A, PIN_ENCODER4_A};
static const uint ENC_B_PINS[4] = {PIN_ENCODER1_B, PIN_ENCODER2_B, PIN_ENCODER3_B, PIN_ENCODER4_B};
static uint8_t enc_prev_states[4] = {0};

int8_t enc_positions[4] = {0};
static const int8_t encoder_states[] = {0, -1, 1, 0, 1, 0, 0, -1, -1, 0, 0, 1, 0, 1, -1, 0};

void init_encoders(void) {
    for (int e = 0; e < 4; e++) {
        gpio_init(ENC_A_PINS[e]);
        gpio_set_dir(ENC_A_PINS[e], GPIO_IN);
        gpio_pull_up(ENC_A_PINS[e]);

        gpio_init(ENC_B_PINS[e]);
        gpio_set_dir(ENC_B_PINS[e], GPIO_IN);
        gpio_pull_up(ENC_B_PINS[e]);

        enc_prev_states[e] = (gpio_get(ENC_A_PINS[e]) << 1) | gpio_get(ENC_B_PINS[e]);
        enc_positions[e] = 0;
    }
}

void scan_encoders(void) {
    for (int e = 0; e < 4; e++) {
        uint8_t current_state = (gpio_get(ENC_A_PINS[e]) << 1) | gpio_get(ENC_B_PINS[e]);
        if (current_state != enc_prev_states[e]) {
            uint8_t state_idx = (enc_prev_states[e] << 2) | current_state;
            int8_t movement = encoder_states[state_idx & 0x0F];
            enc_prev_states[e] = current_state;

            if (movement != 0) {
                enc_positions[e] += movement;
            }
        }
    }
}
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

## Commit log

2026-07-13 Skeleton like case for OMSK
    [bot-omsk-mc.step, infopanel-omsk-ledsvisible-mc.step, infopanel-omsk-rounded-mc.step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]
2026-07-15 Create README.md with BOM details
    Added a Bill of Materials (BOM) section with item details.
2026-07-15 refactor: move case files to hardware/case and update case README
    [bot-omsk-mc.step, infopanel-omsk-ledsvisible-mc.step, infopanel-omsk-rounded-mc.step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]
2026-07-17 Case CAD files
    [Omsk-ledsvisible.step, Omsk-rounded.step]
2026-07-17 Case with aligned knobs
2026-07-19 add BOM
2026-07-19 add KiCAD files and docs
    [ENC.kicad_sch, IO.kicad_sch, KBD.kicad_sch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]
2026-07-24 fix(ci): fetch pico-sdk directly via actions/checkout instead of non-existent setup-action
2026-07-25 feat(ci): build separate PWM and DAC binaries for firmware
2026-07-25 fix(omsk_grain): fallback to audio_data_stub.h when audio_data.h is missing
    [main.cpp, midi_map.cpp]
2026-07-25 feat(ci): add release job to automatically publish firmwares, case.zip and Gerber archive on release/tag
2026-07-30 Case ledsvisible fix, knobs fix
    [Omsk-ledsvisible.step, infopanel-omsk-ledsvisible-mc.step, knob-K-mc.step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]
2026-07-30 Tolerance changed to 0.2 mm
    [Omsk-ledsvisible.step, Omsk-rounded.step, bot-omsk-mc.step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]
2026-08-12 chore: add pcb tooling config and logo assets
2026-08-20 refactor(wave): remove unused PRA32 legacy tables, filters and temporary files
2026-10-03 docs(pcb): document SCK ground jumper for DAC module
2026-10-03 fix(build): pass audio and display definitions from cmake to compiler
    Forward CFG_ENABLE_DAC, CFG_ENABLE_PWM8_AUDIO, CFG_ENABLE_BETTER_PWM, AUDIO_OUT_DAC/PWM, and CFG_OLED_TYPE to compiler via target_compile_definitions across all firmware projects. Wrap config definitions in #ifndef to prevent header overrides during CI matrix builds.
    [main.cpp, sw_config.h]
2026-10-03 fix(fm): resolve I2S DAC multi-voice audio starvation and jitter
    - Implement a 16-buffer DMA ring buffer in audio.cpp for I2S DAC output
    - Output silence on buffer underflow to keep I2S BCK/LRCK stable and avoid DAC auto-mute
    - Move synth rendering functions to SRAM via __not_in_flash_func to eliminate Flash XIP stalls
    - Cache algorithm steps in stack memory to avoid Flash reads during operator synthesis
    - Only clear active block samples in fm_synth_render_block
    [audio.cpp]
2026-10-03 fix(wave): implement I2S DMA ring buffer and run synth loop in SRAM
    Port the 16-block DMA ring buffer architecture and silence-underflow handling to omsk_wave DAC mode, preventing PIO FIFO underruns and I2S clock stalls. Mark audio_core_entry and pra_synth_get_stereo with __not_in_flash_func to ensure consistent SRAM execution without flash cache contention.
